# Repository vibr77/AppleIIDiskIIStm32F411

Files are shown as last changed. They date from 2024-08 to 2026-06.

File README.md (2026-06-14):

# SmartDisk II — Apple II Floppy Emulator

**The Apple II floppy emulator that even copy protection can't tell apart.**

Swap a shelf of aging 5.25″ disks for a single SD card — without giving up an ounce of authenticity. SmartDisk II reproduces the exact timing and behaviour of a real DISK II and UNIDISK 3.5 drive, so your games load and run exactly as they did back in the day — protection schemes and all.

<p align="center">
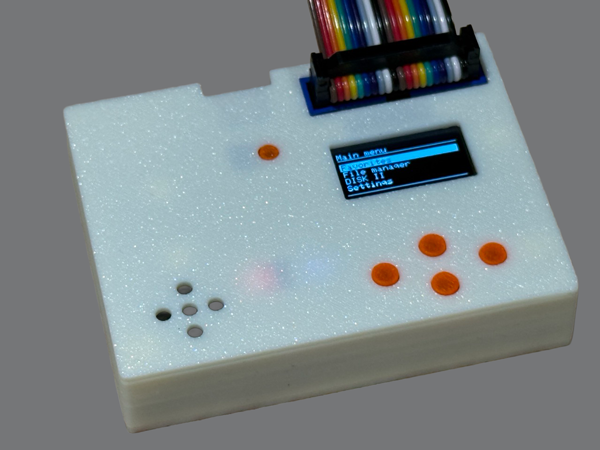
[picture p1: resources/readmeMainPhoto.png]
  
</p>

<p align="center">
  <a href="https://www.ebay.fr/itm/306883712221"><b>🛒 Buy a prebuilt board</b></a> ·
  <a href="https://github.com/vibr77/AppleIIDiskIIStm32F411"><b>🔧 Build it yourself</b></a> ·
  <a href="https://discord.gg/ZnzDqC2k"><b>💬 Join the Discord</b></a> ·
  <a href="https://www.r3tr0.net/index.php/smartdisk-ii-documentation/"><b>📖 Documentation</b></a>
</p>

---

## What is it

SmartDisk II is an **open-source hardware floppy-disk emulator for the Apple II**. It plugs into your machine like a real drive, reads disk images straight from an SD card, and lets you browse and mount them from a built-in OLED menu — no PC, no cables, no fuss.

Under the hood it's built on the **STM32F411 ("BlackPill")** and emulates the disk hardware *at the bit level*. That's the difference between *reading a disk image* and *being a disk drive* — and it's why SmartDisk II runs the titles other emulators choke on.

## Why SmartDisk II

- **Bit-perfect accuracy.** Timing is reproduced down to the microsecond, so the Apple II can't tell it apart from a mechanical drive.
- **It beats copy protection.** Fake bits, weak bits, half-tracks, SpiraDisc and more — it passes every scheme tested so far.
- **Your whole collection on one card.** Thousands of disks on a single SD card, browsable on the on-board OLED.
- **Works across the Apple II line.** From the II+ to the IIGS, Disk II and SmartPort — one device covers your fleet.
- **Read *and* write.** Save your progress and modify disks, not just load them.
- **Open source, or ready to run.** Build it from the published files, or order a prebuilt, flashed board and plug in today.

## Browse and boot — right from the Apple II

With **SmartLoader**, you don't even need the SmartDisk II's own buttons for everyday loading. It puts a fast green-screen browser on the Apple II itself: SmartLoader reads the disk images on your SD card and lists them right on screen, so you can scroll through your whole collection and boot any title straight from the Apple II — highlight a disk, press **[B]** to boot, **[R]** to refresh the listing, or **[S]** for settings.

## Copy protection that actually works

Most emulators fall over the moment a disk uses copy protection. SmartDisk II doesn't. By reproducing the original drive's bit-level timing, it satisfies the protection checks that real software relied on — so your original protected images run untouched.

| Copy protection | Status |
|:---|:---|
| Fat Track | ✅ Passed |
| Weak Bit | ✅ Passed |
| Cross-track synchronisation | ✅ Passed |
| Half Track | ✅ Passed |
| Data Latch | ✅ Passed |
| Timing Bits | ✅ Passed |
| E7 | ✅ Passed |
| Optimal Bit Timing (<4µs) | ✅ Passed |
| Various Bit Counter | ✅ Passed |
| SpiraDisc | ✅ Passed |

## Compatibility

| Apple II model | Emulation |
|:---|:---|
| II+ | Disk II |
| II Europlus | Disk II |
| IIe | Disk II |
| IIc (ROM 4) | Disk II + SmartPort |
| IIGS | Disk II + SmartPort |

SmartPort emulation is also available on the IIc (ROM 4.x), IIGS, and on the II+/IIe with a Liron or SoftSP6 card.

## Supported disk formats

| Format  | Read | Write |
|:---|:-----|:---|
| WOZ 2.0 | ✅ | ✅ |
| DSK | ✅ | ✅ |
| PO | ✅ | ✅ |
| 2MG | ✅ | ✅ |
| WOZ 1.0 | ✅ | — |
| NIC | ✅ | — |

## Features at a glance

- **Three drives in one** — DISK II 5.25″, SmartPort HD, and UNIDISK 3.5 emulation
- **On-board navigation** — browse, mount and unmount images from the 0.96″ OLED with four buttons
- **Big images, no sweat** — 32 MB images and full Total Replay collections run smoothly
- **Modern software too** — loads GS/OS on the IIGS; runs titles like Arkanoid from 2MG
- **SmartLoader** built in — browse and boot from the Apple II screen itself
- **Actively developed** — frequent firmware releases with the latest improvements

## See it in action

- ▶ [Total Replay & 32 MB images, running smoothly](https://www.youtube.com/watch?v=Sws6IjnWDGQ)
- ▶ [Arkanoid, loaded from a 2MG image](https://www.youtube.com/watch?v=U3N-gej0NLk)
- ▶ [Loading GS/OS on the IIGS](https://www.youtube.com/watch?v=gZH2njO4CEQ)

## Get your SmartDisk II

**Buy a prebuilt board.** Don't want to solder? Order a ready-to-use, fully flashed and tested SmartDisk II and plug in today → [Order on eBay](https://www.ebay.fr/itm/306883712221)

**Build it yourself.** Everything you need is open source — KiCad PCB, Gerber files, bill of materials, 3D-printable case, firmware releases and full source code. **Current production board: Revision 8**, recommended for self-builds.

**Get help & follow along.** Join the community on [Discord](https://discord.gg/6y2Zdazy), or read the full development story on [AppleFritter](https://www.applefritter.com/content/apple-ii-disk-emulator-using-stm32).

## Tech specs

- **MCU:** STM32F411 ("BlackPill") — chosen for CPU speed, >60 kB SRAM and 4-bit SDIO
- **Storage:** SD card, FAT32 (4-bit SDIO for speed) — a quality, known-brand card is recommended
- **Display:** 0.96″ OLED (SSD1306) with four-button navigation
- **Board:** Production Revision 8, fully tested
- **Licence:** open source for non-commercial use with attribution

<p align="center">
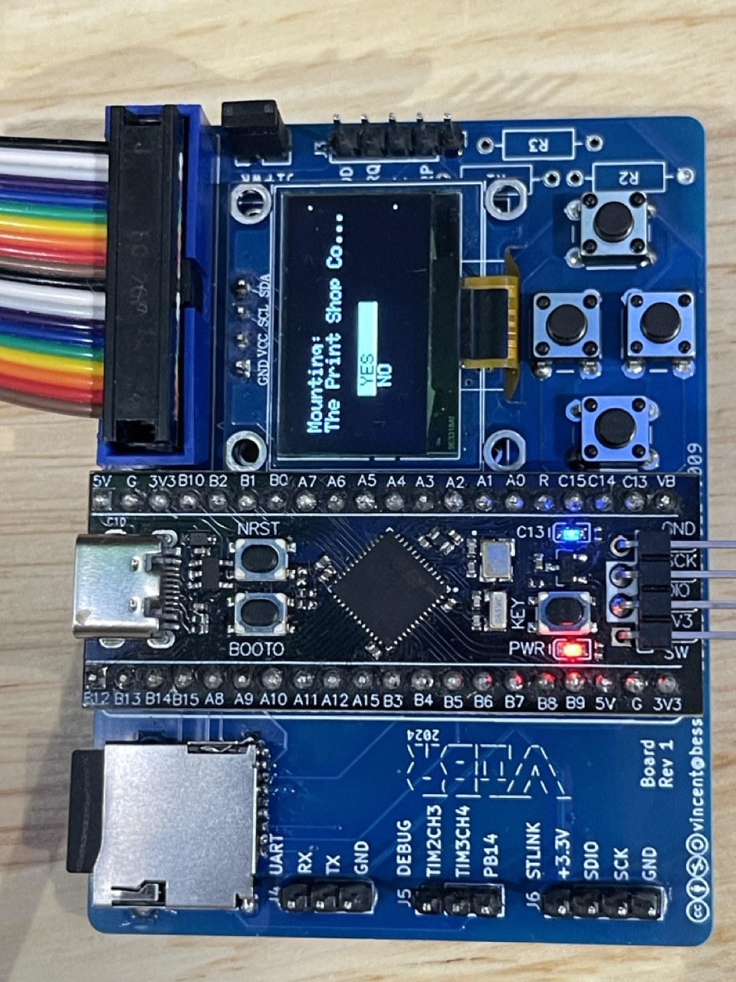
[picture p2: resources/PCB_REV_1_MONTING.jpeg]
  
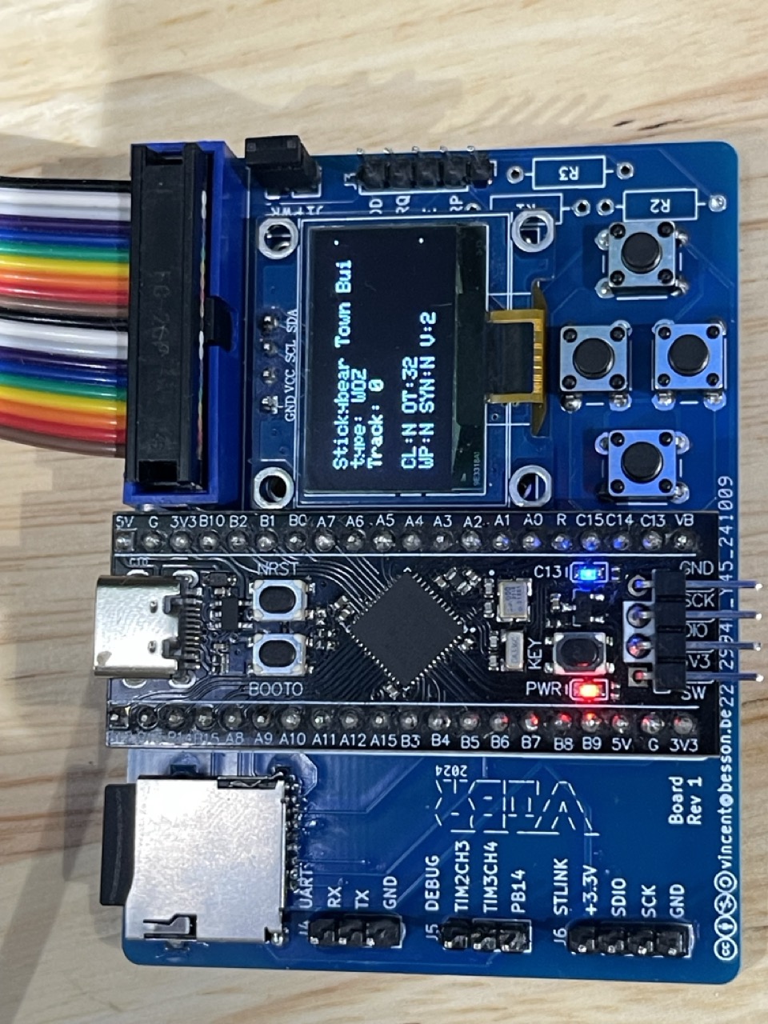
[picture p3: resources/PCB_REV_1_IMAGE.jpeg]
  
</p>

---

# Build & developer guide

Everything below is for people building, flashing, or hacking on the SmartDisk II. The full end-user manual (wiring, SD-card prep, menu walkthrough) lives in the [online documentation](https://www.r3tr0.net/index.php/smartdisk-ii-documentation/).

## Firmware

The latest firmware (see the releases on the right-hand side of the GitHub page) requires **bootloader v0.14 or v0.16**. Version 0.15 is **not** compatible and causes issues with the IIGS SmartPort. It is recommended to update the bootloader to the latest version.

There are two release types:

- **BIN** — classic binary, uploaded via ST-Link, starting at `0x08000000`.
- **UF2** — first upload the custom bootloader via ST-Link, then connect USB and double-click the NRST button to drag-and-drop the UF2 release onto the STM32. **Warning:** with the bootloader, flash from `0x08000000` to `0x08100000` becomes read-only (use ST-Link tooling to change the STM32 register to reverse this).

## Project structure

| Directory | Description |
|:---|:---|
| `./hardware` | KiCad project |
| `./hardware/gerber`  | Gerber release to produce the PCB |
| `./hardware/bom` | Bill of materials |
| `./core` | Firmware source code |
| `./bootloader` | Bootloader |
| `./Middleware` | Libraries used |
| `./FATFS` | FATFS wrapper |
| `./doc` | Documentation used as reference |
| `./3DPrintCase` | 3D-print files & Fusion 360 source for the case |

## SD card

The SD card must use a **FAT32 file system with 64 sectors of 512 bytes each per cluster (32 KB clusters)**.

To format the card under Linux:

```bash
mkfs.fat -F 32 -s 64 /dev/sdX
```

Windows 10/11 does **not** format the card the right way. A config-menu option is provided directly on the SmartDisk II to format the SD card correctly. Note that some SD cards have very poor read/write rates — use a known brand to avoid wasting your time.

## Important notes

- The ST-Link programmer should **never** be connected at the same time as either USB or the Apple II — its voltage regulator is fragile.
- The **J1 PWR** jumper (top-right of the PCB) enables +5 V from the Apple II to the STM32.
- OLED screen: be careful of the power-pin order; some versions have the pins inverted.
- R1, R2, R3 are not needed.
- Before hardware Rev 3, the board is not compatible with the IIGS & IIc — the trace between IDC pins 5 & 7 needs to be cut.
- Hardware design may evolve; new software releases might not work with older hardware revisions.

## Hardware design principles

The STM32F4x is preferred over the STM32F1 for CPU frequency, available SRAM (>60 kB), and (on the F411) SDIO. Timing is critical on this project, especially to pass copy protection.

A DISK II floppy track is about 50,000 bits, and shifting from one track to another must respect specific timing rules. After many design iterations, the chosen approach loads a **single track in memory** and uses the **4-bit SDIO port** for SD card read/write speed — avoiding adjacent-track management and complex buffer copies.

The Apple II expects data at a precise pace of **1 bit every 4 µs (32 × 125 ns)**. Three options were considered:

1. SDIO with DMA — frees the CPU, but SPI sends 8 bits at a time; WOZ tracks aren't 8-bit aligned, which introduces bit misalignment and corrupted data on protected images.
2. Assembly with CPU-cycle counting & GPIO bit-banging — poor reliability, discarded.
3. **Timer-interrupt-triggered GPIO bit-banging (chosen)** — frees CPU time for OLED updates and button handling, makes fake-bit/protection mechanisms easy to address, and allows fine timing control (e.g. 3.8 µs vs 4 µs that some games use).

The write process mirrors the read process with a dedicated timer overflowing every 4 µs; polarity inversion is handled in software with an XOR rather than external circuitry.

### STM32 pin mapping

**Head-positioning stepper (external interrupts):**
`PA0` STEP0 / ExtI0 · `PA1` STEP1 / ExtI1 · `PA2` STEP2 / ExtI2 · `PA3` STEP3 / ExtI3

**Other GPIO:**
`PB8` SELECT (ExtI8, HIGH on Disk II controller — A2 powered on) · `PB9` WR Request (ExtI9, active LOW when writing) · `PA4` Device Enable (ExtI4, active LOW) · `PB2` WR Protect · `PA7` WR Data · `PB0` RD Data · `PA11` _DISK3.5

**Buttons (ExtI 9-15, TIM4 debounce):**
`PC13` BTN_DOWN · `PC14` BTN_UP · `PC15` BTN_ENTR · `PB12` BTN_RET

**SD card (SDIO, clock ÷2):**
`PB4` D0 · `PA8` D1 · `PA9` D2 · `PB5` D3 · `PA6` CMD · `PB15` CK

**OLED SSD1306 (I²C):** `PB6` SCL · `PB7` SDA

**UART:** `PA15` TX · `PB3` RX

**Timers:**
- **TIM2** — manages WR_DATA; ETR1 slave-reset mode resyncs with the Apple II write pulse (3.958 µs instead of 4 µs) on every rising edge.
- **TIM3** — manages RD_DATA.
- **TIM4** — internal (no PWM), debouncer for the control buttons.

## Software design principles

Built on:

- STM32 HAL drivers from STMicro
- FATFS 0.15 (note: STM32CubeMX overrides to 0.11)
- cJSON for the configuration file (tweaked to work with FATFS)
- SSD1306 library with DMA

Maximum track size is `13 × 512 × 8 = 53,248` bits (6,656 bytes), held in `DMA_BIT_TX_BUFFER[6656]`. `weakBitTank` (uint8 array) and `fakeBitTank` (char array) manage copy-protection mechanisms.

**Key functions:**

- `TIM3_IRQHandler` — bit-bangs the GPIO to send track data every 4 µs (or less, per WOZ config) to the Apple II.
- `TIM2_IRQHandler` — handles data sent from the Apple II for writing; uses a software XOR to detect polarity inversion and writes 1/0 to `DMA_BIT_RX_BUFFER`.
- `irqReadTrack` / `irqWriteTrack` — configure read/write interrupts.
- `getDataBlocksBareMetal(...)` / `setDataBlocksBareMetal(...)` — direct SDIO access to the SD card, faster than FATFS `f_open`. (FATFS is still required to build the file allocation table with correct block addresses.)
- `processDeviceEnableInterrupt` — activates/deactivates the Disk II drive on the DEVICE_ENABLE pin (active LOW).
- `processBtnInterrupt` — handles the four buttons.
- `processDiskHeadMoveInterrupt(...)` — handles the four stepper-motor GPIOs.
- `main()` — orchestrates program execution.

A **ST-Link** programmer is required to upload firmware to the STM32F411.

## Bill of materials

Interactive BOM: [SmartDisk II Bill of Material](https://vibr77.github.io/AppleIIDiskIIStm32F411/hardware/bom/ibom.html)

## Recommended reading

WOZ 2.1 & 1.0 image file references · Tome of Copy Protection · Beneath Apple DOS · Assembly Lines · Understanding the Apple II · PoC‖GTFO issues 10 & 11 · IIGS Firmware Reference · IIc Programmer's Guide to the 3.5 ROM (part 2)

## Licence

This project may be distributed, remixed, adapted and built upon, in any medium or format, **for non-commercial purposes only**, and only with attribution to the creator. Commercial rights are reserved to the author.

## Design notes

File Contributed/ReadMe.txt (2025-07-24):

### VIBR SmartDisk II - Apple II forever modification ###

https://youtube.com/shorts/TgZ5UqMbQsM

https://github.com/joergschne/AppleIIDiskIIStm32F411

https://developer.arm.com/downloads/-/arm-gnu-toolchain-downloads

export PATH="/Applications/ArmGNUToolchain/13.3.rel1/arm-none-eabi/bin:$PATH"

Download mandatory STM32F4xx driver at: https://www.st.com/en/development-tools/stm32cubemx.html

# Driver/BSP
# Driver/CMSIS
# Driver/STM32F4xx_HAL_Driver

Build with Apple II forever mode: make -f Makefile USE_BOOTLOADER=1 A2F_MODE=1 

# python uf2conv/uf2conv.py -b 0x08010000 -f STM32F4 -o build/AppleIISDiskII_stm32f411_sdio.uf2 build/AppleIISDiskII_stm32f411_sdio.bin

BOM:
https://shop.lcd-module.de/128x64-OLED-YELLOW/OLEDM128-6LGA
or
https://shop.lcd-module.de/OLED128x64green-COG/W128064-XALE

1	311-1344-1-ND			CC0603KRX7R9BB104	CAP CER 0.1UF 50V X7R 0603		1
2	478-1655-1-ND			TAJA106K016RNJ		CAP TANT 10UF 10% 16V 1206		3
3	732-2096-ND			61202021621		CONN HEADER VERT 20POS 2.54MM		2
4	296-SN74LS257BDRCT-ND		SN74LS257BDR		IC MULTIPLEXER 4 X 2:1 16SOIC		1
5	4809-RKJXT1F42001-ND		RKJXT1F42001		SWITCH JOYSTICK ANALOG 10MA 5V		1
6	664-GMC020080HRCT-ND		GMC020080HR		CONN SD/MMC/MS CARD R/A SMD		1
7	102-1266-1-ND	CT-1205H-SMT-TR	BUZZER MAGNETIC 5V 12.8X12.8 SMD				1
8	311-10KLGCT-ND	AC0805FR-0710KL	RES SMD 10K OHM 1% 1/8W 0805					12
9	13-AC0805FR-07910KLCT-ND	AC0805FR-07910KL	RES SMD 910K OHM 1% 1/8W 0805		1
10	P12937SCT-ND			EVQ-Q2F03W		SWITCH TACTILE SPST-NO 0.02A 15V	4
11	MICRO SD-CARD SMD		GCT-MEM2055-00-190-01-A_VIB					1
12	LED 5 mm
13	Buchsenleisten 2,54 mm
14	Flachbandkabel und 20P Pfosten-Steckverbinder
15	STM32F411 (Black Pill) Board

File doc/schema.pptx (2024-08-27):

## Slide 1

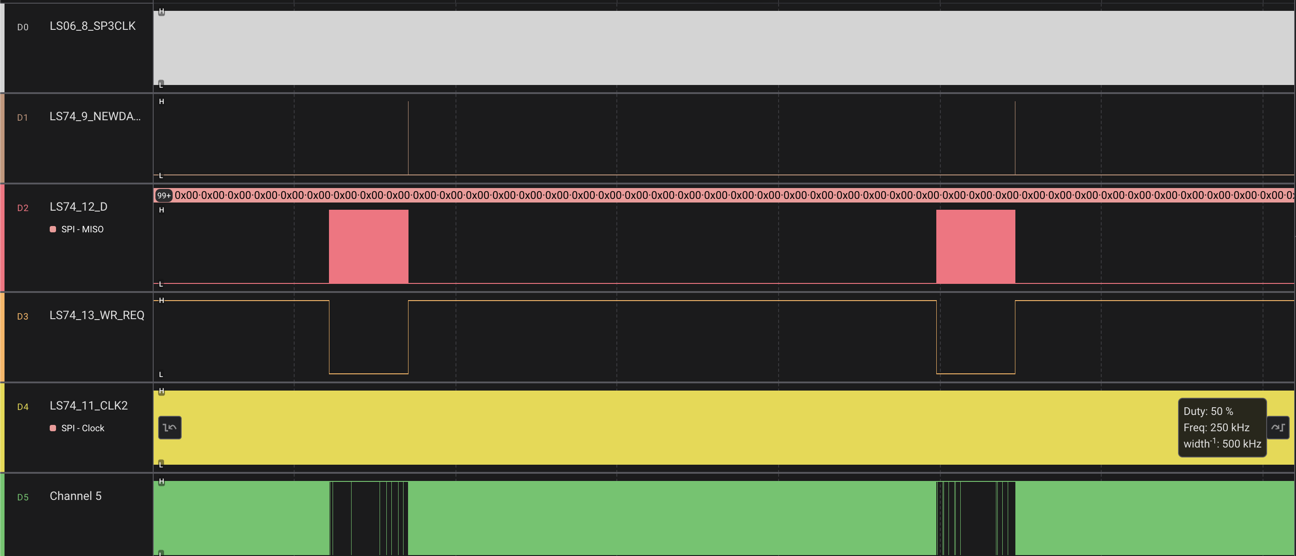
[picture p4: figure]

WRITE ZONE

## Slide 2

DMA CIRCULAR RDDATA BUFFER

DMA CIRCULAR WRDATA BUFFER

DESTINATION
Of WRDATA

B

A

WRDATA

C

D

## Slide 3

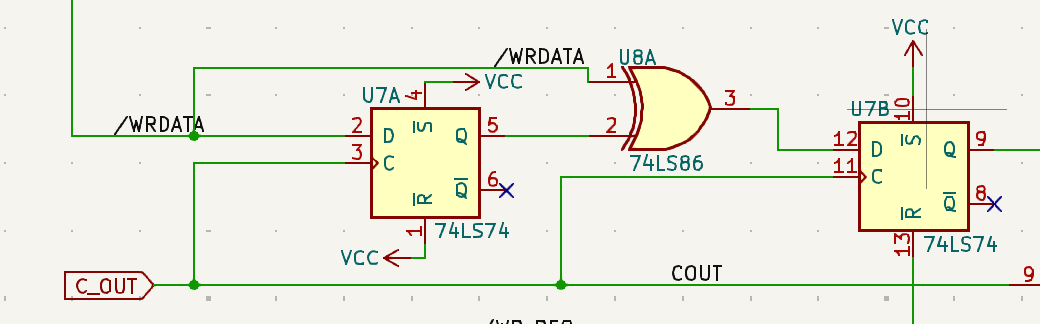
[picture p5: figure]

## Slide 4

Case A1: RX_E > RX_S && TX_E > TX_S

DMA_RX

0

RX_S

P1

RX_E

DMABSIZE

P1=memcpy(DMA_TX+TX_S,DMA_RX+RS_S,RX_LEN)

Case B2_1: RX_E < RX_S && TX_E < TX_S

RX

0

TX

0

RX_E

P3

RX_S

P1

A

P2

end_tx_len

DMABSIZE

end_tx_len=DMABSIZE-TX_E
P1=memcpy(DMA_TX+TX_S,DMA_RX+RX_S, end_tx_len)
Rx_offset=RX_S+ , end_tx_len
P2=memcpy(DMA_TX,DMA_RX+RX_offset,DMABSIZE-rx_offset)
Tx_offset=DMABSIZE-rx_offset
P3=memcpy(DMA_TX+tx_ofset,DMA_RX,RX_E)

DMA_TX

0

TX_S

P1

TX_E

DMABSIZE

P2

A

TX_E

P3

TX_S

P1

Case A2: RX_E>RX_S && TX_E < TX_S

RX

0

TX

0

RX_S

end_tx_len

P1

A

RX_E

end_tx_len=DMABSIZE-TX_S
P1=memcpy(DMA_TX+TX_S,DMA_RX+RX_S, end_tx_len)
P2=memcpy(DMA_TX,DMA_RX+end_tx_len, TX_S)

DMABSIZE

TX_E

P2

TX_S

P2

end_tx_len

P1

DMABSIZE

Case B2_2: RX_E < RX_S && TX_E < TX_S

RX

A

RX_E

RX_S

end_rx_len

P1

DMABSIZE

TX

0

P2

TX_E

P3

P3

TX_S

A

DMABSIZE

Case B1: RX_E < RX_S && TX_E < TX_S

RX

0

TX

0

RX_E

RX_S

end_rx_len

0

P1

P2

DMABSIZE

P2

P1

DMABSIZE

end_rx_len=DMABSIZE-RX_S
P1=memcpy(DMA_TX+TX_S,DMA_RX+RX_E, end_rx_len)
P2=memcpy(DMA_TX+TX_S+end_rx_len,DMA_RX, RX_E)

end_rx_len=DMABSIZE-RX_S
P1=memcpy(DMA_TX+TX_S,DMA_RX+RX_S, end_rx_len)
Tx_offset=DMA_TX+TX_S+end_rx_len
P2=memcpy(DMA_TX+tx_offset,DMA_RX,DMABSIZE-tx_offset)
Rx_offset=DMABSIZE-tx_offset
P3=memcpy(DMA_TX,DMA_RX+Rx_offset,RX_E)

TX_S

end_rx_len

P1

A

TX_E

P2

DMABSIZE

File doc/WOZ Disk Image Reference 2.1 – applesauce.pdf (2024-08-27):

ABOUT (https://applesaucefdc.com/what-is-applesauce/) | HARDWARE (https://applesaucefdc.com/hardware/) | SOFTWARE (https://applesaucefdc.com/software/) | DOCUMENTATION (https://wiki.applesaucefdc.com/) | A2R (https://applesaucefdc.com/a2r/) | WOZ (https://applesaucefdc.com/woz/) | MOOF (https://applesaucefdc.com/moof-reference/) | ORDER (https://applesaucefdc.com/order/) | CONTACT (https://applesaucefdc.com/contact/)

# WOZ Disk Image Reference 2.1

Created by John K. Morris
jmorris@evolutioninteractive.com

Version 2.1 – June 16, 2021

Version 1.0 of the WOZ Disk Image Reference can be found here. (https://applesaucefdc.com/woz/reference1/)

Many thanks to the people who helped me prepare this document for release:
John Brooks, David Brown, Bill Martens, Sean McNamara, Antoine Vignau, Olivier Galibert and 4am

## Why yet another Apple II disk image format?

This is probably the question many of you reading this document are asking. It basically comes down to the simple fact that none of the currently existing formats accurately represent the way data is encoded on an Apple II floppy disk. There is a place for a format that is an accurate representation of a bitstream that is also the exact length of a track so that it can be looped correctly. And since we are creating a format, it is also a great time to ensure that we organize the data in the image file in a way that allows for easy unpacking with as little memory and processing overhead as possible – this provides more performant usage in hardware and software emulators.

## What benefits come with using the WOZ format?

We seem to be doing just fine with the current file formats, why would we want to support the WOZ format? The big benefit is being able to successfully run copy protected software if you follow the emulation guidelines presented in this document. The second benefit is that the WOZ format is actually much simpler to implement than many of the other disk image formats. WOZ files also contain metadata about the disk image – such as disk name, product name, publisher, system requirements and language – that you can use to display additional information in your emulator.

## What has changed in the WOZ specification for the 2.1 release?

The 2.1 update has been created in order to support tracks that are captured at a level even lower than bits. It is now able to support flux transition timings with an accuracy of 125 nanoseconds. I refer to this as a flux stream. In order to support this additional type of data, a new FLUX chunk has been added along with a bump to the INFO chunk version (from 2 to 3) and 2 new fields (FLUX Block and Largest Flux Track). I expect that there will be very few disks that need to utilize this level of accuracy, but we have already discovered at least a dozen disks that need this for their copy protection to succeed. A description of how the flux data is encoded and stored in the TRKS chunk can be found in the TRKS section of this spec. There is also a new FLUX Chunk section that describes the new chunk type that was created in order to map flux-based track data to physical tracks (practically identical to the TMAP Chunk).

## What has changed in the WOZ specification for the 2.0 release?

After releasing Applesauce, the flood of software began that has enabled a lot of validation of the WOZ format. Unfortunately, a few short comings were uncovered with the initial format. There were also some requests made to improve the format. This document details the 2.x specification. The 2.0 format is intended to be a replacement of the 1.0 format.

File Header Changes

The file identifier (bytes 0-3 of the file) was changed from WOZ1 to WOZ2. This was done since there are a couple of fundamental changes made to the format and we need to make sure that new WOZ 2.0 files are only consumed by hardware and software that is explicitly compatible with these changes.

INFO Chunk Changes

New INFO fields are indicated by the “2” in the Vers field in the INFO Chunk section of this document.

There are now flags for indicating whether track 0 contains boot sectors for 16 and/or 13 sector hardware. The Apple disk controller card contains a ROM (P5) that performs the task of bootstrap loading track $00 sector $0 from the disk and running it. This is what happens when you reboot your machine or use PR#6. The code contained within that boot sector is then responsible for loading up the rest of the disk. When Apple originally came out with the Disk II, it only dealt with 13-sector disks and 5&3 nibble encoding. When you booted the computer, the P5 ROM would look for the boot sector by identifying an address prolog with the nibble values D5 AA B5. Later on, with DOS 3.3, Apple introduced the 16-sector format along with 6&2 nibble encoding. This new format also needed a revised P5 ROM, known as the P5A. Since the two formats aren’t compatible with each other, they chose to change the default address prolog nibbles to D5 AA 96. The problem with this is that disks in one format are basically invisible to disks and hardware using the other format since they aren’t looking for the correct address prolog. The WOZ format now contains a Boot Sector Format indicating whether a boot sector exists for 13 and/or 16 sector ROMs. This can help emulators detect which ROM is needed when booting a disk.

The Optimal Bit Timing is now provided. This value dictates the rate at which bits should be provided to the disk controller card. There are a several disks that use slightly non-standard bit timings. Most of these work just fine under emulation, but many of these disks load faster if the bits are provided at the correct speed. This value is in 125 nanosecond increments, so 8 is equal to 1 microsecond. And a standard bit rate for a 5.25 disk would be 32 (4µs), and a 3.5 would be 16 (2µs).

Another feature requested by emulator developers was to hoist some of the compatible hardware values from the META chunk and place it into the INFO chunk in an easier to parse format. So, there is now a Compatible Hardware bit field as well as a Required RAM one.

A Largest Track field was added in order to help emulators allocate a properly sized buffer for storing track data.

TMAP Chunk Changes

The order of the TMAP data for 3.5 disks has changed to make it more efficient to find the proper offset ((track << 1) + side). The TMAP chunk is unchanged for 5.25 disks.

TRKS Chunk Changes

It turns out that there was a trick that was more effective than I thought possible. Most 5.25 disks end up using about 6300-6500 bytes of data per track, but this all depends on the speed of the drive when writing the disk. I allocated 6646 bytes to each track to make sure there was a good pad in there for disks that were purposely written at a slower speed to pack more data on a track. It seems like some disks (I’m looking at you Datasoft) had things turned down even more and were able to fit an amazing 6680 bytes of data on a track. This broke the WOZ track size limit by 34 bytes.

The TRKS chunk was modified in order to allow a variable number of 512-byte blocks to be allocated for each track. This will allow the WOZ format to remain as small as possible for “normal” 5.25 disks, but also be able to accommodate ones with larger track data requirements. This also allows for more optimal storage for 3.5 disks as each speed zone can have the track size tuned for it.

The write hints have also been removed from the TRKS chunk and moved to their own WRIT chunk.

WRIT Chunk Addition

A new WRIT chunk has been added to the WOZ specification in order to provide detailed instructions for programs wanting to write WOZ files back to a real floppy disk. Inclusion of this chunk in a WOZ file is optional.

Freaking Out Like a MC3470 Changes

Due to some new findings in the analysis of MC3470, there is a new recommended implementation that should more accurately model the proper behavior.

## Implementation Details

Integrating WOZ support with your product is more than just loading data from a new type of container. It is also about how that data is used. Yes, it is possible to just shovel bits from the WOZ right into your bitstream, and many disk images will work just fine like that. But, by taking the following guidelines into account, your implementation will enable disk functionality that is also compatible with all copy protection schemes. Yes, this means you can run copy protected software in system and disk drive emulators without the need to crack it first!

Cross-Track Synchronization

When Steve Wozniak was hacking up Shugart drives to make the Disk II, one of the parts that he threw away was the sync sensor. The sync sensor involved a light source on one side of the disk with a sensor on the other. This sensor would allow the drive to know when it made a full revolution, as the disk media itself had a hole that would let the light pass though as it passed the sensor. It really wasn’t a necessary part for Wozniak’s soft-sectored design that was going to be used for storing data on the disk.

A NORMAL UNSYNCHRONIZED DISK VS A SYNCHRONIZED ONE.

When it came to businesses designing copy protection schemes, this was something that they could use to their advantage. The professional disk copiers could easily write out all tracks synchronized with each other, something that your average Apple II floppy drive couldn’t do. Then, the software would read a known sector on a specific track and, when it jumped to a neighboring track, it could make sure that the first sector it encountered there was the one it expected. Later protection schemes even made track widths which were almost 2 standard tracks wide and were accurate to within 1 bit. As much as the disk copy programs tried, they could only sync up tracks by sheer luck.

To circumvent these kind of copy protection checks, the WOZ format uses a Track Map (see the “TMAP Chunk” section below). This allows us to assign a track image to any number of quarter tracks on a disk. An entire disk could even be a single track if we wanted.

There are a couple of rules to follow with regards to changing tracks within the emulator:

Firstly, if the tracks you are changing between have matching values in the TMAP, then don’t change the track data. This will prevent any hiccups in the bitstream and can be a good performance gain to boot.

The second rule is that you need to maintain a bit pointer into your bitstream. You always need to know which bit you are on. When you do change tracks, you need to start the new bitstream at the same relative bitstream position – you cannot simply start the pointer at the beginning of the stream. You need to maintain the illusion of the head being over the same area of the disk, just shifted to a new track.

Also be sure to account for the fact that track lengths are inconsistent on a disk due to fluctuations in drive speed. Something like this works well to maintain the relative position if your environment can work with 32-bit or greater values:

new_position = current_position * new_track_length / current_track_length

Remember to maintain the bit position even when on an empty track (TMAP value of 0xFF). Since the empty track has no data, and therefore no length, using a fake length of 51,200 bits (6400 bytes) works very well.

Freaking Out Like a MC3470

On the Apple II, floppy disk data is written to the disk based on a 4µs clock. Whenever there is a 1 bit to write, the polarity of the magnetic flux under the drive head is transitioned from its current state to the opposite. If a zero needs to be written out, the 4µs clock is skipped (no transition occurs).

The MC3470 chip is the heart of the Apple II floppy drive. It reads the magnetic flux pattern off the disk and sends out a pulse for every flux transition it sees. This gives us back our 1 bits and our 0 bits come from the 4µs clock going by with no pulse.

One of the nice features of the MC3470 is that it has an internal amplification system to adapt to the varying magnetic strengths of each disk. If it has a hard time reading the disk, it can turn up its amp until it finds the signal. It allows the drive to read a wide assortment of disks. The Apple II uses GCR encoding to store bits on the disk. It is a very efficient system that was used widely on many platforms, because it doesn’t use clock bits to frame up your data bits, giving you more room to write data. This technique also has a drawback though, which is never being able to record more than two 0 bits in a row. It is why data on an Apple II is stored as nibbles instead of plain binary bytes.

One very popular copy protection is referred to as “fake bits” or “weak bits” – this technique is actually an exploit against the MC3470. It comes from the idea of what happens when we make it read more than two 0 bits in a row. What happens is that our poor MC3470 thinks that it is doing a bad job reading the disk and keeps trying to turn up its amp to find the flux signal. It does this until it gets to the point that it amplifies background electrical noise so much that it thinks that it sees a transition and sends out a false pulse, which the computer happily records as a 1 bit.

So, how can this failure be used as copy protection? The software developers simply put these blank fake bit areas on the disk where the software knows where to find them. It then reads some good nibbles followed by the fake bits area. This gives us some good nibbles followed by some random valued nibble. This in itself is not particularly useful until you do it multiple times and see that the random nibble changes every time you read it! If the value keeps changing, then you know that it isn’t a copy of the disk. How does it know that? Because programs like Copy II+ and Locksmith will read those same good nibbles followed by the random nibble, and then they will promptly write out all of the nibble values that they captured, thinking that they are all good. The random nibble is no longer random, it will never change from the value that has been captured, and now the copy protected software will know that it is actually a copy.

So how does the WOZ format deal with this? Well, the first part of the problem isn’t taken care of within the WOZ format itself. The WOZ format is an offshoot of the Applesauce Floppy Drive Controller project. The Applesauce has a way to determine when it is seeing these fake bits and changes the fake bits back to the 0 bits that existed on the original disk.

Now that we are back to having long runs of 0s in the bitstream, we now need to emulate the MC3470 freaking out about them. There are a couple factors that come into play with making an accurate representation of this behavior. For those of you familiar with the WOZ 1.0 specification, this recommended implementation behavior has changed.

The first factor is that there is a latency of up to 5µs from when the head sees a real transition to when it passes through the MC3470 filter, differentiator, pulse generator and finally sent out as a pulse. But it appears that fake transitions have a much shorter latency. Due to this, fake bits are introduced earlier into the pulse stream than you would expect. The second factor is to remember that the read head is an analog device and isn’t reading a single point on the disk surface, but actually one that has a radius of about 7.5µs. As long as it has a flux within its window, either coming or going, it remains happy. It is when there is nothing in this windows that it starts freaking out. This means that we are definitely in our happy place with two 0 bits as the interval between them is 12µs (vs the window diameter of 15µs). Even three 0 bits is fairly safe with an interval of 16µs (only needs to deal with 1µs of starting to freak out), but this will sometimes throw a fake bit.

So, knowing these things, the recommended way to implement this behavior is to maintain an 4-bit wide buffer for the bits coming out of the WOZ file. Every time a new bit needs to be outputted, shift the buffer left 1 bit and put the next bit from the WOZ into bit 0 of the buffer. Then send the value in bit 1 of the buffer. This will give us our desired latency. So, how do we know when to send in the random fake bits? If the value of our buffer is 0, then we randomly output a bit instead of sending bit 1.

uint8_t head_window = 0;

uint8_t nextDiskBit() {
head_window <<= 1;
head_window |= getNextWozBit();
if ((head_window & 0x0f) != 0x00) { return (head_window & 0x02) >> 1; } else {
return fakeBit();
}
}

Of course, coming up with random values like this can be a bit processor intensive, so it is adequate to create a randomly-filled circular buffer of 32 bytes. We then just pull bits from this whenever we are in “fake bit mode”. This buffer should also be used for empty tracks as designated with an 0xFF value in the TMAP Chunk (see below). You will want to have roughly 30% of the buffer be 1 bits.

When Off Isn’t Really Off

Turning on the floppy drive motor and getting the disk up to its 300 RPM speed isn’t a particularly fast operation. When it came to DOS, it used a simple mechanism to read a file: turn disk on, read data, turn disk off. This turned out to be a fairly slow process as it kept needing to spin up the disk when you were accessing multiple files. So, a simple hardware optimization was created that would use a timing circuit to delay the turning off of the motor for a period of 1 second. This way if you were reading a bunch of files in a row, the motor wouldn’t actually turn off between them and you could access the files much quicker. Pretty clever!

When it came to the copy protection arms race, a mechanism as clever as this would of course end up being weaponized. In order to discourage people from boot tracing their software, several protections took to the idea of turning off the floppy drive motor before trying to read some sectors. The developers knew that the disk would still have almost 5 full revolutions before actually turning off, so it wasn’t a problem. But, if the crackers stopped program execution in this area, then they would lose access to the next sectors being read since the drive would turn off automatically after 1 second.

Therefore, a 1 second delay after accessing the “drive motor off” soft-switch at $C088,X needs to be implemented to allow software to continue reading sectors.

Abusing Disk Controller Soft Switches for Fun and Profit

The floppy drive is accessed by using the soft switches associated with the floppy disk controller card. These are in the range $C0x0-C0xF, with the value of x being $8 + the slot number. All of these switches have a specific function like turning the motor on/off, reading/writing data, or controlling the head stepper motor phases. But due to the way the circuit was laid out on the disk controller card, they also have some unexpected behaviors. Many copy protection schemes relied on these undocumented side effects.

As referenced in the previous section, when you access $C088,X it begins the timer to turn off the drive motor. But, it also returns the value of the data latch! Why would it do that?!? It does this for one simple reason, the low bit of the address line (A0) is connected through a NOT gate to the Output Enable line of the data latch. Therefore every soft switch on an even address should actually return the value of the data latch.

Another nuance that needs to be implemented is that reading $C08D,X will reset the sequencer and clear the contents of the data latch. This is used to great effect in the E7 protection scheme to resynchronize the nibble stream to make timing bits become valid data bits.

## WOZ File Format Specification

A WOZ file uses a chunk-based file binary format that provides future-proof expandability in a way that is safe for older software which may not recognize newer data chunks.

All data is stored little-endian.

WOZ files begin with the following 12-byte header in order to identify the file type as well as detect any corruption that may have occurred. The easiest way to detect that a file is indeed a WOZ file is to check the first 8 bytes of the file for the signature. The remaining 4 bytes are a CRC of all remaining data in the file. This is only provided to allow you to ensure file integrity and is not necessary to process the file. If the CRC is 0x00000000, then no CRC has been calculated for the file and should be ignored. The exact CRC routine used is shown in Appendix A, and you should be passing in 0x00000000 as the initial crc value.

Byte | Value | Purpose
0 | 57 4F 5A 32 | The ASCII string ‘WOZ2’. 0x325A4F57
4 | FF | Make sure that high bits are valid (no 7-bit data transmission)
5 | 0A 0D 0A | LF CR LF – File translators will often try to convert these.
8 | xx xx xx xx | CRC32 of all remaining data in the file. The method used to generate the CRC is described in Appendix A.

After the header comes a sequence of chunks which each contain information about the disk image. Using chunks allows for the WOZ disk format to provide forward compatibility as chunks can be added to the specification and will just be safely ignored by applications that do not care (or know) about the information. For lower-performance emulation platforms, the primary data chunks are all located in fixed positions so that direct access to data is possible using just offsets from the start of the file.

All chunks have the following structure:

Offset | Size | Name | Usage
+0 | 4 bytes | Chunk ID | 4 ASCII characters that make up the ID of the chunk
+4 | uint32 | Chunk Size | The size of the chunk data in bytes.
+8 | … | Chunk Data | The chunk data.

To process the file, you start at the first Chunk ID which will be located at byte 12 of the file, immediately following the header. You read the Chunk ID and the Chunk Size following it. If you want to process this chunk, then your file pointer will be at the start of the data. If you don’t care about this chunk, then skip the number of bytes as Chunk Size indicates and you will now be at the next Chunk ID.

while(data_stream.availableToRead() > 8) { uint32_t chunk_id = data_stream.readU32(); uint32_t chunk_size = data_stream.readU32(); switch(chunk_id) {
case INFO_CHUNK_ID:
// read the INFO chunk
break;
case TMAP_CHUNK_ID:
// read the TMAP chunk
break;
case TRKS_CHUNK_ID:
// read the TRKS chunk
break;
case META_CHUNK_ID:
// read the META chunk
break;
default:
// no idea what this chunk is, so skip it data_stream.skip(chunk_size);
}
}

INFO Chunk

The first chunk in an Applesauce file is always an ‘INFO’ chunk. This contains some fundamental information about the contained image. The data of the ‘INFO’ chunk begins at byte 20 of the file and is 60 bytes long (pad chunk with zeros to full length).

Byte | Offset | Type | Vers | Name | Usage
12 | | uint32 | | ‘INFO’ Chunk ID | 0x4F464E49
16 | | uint32 | | Chunk Size | Size is always 60.
20 | +0 | uint8 | 1 | INFO Version | Version number of the INFO chunk. Current version is 3.
21 | +1 | uint8 | 1 | Disk Type | 1 = 5.25, 2 = 3.5
22 | +2 | uint8 | 1 | Write Protected | 1 = Floppy is write protected
23 | +3 | uint8 | 1 | Synchronized | 1 = Cross track sync was used during imaging
24 | +4 | uint8 | 1 | Cleaned | 1 = MC3470 fake bits have been removed
25 | +5 | UTF-8 32 bytes | 1 | Creator | Name of software that created the WOZ file. String in UTF-8. No BOM. Padded to 32 bytes using space character (0x20). ex: “Applesauce v1.0 ”
57 | +37 | uint8 | 2 | Disk Sides | The number of disk sides contained within this image. A 5.25 disk will always be 1. A 3.5 disk can be 1 or 2.
58 | +38 | uint8 | 2 | Boot Sector Format | The type of boot sector found on this disk. This is only for 5.25 disks. 3.5 disks should just set this to 0. 0 = Unknown 1 = Contains boot sector for 16-sector 2 = Contains boot sector for 13-sector 3 = Contains boot sectors for both
59 | +39 | uint8 | 2 | Optimal Bit Timing | The ideal rate that bits should be delivered to the disk controller card. This value is in 125 nanosecond increments, so 8 is equal to 1 microsecond. And a standard bit rate for a 5.25 disk would be 32 (4µs).
60 | +40 | uint16 | 2 | Compatible Hardware | Bit field with a 1 indicating known compatibility. Multiple compatibility flags are possible. A 0 value represents that the compatible hardware list is unknown. 0x0001 = Apple ][ 0x0002 = Apple ][ Plus 0x0004 = Apple //e (unenhanced) 0x0008 = Apple //c 0x0010 = Apple //e Enhanced 0x0020 = Apple IIgs 0x0040 = Apple //c Plus 0x0080 = Apple /// 0x0100 = Apple /// Plus
62 | +42 | uint16 | 2 | Required RAM | Minimum RAM size needed for this software. This value is in K (1024 bytes). If the minimum size is unknown, this value should be set to 0. So, a requirement of 64K would be indicated by the value 64 here.
64 | +44 | uint16 | 2 | Largest Track | The number of blocks (512 bytes) used by the largest track. Can be used to allocate a buffer with a size safe for all tracks.
66 | +46 | uint16 | 3 | FLUX Block | Block number where the FLUX chuck resides relative to the start of the file. A FLUX chunk always occupies its own block. If this WOZ does not utilize a FLUX chunk, then this value will be 0. When checking for the existence of a FLUX chunk, make sure that BOTH this value and the next one (Largest Flux Track) are non-zero.
68 | +48 | uint16 | 3 | Largest Flux Track | The number of blocks (512 bytes) used by the largest flux track. Can be used to allocate a buffer with a size safe for all tracks.

The chunk is versioned to allow for adding additional info in the future. The “Vers” column in the table above indicates at which version the data field became available. When reading data from the chunk, make sure that value you are looking for actually exists within the version of the chunk you are reading. To be sure that your woz loading is future proof, use >= when checking the INFO Version field. The INFO chunk will always be upgraded in a safe way for older consumers.

TMAP Chunk

The ‘TMAP’ chunk contains a track map. This allows you to map physical drive tracks with the track data contained within the image file ‘TRKS’ chunk. This system is used because, on a 5.25 drive, the physical drive head is larger than the width of the written track and so the track is also visible from neighboring quarter tracks. For example, the data of track 1.00 is actually visible while reading from track 0.75 or 1.25. Instead of storing copies of track data for every possible quarter track, we use the map to point multiple quarter tracks to a single track image.

Track | 0.00 | 0.25 | 0.50 | 0.75 | 1.00 | 1.25 | 1.50 | 1.75 | 2.00 | 2.25 | 2.50 | 2.75 | 3.00
Maps | 00 | 00 | FF | 01 | 01 | 01 | FF | 02 | 02 | 02 | FF | 03 | 03

The data of the ‘TMAP’ chunk begins at byte 88 of the file and is 160 bytes long.

Each map entry contains an index number for the track data contained within the ‘TRKS’ chunk. If the map entry is 0, then the correct track data to be using is the first entry in the ‘TRKS’ chunk. Any blank tracks are given a value of 255 (0xFF) in the map and the emulator should be outputting random bits in this case.

The mapping changes slightly between 5.25 and 3.5 disks. This is the format for the table for the layout of a 5.25 disk. The table only shows to track 35, but can also accommodate 40 track disks. All unused map entries should have a 255 (0xFF) value.

Byte | Offset | Type | Name | Usage
80 | | uint32 | ‘TMAP’ Chunk ID | 0x50414D54
84 | | uint32 | Chunk Size | Size is always 160.
88 | +0 | uint8 | Track 0.00 | Index of TRKS entry to use for Track 0.00.
89 | +1 | uint8 | Track 0.25
90 | +2 | uint8 | Track 0.50
91 | +3 | uint8 | Track 0.75
92 | +4 | uint8 | Track 1.00
… | … | | …
228 | +140 | uint8 | Track 35.00

This is the mapping for 3.5 disks:

Byte | Offset | Type | Name | Usage
80 | | uint32 | ‘TMAP’ Chunk ID | 0x50414D54
84 | | uint32 | Chunk Size | Size is always 160.
88 | +0 | uint8 | Track 0, Side 0 | Index of TRKS entry to use for Track 0, Side 0.
89 | +1 | uint8 | Track 0, Side 1
90 | +2 | uint8 | Track 1, Side 0
… | … | | …
246 | +158 | uint8 | Track 79, Side 0
247 | +159 | uint8 | Track 79, Side 1

TRKS Chunk

The ‘TRKS’ chunk contains the data for all of the unique tracks. The data of the ‘TRKS’ chunk begins at byte 256. For more efficient track data copying from SD cards and other block devices, all track data is stored in 512-byte blocks and the blocks are 512 byte aligned relative to the start of the WOZ file. The start of the TRKS chunk has an array of TRK structures to locate all of the actual bit data within the file. The actual bit data begins at byte 1536 (block 3) of the WOZ file. While every track can be a different size, this is rarely the case. Just about all 5.25 floppy disk tracks will tend to each be 13 blocks long. The track sizes for a 3.5 floppy disk will be different for each speed zone. If needed, the ‘INFO’ chunk contains a Largest Track value that you can use to safely allocate a storage buffer for any track in this WOZ file.

Byte | Offset | Type | Name | Usage
248 | | uint32 | ‘TRKS’ Chunk ID | 0x534B5254
252 | | uint32 | Chunk Size
256 | +0 | TRK | Track 00 | First track in track array. TMAP value of 0.
264 | +8 | TRK | Track 01 | Second track in track array. TMAP value of 1.
272 | +16 | TRK | Track 02 | Third track in track array. TMAP value of 2.
… | … | | …

Powered by Miniva WordPress Theme (https://tajam.id/miniva/)

1528 | +1272 | TRK | Track 159 | Last track in track array. TMAP value of 159.
1536 | +1280 | BITS | Beginning of Track Data Blocks | Start of the actual track bits.

The structure of the TRK type in the previous table is as follows:

Byte | Offset | Type | Name | Usage
– | +0 | uint16 | Starting Block | First block of BITS data. This value is relative to the start of the file, so the first possible starting block is 3. Multiply this value by 512 (x << 9) to get the starting byte of the BITS data.
– | +2 | uint16 | Block Count | Number of blocks for this BITS data.
– | +4 | uint32 | Bit Count | The number of bits in the bitstream.

The TRKS chunk always contains 160 TRK entires, but most disks will not use them all. All unused TRK structures should be filled out with zeros for all values.

The bitstream data is the series of bits recorded from the floppy drive and normalized to 4µs intervals for 5.25 disks and 2µs for 3.5 disks. The bits are packed into bytes, but the bytes will not necessarily be representative of nibble values as timing bits are also represented within the bitstream. When processing the bitstream, the order of bits within each byte is high to low, meaning the high bit goes first and the low bit is last. Since this bitstream is the flow of data directly from the floppy drive, it will need to pass through a Logic State Sequencer as found on the Disk II Interface Card, Apple 5.25 Drive Controller Card or IWM chip to create nibbles. But, due to the fact that the bitstream timing has already been normalized, you can use a very lightweight implementation of one. The Logic State Sequencer performs the function of converting the bitstream to a nibble stream as well as enforcing the proper nibble timing that many copy protection schemes will check.

If you are creating a floppy drive emulator for use with a real Apple II, then you will simply be stepping to the next bit in the bitstream at the rate specified by the Optimal Bit Timing in the INFO chunk. If the bit has a 1 value, then you send a 1µs pulse on the RDDATA line. For a 3.5 drive, the pulse width would be 0.5µs.

If the Cleaned value of the ‘INFO’ chunk is 1, then any fake bits generated by the MC3470 during the imaging process will have been removed and replaced with 0 bit values (see the Implementation Details section for proper handling of these).

As of version 2.1 of this specification, track data may also be represented as flux timings instead of bits (see FLUX Chunk section for more info). This does not change the structure of the TRKS chunk at all, but for flux data the Bit Count is actually a byte count. The contained flux data is encoded the same way as A2R files. These flux streams are properly looped so there is no time warp when wrapping from the end of the buffer back to the beginning.

A quick explanation of the flux encoding: Each byte represents a single flux transition and its value is the number of ticks since the previous flux transition. A single tick is 125 nanoseconds. Therefore the normal 4 microsecond spacing between sequential 1 bits is represented by approximately 32 ticks. This also puts 101 and 1001 bit sequences at approximately 64 and 96 ticks. You are probably thinking to yourself that when it comes to longer runs of no transitions, how is this unsigned byte going to handle representing the time? That is taken care of via the special value of 255. When you encounter a 255, you need to keep adding the values up until you reach a byte that has a non-255 value. You then add this value to all of your accumulated 255s to give you the tick count. For example 255, 255, 10 should be treated as 255 + 255 + 10 = 520 ticks.

FLUX Chunk (optional)

The ‘FLUX’ chunk contains a track map that is structured and functions identically to the ‘TMAP’ chunk. It allows you to map physical drive tracks with the track data contained within the ‘TRKS’ chunk. This ’FLUX’ map will only contain valid (non-0xFF) entries for tracks that use flux data. Additionally, any tracks that use flux data should be empty (0xFF) in the ‘TMAP’. If a WOZ file hasn’t been created properly and a single track has valid entries in both the ‘TMAP’ and ’FLUX’ maps, the ’FLUX’ one should be used.

Each map entry contains an index number for the track data contained within the ‘TRKS’ chunk. If the map entry is 0, then the correct track data to be using is the first entry in the ‘TRKS’ chunk.

To determine if a WOZ file is using flux data, the ’INFO’ chunk field INFO Version needs to be greater than or equal to 3. You should then check that the FLUX Block and Largest Flux Track values are BOTH non-zero. The FLUX Block value can be used as a shortcut to locate the ‘FLUX’ chunk if you are not walking through all of the blocks at load time (byte offset from start of file to ‘FLUX’ chunk is FLUX Block * 512).

WRIT Chunk (optional)

The ‘WRIT’ chunk contains the information necessary to be able to write the WOZ file to a physical floppy.

Byte | Offset | Type | Name | Usage
– | | uint32 | ‘WRIT’ Chunk ID | 0x54495257
– | | uint32 | Chunk Size
– | +0 | WTRK | Array of Track Writes

The WTRK structure provides all of the information for writing a single track to disk. Within each write there is the ability to insert multiple write commands. Each write command specifies which bits should be written to which area of the disk. For many simple disk layouts, there will just be a single write command for the entire track. But more complex writes, like if you needed to have data interleaved on neighboring half or even quarter tracks, can be done using multiple write command. The primary difference between using a single write command vs multiple is that the drive head is in write mode for the entire duration of a write command. Between write commands, the drive head is in read mode. This allows you to ensure that data on neighboring tracks is not overwritten.

Offset | Size | Name | Usage
+0 | uint8 | Track Number | The track number at which to write this data. For 5.25 disks, this value is in half-phases or quarter tracks (0 = 0.00, 4 = 1.00, 5 = 1.25). For 3.5 disks, this value indicates track number as well as side. The formula ((track << 1) + side) can be used (0 = Track 0, Side 0, 1 = Track 0, Side 1, 2 = Track 1, Side 0).
+1 | uint8 | Command Count | The number of commands in the write array.
+2 | uint8 | Additional Write Functions Bit Field | Bit field with a 1 indicating to perform the action: 0x01 = Wipe the track before writing.
+3 | uint8 | – | Reserved and must be zero.
+4 | uint32 | BITS checksum | Checksum of the entire used BITS data of this TRK. The proper data length can be calculated by (TRK.bitCount + 7) / 8. Used to determine if the BITS has changed since the WRIT chunk was written.
+8 | WCMD | Array of Write Commands

The structure of the WCMD type is as follows:

Offset | Size | Name | Usage
+0 | uint32 | Index of starting bit | The index of the first bit of this write.
+4 | uint32 | Bit Count | The number of bits to write.
+8 | uint8 | Leader Nibble | If this write requires leader nibbles, then this is the value for it. Typical value for this is 0xFF. If no leader is needed, then set value to 0x00.
+9 | uint8 | Leader Nibble Bit Count | The number of bits that leader nibbles have. Typical value for DOS 3.3 and ProDOS would be 10.
+10 | uint8 | Leader Count | The number of Leader Nibbles that should be written before the bit data.
+11 | uint8 | – | Reserved and currently used to pad each WCMD to 4 byte boundaries. Must be zero.

The Leader Nibble information in the WCMD structure is used to ensure a clean gap 1, it contains a nibble value and bit count for the nibbles that should be written before the data bits. For a normal DOS 3.3 or ProDOS disk, the leader would be 128 FF/10 nibbles.

META Chunk (optional)

The ‘META’ chunk contains metadata for the disk image and its existence is optional in the WOZ file. The metadata is stored as a tab-delimited UTF-8 list of keys and values. Columns are by separated by a tab character (‘\t’ 0x09). All rows end with a linefeed character (‘\n’ 0x0A)

Byte | Offset | Type | Name | Usage
– | | uint32 | ‘META’ Chunk ID | 0x4154454D
– | | uint32 | Chunk Size | Length of the metadata string in bytes.
– | +0 | String | Metadata | Metadata string in UTF-8. No BOM.

This is the list of standard metadata keys. Multiple values are pipe-separated.

Key | Purpose | Example Value
title | Name/Title of the product. | Prince of Persia
subtitle | Subtitle of the product.
publisher | Publisher of the software. | Brøderbund Software, Inc.
developer | Developer of the software. Pipe-delimited list if needed. | Jordan Mechner
copyright | Copyright date. Free form text allowed. | 1989 1987 Muse Software
version | Version number of the software. Free form text allowed. | 1.0 19870115P
language | Language (see table A) | English
requires_ram | RAM requirements (see table B) | 64K
requires_machine | Which computers does this run on? Pipe-delimited list. (see table C) | 2+|2e|2c|2gs
notes | Additional notes.
side | Physical disk side formatted as: “Disk #, Side [A|B]” | Disk 1, Side A
side_name | Name of the disk side. If the disk side is named on the label like Player, Town, Dungeon, etc then it goes here. | Front
contributor | Name of the person who imaged the disk. | Mr. Pirate
image_date | RFC3339 date of the imaging. | 2018-01-07T05:00:02.511Z

If a standard key has no value, then the value will be an empty string. Key names are case-sensitive. Values cannot contain pipe, linefeed or tab characters. It would also be a good idea to keep all values as ASCII-friendly as possible to ensure compatibility with the widest range of devices that will consume these files. No duplicate keys are allowed and key order does not matter. Standard keys that have values laid out in the tables below cannot have values other that those shown below. Implementors are free to add additional keys to the metadata as long as they follow the same rules laid out here.

TABLE A- LANGUAGES

English | Spanish | French | German
Chinese | Japanese | Italian | Dutch
Portuguese | Danish | Finnish | Norwegian
Swedish | Russian | Polish | Turkish
Arabic | Thai | Czech | Hungarian
Catalan | Croatian | Greek | Hebrew
Romanian | Slovak | Ukrainian | Indonesian
Malay | Vietnamese | Other

TABLE B – REQUIRES_RAM

16K | 24K | 32K | 48K
64K | 128K | 256K | 512K
768K | 1M | 1.25M | 1.5M+

Unknown

TABLE C – REQUIRES_MACHINE

2 | 2+ | 2e | 2c
2e+ | 2gs | 2c+ | 3

3+

## Appendix A: CRC Routine

The integrity of the WOZ files are protected by a standard 32-bit CRC. The routine that has been chosen for use originated with Gary S. Brown in 1986 and is implemented as follows:

static uint32_t crc32_tab[] = { 0x00000000, 0x77073096, 0xee0e612c, 0x990951ba, 0x076dc419, 0x706af48f, 0xe963a535, 0x9e6495a3, 0x0edb8832, 0x79dcb8a4, 0xe0d5e91e, 0x97d2d988, 0x09b64c2b, 0x7eb17cbd, 0xe7b82d07, 0x90bf1d91, 0x1db71064, 0x6ab020f2, 0xf3b97148, 0x84be41de, 0x1adad47d, 0x6ddde4eb, 0xf4d4b551, 0x83d385c7, 0x136c9856, 0x646ba8c0, 0xfd62f97a, 0x8a65c9ec, 0x14015c4f, 0x63066cd9, 0xfa0f3d63, 0x8d080df5, 0x3b6e20c8, 0x4c69105e, 0xd56041e4, 0xa2677172, 0x3c03e4d1, 0x4b04d447, 0xd20d85fd, 0xa50ab56b, 0x35b5a8fa, 0x42b2986c, 0xdbbbc9d6, 0xacbcf940, 0x32d86ce3, 0x45df5c75, 0xdcd60dcf, 0xabd13d59, 0x26d930ac, 0x51de003a, 0xc8d75180, 0xbfd06116, 0x21b4f4b5, 0x56b3c423, 0xcfba9599, 0xb8bda50f, 0x2802b89e, 0x5f058808, 0xc60cd9b2, 0xb10be924, 0x2f6f7c87, 0x58684c11, 0xc1611dab, 0xb6662d3d, 0x76dc4190, 0x01db7106, 0x98d220bc, 0xefd5102a, 0x71b18589, 0x06b6b51f, 0x9fbfe4a5, 0xe8b8d433, 0x7807c9a2, 0x0f00f934, 0x9609a88e, 0xe10e9818, 0x7f6a0dbb, 0x086d3d2d, 0x91646c97, 0xe6635c01, 0x6b6b51f4, 0x1c6c6162, 0x856530d8, 0xf262004e, 0x6c0695ed, 0x1b01a57b, 0x8208f4c1, 0xf50fc457, 0x65b0d9c6, 0x12b7e950, 0x8bbeb8ea, 0xfcb9887c, 0x62dd1ddf, 0x15da2d49, 0x8cd37cf3, 0xfbd44c65, 0x4db26158, 0x3ab551ce, 0xa3bc0074, 0xd4bb30e2, 0x4adfa541, 0x3dd895d7, 0xa4d1c46d, 0xd3d6f4fb, 0x4369e96a, 0x346ed9fc, 0xad678846, 0xda60b8d0, 0x44042d73, 0x33031de5, 0xaa0a4c5f, 0xdd0d7cc9, 0x5005713c, 0x270241aa, 0xbe0b1010, 0xc90c2086, 0x5768b525, 0x206f85b3, 0xb966d409, 0xce61e49f, 0x5edef90e, 0x29d9c998, 0xb0d09822, 0xc7d7a8b4, 0x59b33d17, 0x2eb40d81, 0xb7bd5c3b, 0xc0ba6cad, 0xedb88320, 0x9abfb3b6, 0x03b6e20c, 0x74b1d29a, 0xead54739, 0x9dd277af, 0x04db2615, 0x73dc1683, 0xe3630b12, 0x94643b84, 0x0d6d6a3e, 0x7a6a5aa8, 0xe40ecf0b, 0x9309ff9d, 0x0a00ae27, 0x7d079eb1, 0xf00f9344, 0x8708a3d2, 0x1e01f268, 0x6906c2fe, 0xf762575d, 0x806567cb, 0x196c3671, 0x6e6b06e7, 0xfed41b76, 0x89d32be0, 0x10da7a5a, 0x67dd4acc, 0xf9b9df6f, 0x8ebeeff9, 0x17b7be43, 0x60b08ed5, 0xd6d6a3e8, 0xa1d1937e, 0x38d8c2c4, 0x4fdff252, 0xd1bb67f1, 0xa6bc5767, 0x3fb506dd, 0x48b2364b, 0xd80d2bda, 0xaf0a1b4c, 0x36034af6, 0x41047a60, 0xdf60efc3, 0xa867df55, 0x316e8eef, 0x4669be79, 0xcb61b38c, 0xbc66831a, 0x256fd2a0, 0x5268e236, 0xcc0c7795, 0xbb0b4703, 0x220216b9, 0x5505262f, 0xc5ba3bbe, 0xb2bd0b28, 0x2bb45a92, 0x5cb36a04, 0xc2d7ffa7, 0xb5d0cf31, 0x2cd99e8b, 0x5bdeae1d, 0x9b64c2b0, 0xec63f226, 0x756aa39c, 0x026d930a, 0x9c0906a9, 0xeb0e363f, 0x72076785, 0x05005713, 0x95bf4a82, 0xe2b87a14, 0x7bb12bae, 0x0cb61b38, 0x92d28e9b, 0xe5d5be0d, 0x7cdcefb7, 0x0bdbdf21, 0x86d3d2d4, 0xf1d4e242, 0x68ddb3f8, 0x1fda836e, 0x81be16cd, 0xf6b9265b, 0x6fb077e1, 0x18b74777, 0x88085ae6, 0xff0f6a70, 0x66063bca, 0x11010b5c, 0x8f659eff, 0xf862ae69, 0x616bffd3, 0x166ccf45, 0xa00ae278, 0xd70dd2ee, 0x4e048354, 0x3903b3c2, 0xa7672661, 0xd06016f7, 0x4969474d, 0x3e6e77db, 0xaed16a4a, 0xd9d65adc, 0x40df0b66, 0x37d83bf0, 0xa9bcae53, 0xdebb9ec5, 0x47b2cf7f, 0x30b5ffe9, 0xbdbdf21c, 0xcabac28a, 0x53b39330, 0x24b4a3a6, 0xbad03605, 0xcdd70693, 0x54de5729, 0x23d967bf, 0xb3667a2e, 0xc4614ab8, 0x5d681b02, 0x2a6f2b94, 0xb40bbe37, 0xc30c8ea1, 0x5a05df1b, 0x2d02ef8d
};

uint32_t crc32(uint32_t crc, const void *buf, size_t size) {
const uint8_t *p;
p = buf;
crc = crc ^ ~0U;
while (size--)
crc = crc32_tab[(crc ^ *p++) & 0xFF] ^ (crc >> 8); return crc ^ ~0U;
}

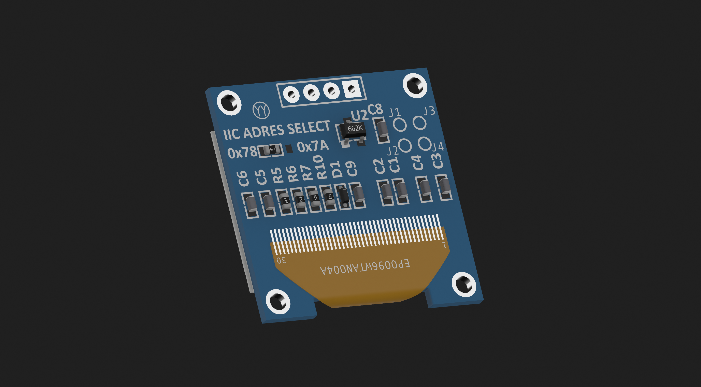
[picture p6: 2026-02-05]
hardware/weewooday-0-96-inch-oled-module-12864-128x64-driver-iic-i2c-serial-self-luminous-display-board-1.snapshot.1/pic1.png

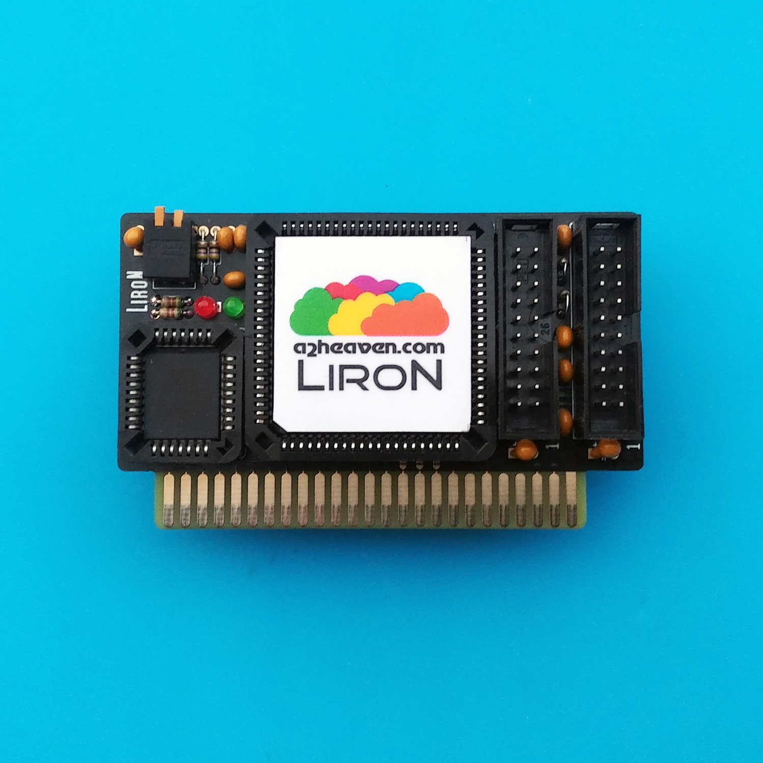
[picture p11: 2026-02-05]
doc/controllercard/LironTop_jpg-100590-1500x1500.jpg

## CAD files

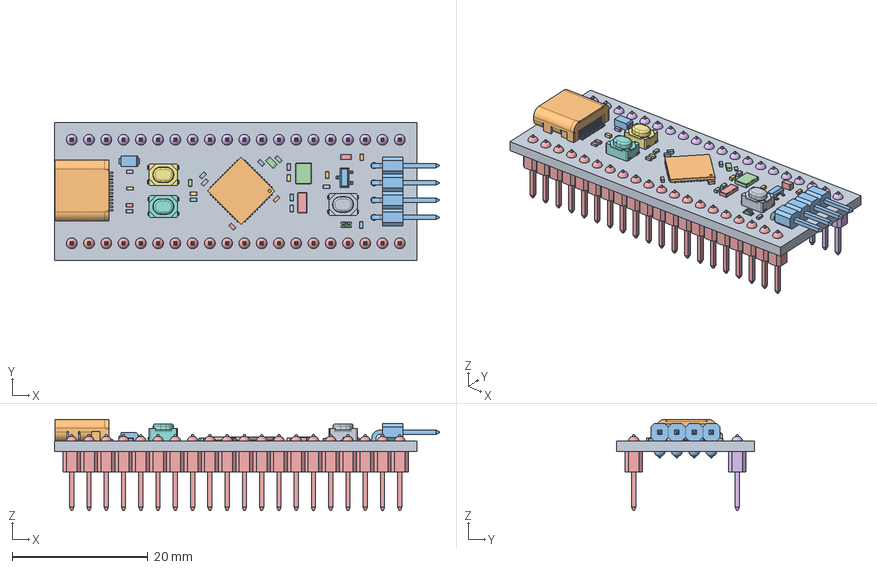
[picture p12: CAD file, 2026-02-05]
hardware/stm32f411-stm32f401-black-pill-1.snapshot.5/Black Pill/Black Pill Assembly.FCStd
56.6 x 20.3 x 13.4 mm
Board_001
STM32F4 Chip_001
Surface Mount Transistor_001
0603 Resistor_001
0603 Capacitor_001
0402 Capacitor_001
0402 Resistor_001
0402 Resistor_002
0402 Resistor_003
0402 Resistor_004
0402 Resistor_005
0402 Resistor_006
0402 Resistor_007
0402 Resistor_008
0402 Capacitor_002
0402 Capacitor_003
0402 Capacitor_004
0402 Capacitor_005
0402 Capacitor_006
0402 Capacitor_007
0402 Capacitor_008
0402 Capacitor_009
0402 Capacitor_010
0402 Capacitor_011
0402 Capacitor_012
0402 Capacitor_013
Diode 2_001
SM LED_001
1x20 Male Header_001
1x20 Male Header_002
Tac Switch_001
Tac Switch_002
Tac Switch_003
USB-C Connector_001
1x4 Right Angle Male Header_001
Crystal 1_001
Crystal 2_001

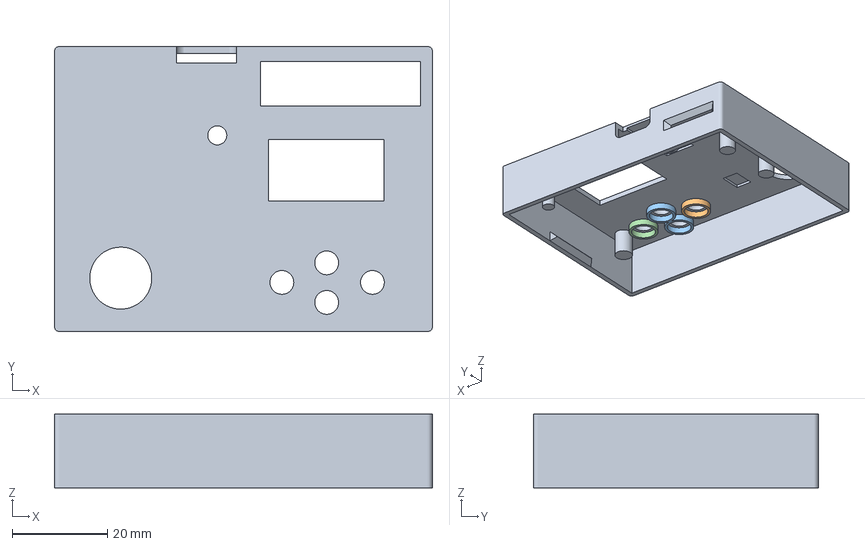
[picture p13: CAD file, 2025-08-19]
3DPrintCase/v4/SmartDiskII body highBuzr v4.3mf
79.3 x 59.8 x 15.5 mm

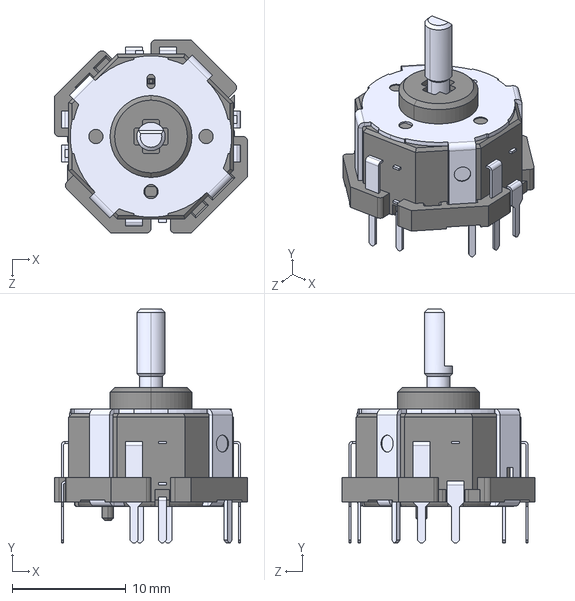
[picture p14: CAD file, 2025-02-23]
Contributed/A2F-Hardware/cad/RKJXT1F42001.step
17.0 x 20.6 x 17.0 mm

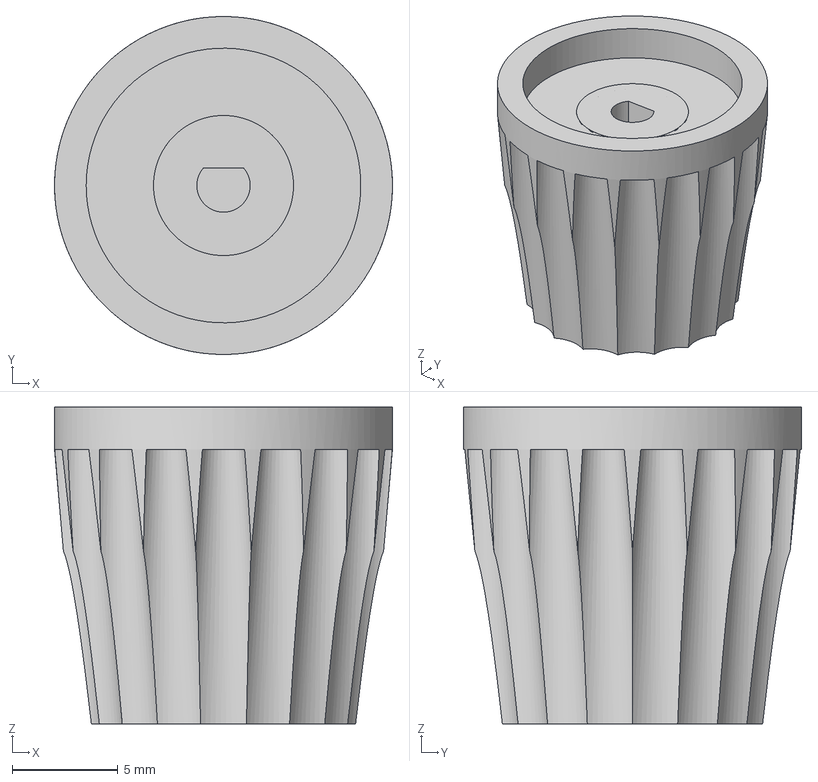
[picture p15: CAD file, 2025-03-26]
Contributed/A2F-STL/EncoderKnob.3mf
16.0 x 16.0 x 15.0 mm

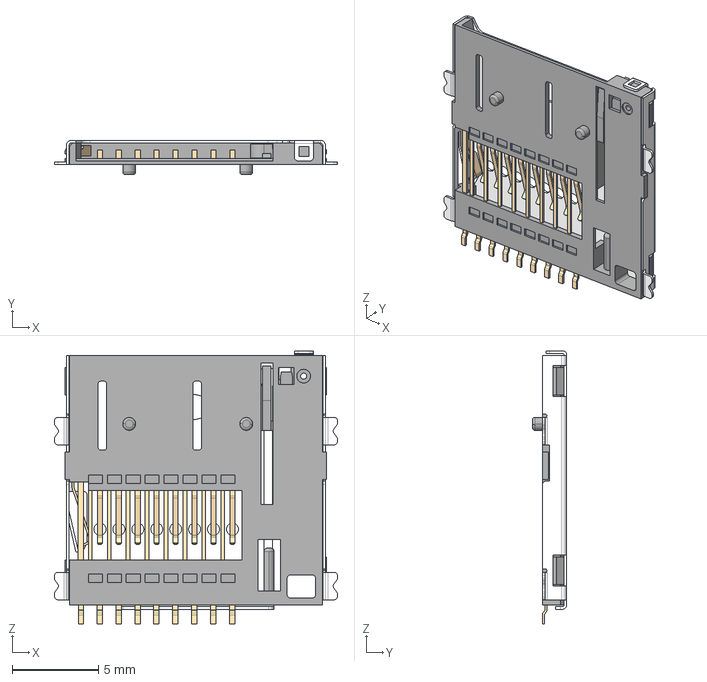
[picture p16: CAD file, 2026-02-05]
hardware/3dstep/mem2075.stp
16.4 x 2.00 x 15.8 mm

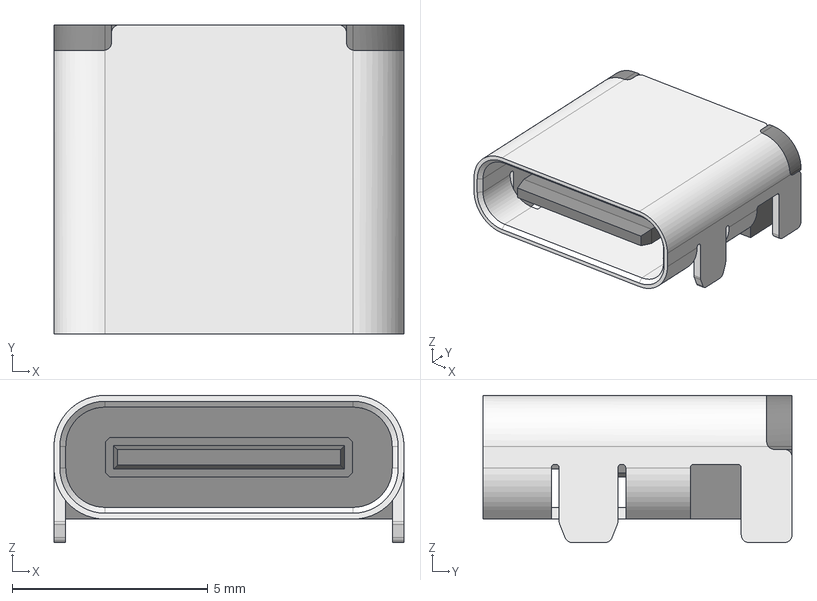
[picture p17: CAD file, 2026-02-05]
hardware/stm32f411-stm32f401-black-pill-1.snapshot.5/Black Pill/USB-C Connector.FCStd
8.94 x 7.90 x 3.76 mm

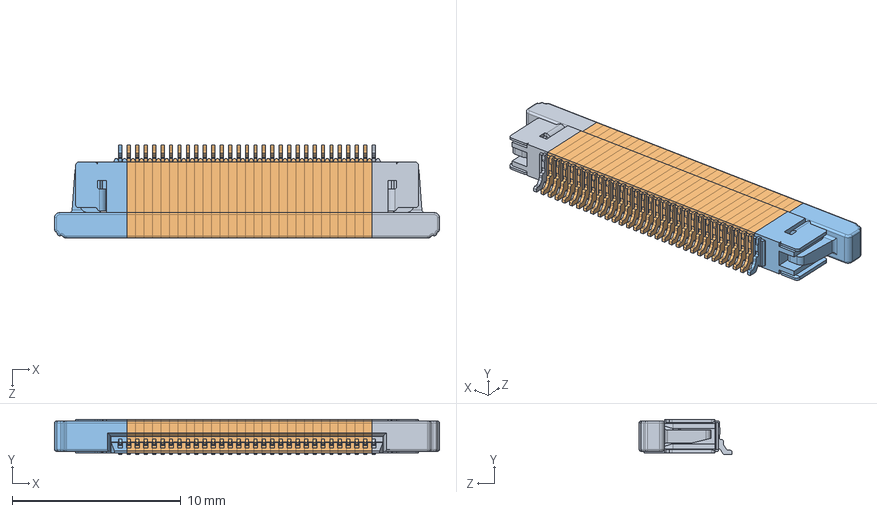
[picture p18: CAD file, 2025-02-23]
Contributed/A2F-Hardware/cad/F32R-1A7H1-11031.step
22.8 x 2.10 x 5.50 mm
F32R_R.STEP
F32R_M.STEP x 29
F32R_L.STEP

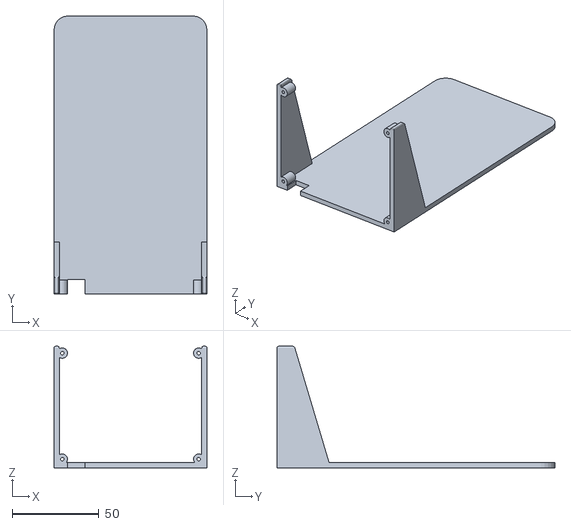
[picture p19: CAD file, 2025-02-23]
Contributed/A2F-STL/SDISK-STM.stl
88.0 x 160.0 x 70.0

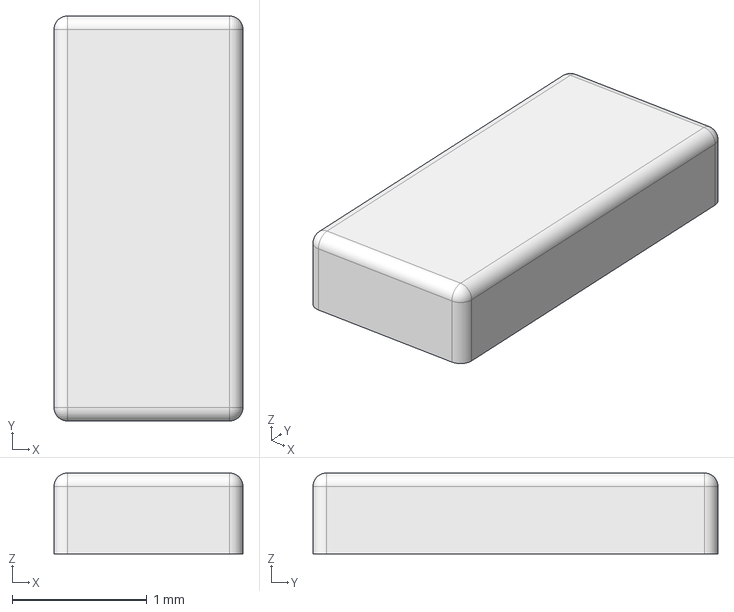
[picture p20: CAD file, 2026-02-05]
hardware/stm32f411-stm32f401-black-pill-1.snapshot.5/Black Pill/Crystal 2.FCStd
1.40 x 3.00 x 0.6 mm

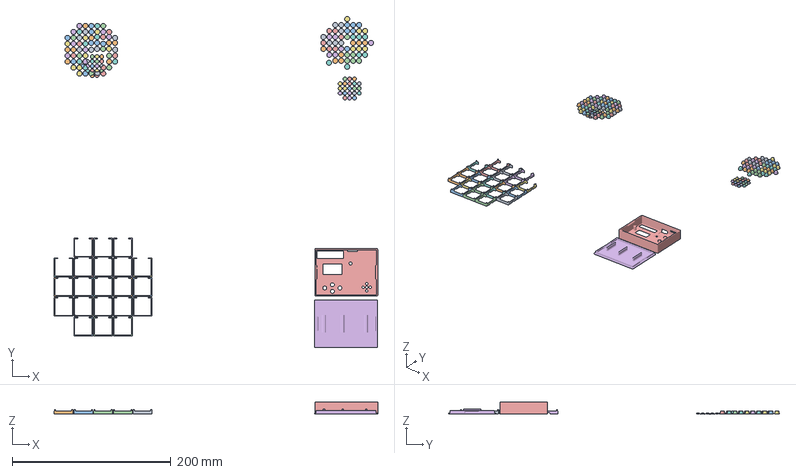
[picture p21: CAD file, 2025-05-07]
3DPrintCase/v4/SmartDiskII button nav.3mf
407.2 x 416.6 x 15.5 mm
bouton x 112
bouton RESET x 39
SmartDiskII body lowBuzr

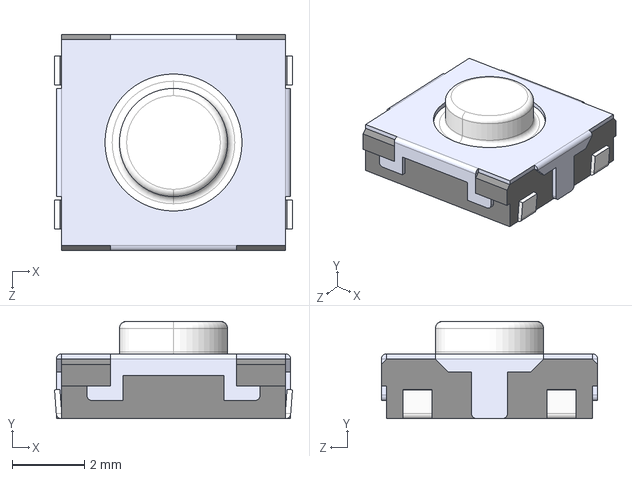
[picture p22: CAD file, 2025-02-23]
Contributed/A2F-Hardware/cad/EVQ-Q2B02W.step
6.60 x 2.70 x 6.00 mm

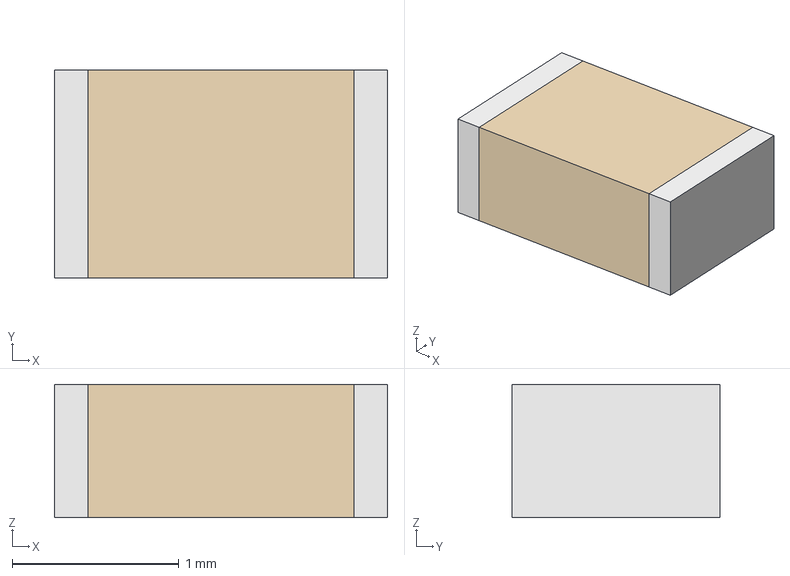
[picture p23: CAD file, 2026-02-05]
hardware/stm32f411-stm32f401-black-pill-1.snapshot.5/Black Pill/0805 Capacitor.FCStd
2.00 x 1.25 x 0.8 mm
Body001 (Mirror #1)

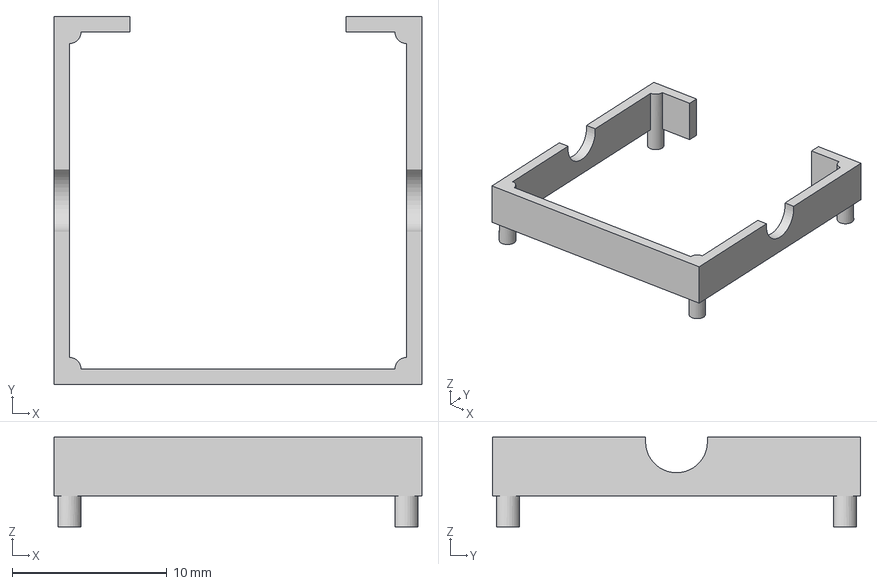
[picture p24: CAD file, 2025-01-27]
3DPrintCase/v4/SmartDiskII screenGabarit v4.3mf
23.8 x 23.8 x 5.80 mm

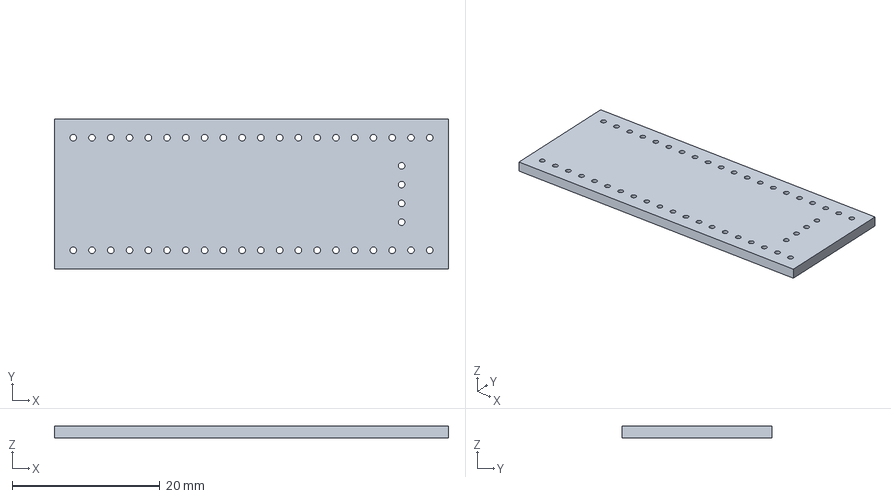
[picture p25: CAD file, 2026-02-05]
hardware/stm32f411-stm32f401-black-pill-1.snapshot.5/Black Pill/Board.FCStd
53.3 x 20.3 x 1.60 mm

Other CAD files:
3DPrintCase/v4/SmartDiskII body lowBuzr v4.3mf
3DPrintCase/v4/SmartDiskII top v4.3mf
hardware/stm32f411-stm32f401-black-pill-1.snapshot.5/Black Pill/STM32F4 Chip.FCStd
3DPrintCase/v4/SmartDiskII button reset v4.3mf
3DPrintCase/v1/SmartDiskII Bambulab prj.3mf
3DPrintCase/v1/SmartDiskII Case v18.f3d
3DPrintCase/v1/SmartDiskII bottom v18.3mf
3DPrintCase/v1/SmartDiskII top v18.3mf
3DPrintCase/v2/SmartDiskII box v8.3mf
3DPrintCase/v3/SmartDiskII body highBuzr v3.3mf
3DPrintCase/v3/SmartDiskII body lowBuzr.3mf
3DPrintCase/v3/batch.3mf
3DPrintCase/v4/SmartDiskII 3D Case board v7.f3d
3DPrintCase/v4/SmartDiskII button .3mf
hardware/12085_buzzer/12085_buzzer.step
hardware/3dstep/12085_buzzer.step
hardware/stm32f411-stm32f401-black-pill-1.snapshot.5/Black Pill/0402 Capacitor.FCStd
hardware/stm32f411-stm32f401-black-pill-1.snapshot.5/Black Pill/0402 Resistor.FCStd
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

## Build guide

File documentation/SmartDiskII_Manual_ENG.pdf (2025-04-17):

# SMARTDISK ][

I Introduction

Thanks for using the SmartDisk II drive to replace your existing DISKII and SmartPort drive for Apple II+ // IIe // IIc & IIGS. This drive is the result of the opensource efforts to bring the best retro-device experience. This drive will continue to evolve as new firmware will be release with new features, capabilities and issues fixing.

Progresses are available at: https://github.com/vibr77/AppleIIDiskIIStm32F411

This drive supports image files from various formatssuch as: DSK, WOZ 1.0, WOZ 2.0, NIB, PO.

II Usage precautions

For best usage experience and to keep your SmartDisk II functioning, some precautions need to be followed:

- Never plug in/out your SmartDisk II while your Apple II is powered on, it may damage the SmartDisk II circuit,
- Never insert or eject the SDCard while the SmartDisk II is powered,
- Do not plug in USB with your SmartDisk II connected to the Apple II,
- Always check the IDC connection on the Apple Disk controller before turning the Apple II power on,
- SmartDisk II before rev 3 is not compatible with IIc & IIGS, a modification is needed on the PCB.

III SmartDisk Hardware description

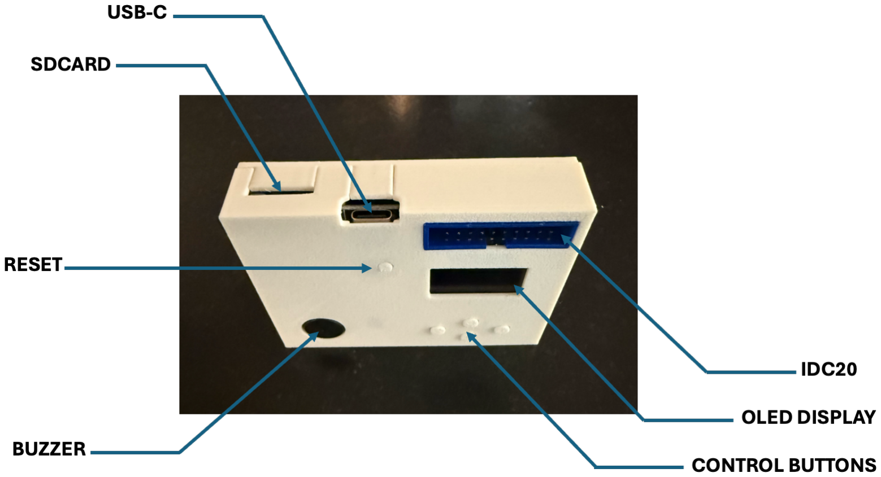
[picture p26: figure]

IV Connecting your SmartDisk II to your Apple

A/ Apple II + / Apple IIe

You will need a Disk II controller that should be connected to your DISK II drive. It is very important to check the side of the 20 pins ribbon before connecting the SmartDisk II.

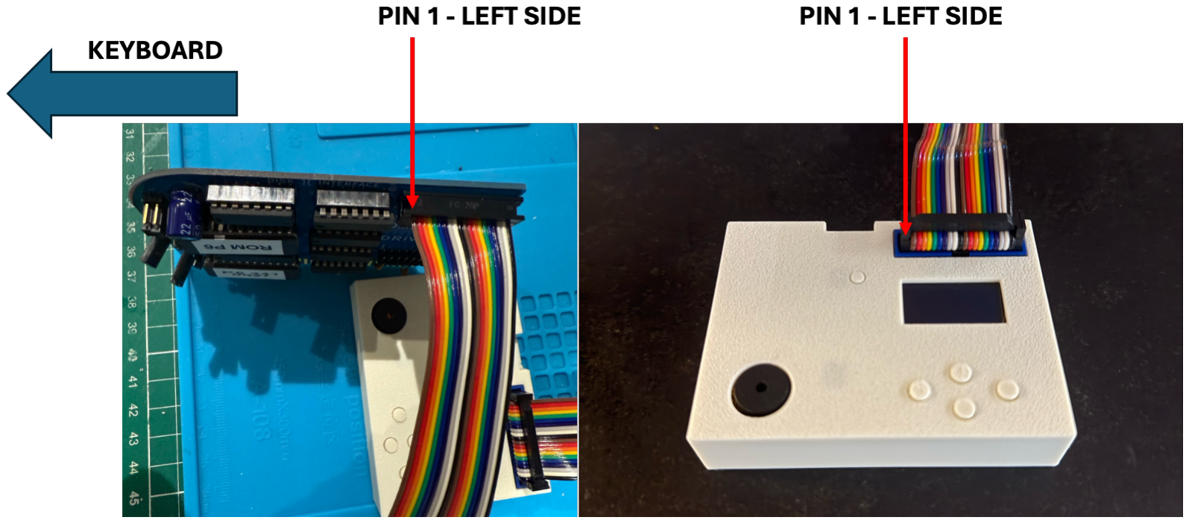
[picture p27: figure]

Check the color of the ribbon cable to make sure the left side of the DISKII Controller is connected to the left side of the SmartDisk II.

B/ IIc & IIGS

To connect the SmartDisk II to your IIc and IIGS, and adapter will be needed to convert SmartPort (SUB-D19) to IDC20. It is very hard to find a SUB-D19 as no-one is now using it.

This online shop have SUB-D19: http://iec.net/product/d-style-male-solder-type-connector/

An adapter to convert SUB-D19 and IDC20 is available on github: https://github.com/vibr77/SmartPortAdapter

V Preparing the SDCard

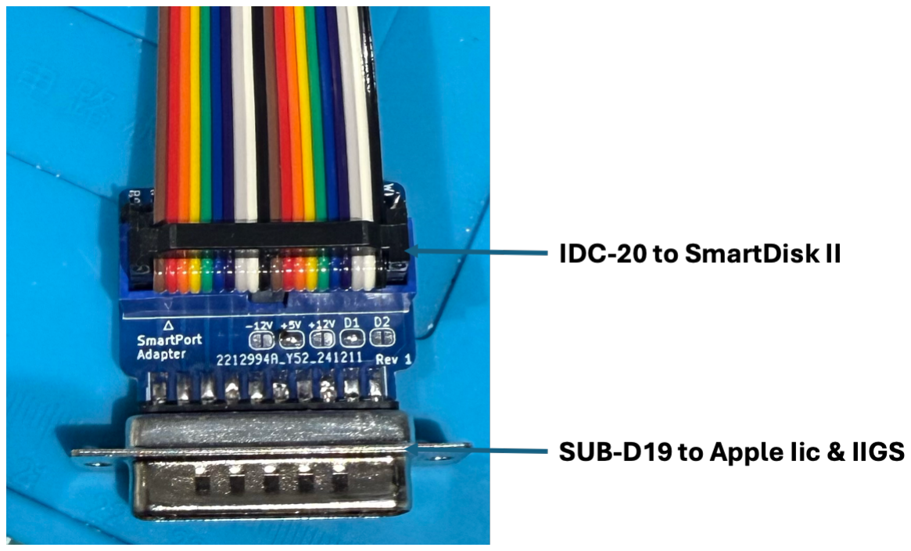
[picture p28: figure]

The SDCardneeds to be formatted using FAT32 with a specific sector size: 64 sectors of 512 Bytes per cluster. This is needed to ensure an optimal access to comply with Apple II timing requirement.

If SDCard formatting is not done with the right sector size (512 Bytes) then, reading image file on Apple II will give unpredictable behaviours.

On Linux: formatting can be done on a terminal: mkfs.fat -F 32 -s64 [SDCARD /dev/sde as exemple]

On Windows:Tools like DiskGenius can perform the required formatting with cluster size 32Kb and 512 sectors

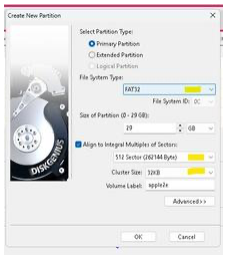
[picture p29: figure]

On Mac using a terminal: sudo newfs_msdos -F 32 -c 64 [diskXsY]

There is also an option in the configuration menu on the SmartDisk II to rightfullyformat the SDCard

VI Update

Each SmartDisk II has a bootloader that enable easy firmware update. To enter theBootloader mode, double click on the RESET button.

Process:

1. Disconnect the SmartDisk from the Apple II
2. Remove the SDCard
3. Connect the SmartDisk on your PC using a USB Cable (be carefulsome cable are only Powercable and do not enable data transfer)
4. DoubleClickon the Reset button on the SmartDisk II
5. On the computer a new drive should have appeared
6. Copy & Paste UF2 firmware update file available on github release

Warning:before updating to USB, unplug the SmartDisk II from the Apple II otherwise it may be damaged.

VI Using the SmartDisk II

A/ User Interface

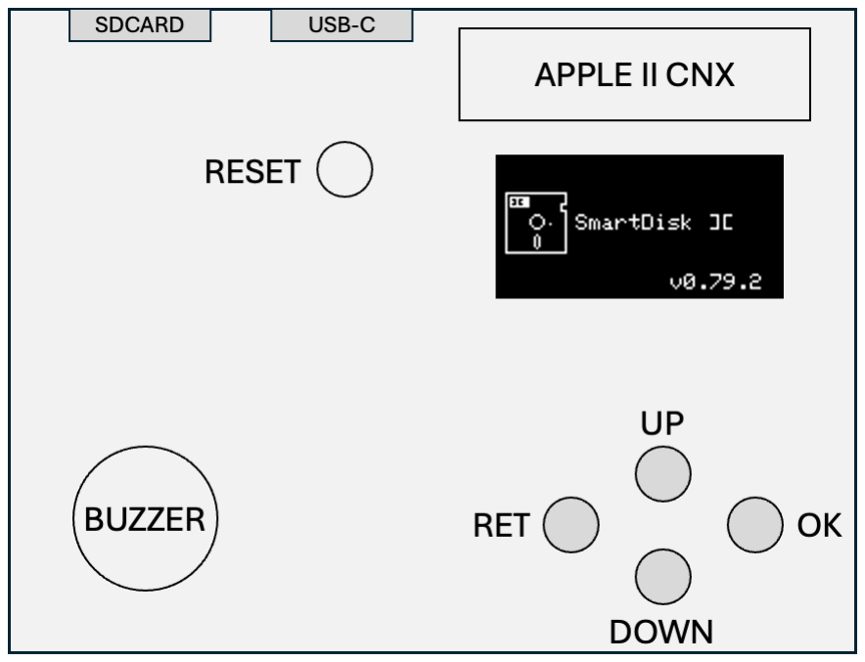
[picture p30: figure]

The User interface is composed of:

- 4 Navigation buttons
- RET: Return
- OK: execute selection
- UP: move selection up
- DOWN: move selection down
- 1 System reset button: perform a system reboot when a single click is done oractivate DFU mode for firmware update when a double click is done.
- 1 OLED Screen
- 1 Buzzer
B/ SCREEN NAVIGATION

The overall screen navigation path from the splash Screen to mounted image is:

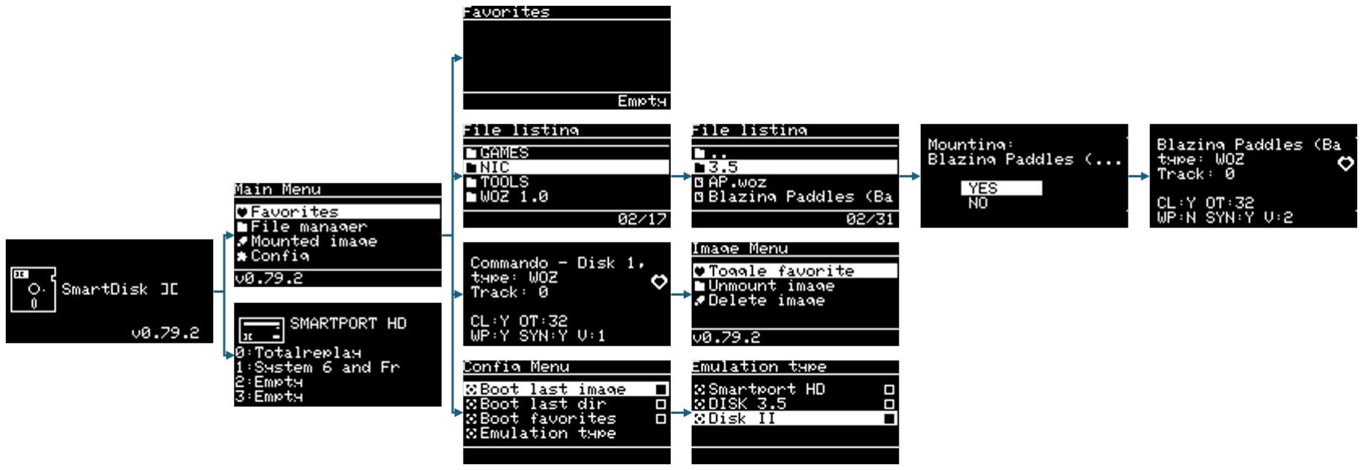
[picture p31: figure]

B.1 SplashScreen:

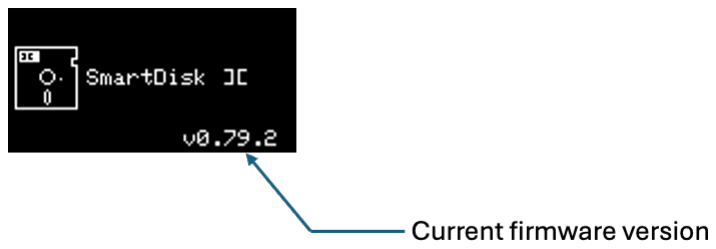
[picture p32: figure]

When the system bootup, the first screen to be displayed is the splash Screen, it provides at the bottom right the current firmware version. The current firmware version changes according to the firmware update (see upgrade).

After 2 seconds the Splash screen is replaced by either:

- The SMARTPORTHD screen if the emulation type in the config is Smartport HD,
- The last mounted image if boot last image option is selected from the config
- The File manager screen if boot last folderoption is selected
- The Main Menu at the first boot or if no image has been previously mounted B.2 Main Menu
| The Main Menu is the root screen of the SmartDisk II. It can be reached by pressing the [RET] button from any other screen. The current firmware version is displayed at the bottom left.
Navigation | [UP] & [DOWN]Buttons are used to change the current selection highlighted on the screen [OK]Button is used to move to the selected option on the screen
Options | Favorites: list the image file added to favorites (only in DISK II emulation) File Manager: navigate within the directory tree of the SDCard Mounted Image: display the current Mounted image if any Config: navigate to the configuration screen

B.3 SmartPort HD

If the emulation type selected in the config is Smartport HD then the SmartDisk II can load up to 4 PO disk image.
The mountedimage isdisplayed on the screen.The first image to boot is marked with a star instead of the left number.

To change the boot order, change the boot image index in the configuration.
Each PO files needs to be stored at the root of the SDCard with a specific naming:
- Image 1: vol01_[xxx].PO
- Image 2: vol02_[xxx].PO
- …
- Image 4:vol04_[xxx].PO

[xxx] being the title to be displayed on the screen.

Each read request a Harvey Ball is changing on the screen.

Note:to use the Smartport HD emulation, the following is needed:

| - Apple II+ / IIe: a softSp card like the grappler minus, - Apple IIc: a DB19 to IDC20 interface and a ROM 4.X - Apple IIGS: a DB19 to IDC20
Navigation | [RET] to return to the main menu
B.4 File manager:
| The file manager accesses the SD Card and list all the folder and image files available and with the right extension (DSK, NIC, WOZ, PO). Folders available appears at the beginning of the listing and then image files. At the bottom right, number of itemsin the current directory is displayed.
Navigation | [RET] to return to the main menu or up in the directory tree [UP]move up the selection highlighted [DOWN]move down the selection highlighted [OK]enter the directory or mount the image file.

B.5 Mounted image

| After mounting an image file from the file manager, the image screen is displayed with the following information: - Title of the image - Image file type (WOZ,DSK,PO,NIC) - Current Track 0/35 - Heart Full means image is added to favorite - CL Weak bit cleared, Y/N - OT Optimal timing 32 x 0.125 ns - WP Write protected - SYN Synchronized track - V Version 1 / 2
Navigation | [RET] to return to the main menu [OK]enter the image option screen

B.6 Image option

| The image option lets the user to execute simple action as: - Add / Remove the image from/to favorite - Unmount the image - Permanently delete the image from the SD Card
Navigation | [RET] to return to the mounted image screen [UP]move highlighted option UP [DOWN]move highlighted option DOWN [OK]execute selected option

B.7 Config

The config screen lets the user change the configuration of the SmartDisk II with the following entries:
- Boot last image: after Boot up process, the SmartDisk will auto mount the last mounted image (if any)
- Boot last dir: after bootingprocess, the SmartDisk will display the file manager with the last browsed directory (if exists)
- Boot favorites: after booting up process, the SmartDisk will display the list of favorites image
- Emulation type: let the user chose the SmartDisk emulation between:
- DISK II : regular Apple II+ / IIe drive
- DISK 3.5: not release yet
- SmartportHD: to read 32 MB files like Total replay or IIGS GS OS
- Boot Img Index: defines for the emulation SmartportHD the image to be the first to boot
- Sound Effect: activate the Buzzer
- Clear prefs: clear the configuration
- Clear favorites: clear the list of favorites
- Make filesystem: wipe out the SDCard with a new FAT32 partition
Navigation | [RET] to return to the main menu screen [UP]move highlighted option UP [DOWN]move highlighted option DOWN [OK]execute selected option

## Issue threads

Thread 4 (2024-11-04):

Directories

intellisystems, 2024-11-04:
The interface seems to ignore directories that are a single character in length.

I discovered this by dumping a large amount of WOZ files onto the card. At first they were all in one folder, and you couldn't mount any of them. So I divided them up into folders a,b,c,d, etc.  However, the interface won't see these folders unless I lengthen the names.

vibr77, 2024-11-05:
fixed in 0.72

Closed 2024-11-24.

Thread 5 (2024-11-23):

UF2 code does not seem to work with tinyUF2 bootloader

joergschne, 2024-11-23:
Hi Vincent,

Very good work! Thanks for publishing. The github UF2 code does not seem to work yet, at least with a tinyUF2 bootloader. The program does not start (no display, no LED). Also lso the recommended change of the VECT_TAB_OFFSET to 0x00010000U in the file system_stm32f4xx.c did not help. The bootloader used is attached.

ld used: STM32F411CEUx_FLASH_BOOT.ld
https://github.com/charkster/blink_stm32f411_uf2
uf2conv.py -b 0x08010000 -f STM32F4 -o sdisk-II-078.uf2 AppleIISDiskII_stm32f411.bin

[tinyuf2-stm32f411ce_blackpill.bin.zip](https://github.com/user-attachments/files/17880062/tinyuf2-stm32f411ce_blackpill.bin.zip)

KR
Joerg

vibr77, 2024-11-23:
Hello, the tinyUF2 bootlooder is not using the same CPU Freq and clock setting, if you look at the release in GitHub I have written a dedicated bootloader that should be working.
Let me know if It is working
Vincent

joergschne, 2024-11-23:
Hi Vincent,

The bootloader:
https://github.com/vibr77/AppleIIDiskIIStm32F411/releases/download/bootloader_v0.12/Bootloader_STM32F411_DISKII.v0.12.bin
on page two works as expected, sorry I missed that.

KR
Joerg

rittwage, 2025-02-02:
Can someone describe how to use the bootloader and UF2 files? I see that the newest release is only UF2.

vibr77, 2025-02-02:
You upload the bootloader 0.13
And then double click on the desert button trigger the dfu mode, plug the usb c on you computer and you can drag and drop the uf2 ( don't forget to unplug the apple 2)

rittwage, 2025-02-02:
I uploaded the 0.12 bootloader, but double clicking NRST doesn't do anything (nothing shows up on USB).

Red light is on, blue light flickers every second or so is all it does.

vibr77, 2025-02-02:
What does it shows on screen ?

rittwage, 2025-02-02:
I found the issue. My USB-C cable was not a data cable, just charging. When I used the correct cable I was able to upload UF2 with no problem.

Do I need to worry anything about the write protection?

vibr77, 2025-02-02:
You can remove the copy protection with Stm32cubeProg. I put a copy protection on the bootloader memory location to avoid people wiping by error the bootloader and thus bricking the device

rittwage, 2025-02-03:
I only saw Bootloader 0.12 from this thread. Is there a newer 0.13 as you
mentioned, and is there any reason to upgrade that?

On Sun, Feb 2, 2025 at 12:27 PM Vincent BESSON ***@***.***>
wrote:

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

--
-
Peter Rittwage

Closed 2024-11-23.

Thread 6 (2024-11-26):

Does not work on DB19 "Smart Port" on IIgs

rittwage, 2024-11-26:
If you plug the board into a IIgs with a SmartPort (DB19) to IDC20 adapter, you get no power to the device and no activity. The adapter was tested with a Disk ][ drive first and boots disks fine.

Also, I powered the emulator with USB power (removing the jumper) but the IIgs will still not boot from it.

vibr77, 2024-11-27:
Hello rittwage,
Do you have the schematic of the DB19 to IDC20 adapter ? I need to check the pin to pin connection.
If not photo would be helpful
Thanks
Vincent

rittwage, 2024-11-27:
I think it's pretty much 1:1 but some pins may not be 100% the same use.

https://www.bigmessowires.com/2015/03/17/apple-smartport-pin-directions/

On Wed, Nov 27, 2024 at 8:49 AM Vincent BESSON ***@***.***>
wrote:

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

--
-
Peter Rittwage

rittwage, 2024-11-27:
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

tophe38, 2024-12-02:
Hello,

The same issue with an Apple IIc, and a external drive switcher.
The solution is to add a link between pin 12 (+5V) to pin 11 on Disk2STM32 apple port.
I check this from my SDisk2 base on ATMEGA328P.
Even schema from this legacy SDisk2 don't make it, but at least, it"s there, and working (well, I have some minor issue with Apple IIc I will report).

rittwage, 2024-12-02:
The STM is getting power from the SEL line instead of 5V?

tophe38, 2024-12-02:
Converting DB19 to IDC20 for Apple II floppy is not simple.
I read some places where people says is not pin to pin conversion.
I just notice it with my Apple IIc, and Floppy switcher from BOW, that there is no power on pin 12 of IDC20 interface, but at pin 11.

rittwage, 2024-12-02:
Disk II Header Pin | D-19 Pin | D-19 Color | Signal Name | Description
-- | -- | -- | -- | --
1 | 1 | Brown | GND | Ground
2 | 11 | Red | SEEKPH0 | Phase 0 stepper
3 | 2 | Orange | GND | Ground
4 | 12 | Yellow | SEEKPH1 | Phase 1 stepper
5 | 3 | Green | GND | Ground
6 | 13 | Blue | SEEKPH2 | Phase 2 stepper
7 | 4 | Violet | GND | Ground
8 | 14 | Grey | SEEKPH3 | Phase 3 stepper
9 | 5 | White | -12V | -12 volt supply
10 | 15 | Black | WRREQ | Write request
11 | 6 | Brown | +5V | +5 volt supply
12 | 16 | Red | +5V | +5 volt supply
13 | 7 | Orange | +12V | +12 volt supply
14 | 17 | Yellow | DR2 (ENABLE) | Drive 2 select /Drive enable
15 | 8 | Green | +12V | +12 volt supply
16 | 18 | Blue | RDDATA | Read data signal
17 (Violet?) | ? | ? | +12V | +12 volt supply
18 | 19 | Grey | WRDATA | Write data signal
19 (White?) | ? | ? | +12V | +12 volt supply
20 (Black?) | 10 | White | WRPROT | Write protect
x | 9 | Violet | EXINT | External interrupt

Pin 16 (which is pin 12 on the IDC) is "SELECT" on the IIgs. It's NC on the IIc.

tophe38, 2024-12-02:
If I'm correct, Disk2STM32  is using IDC20 pin 12 as +5V power supply.
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

rittwage, 2024-12-02:
Bridging pins 11 and 12 does make it work again on my IIgs through the SmartPort DB19.  Thanks!

rittwage, 2024-12-03:
> Does it work on your IIGS with Pin 11 & 12 bridged ? Vincent

Yes. Probably the power should be moved to the other pin and not bridged, but it does work. Presumably you might want the SELECT line connected to the STM32 for use.

tophe38, 2024-12-03:
Hi,
FYI, here the pinout of Disk II Interface card for Apple IIe. Pin 11 & 12 are +5V (IDC20 male connector)
(From schematic)
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

vibr77, 2024-12-03:
I need to read the Apple documentation to understand the use of select pin

vibr77, 2024-12-09:
I will update the SmartDisk II schema to use the following signal

DB19 PIN4 /3.5 DISK
DB19 PIN16 SELECT
DB19 PIN17 /ENABLE2

vibr77, 2024-12-09:
Can someone has a clear explanation of what the SELECT line is doing ?
Thanks
Vincent

vibr77, 2024-12-15:
Well, working on the Smartport protocol, be careful on the IIGS Pin 4 is not grounded but -5V and the SmartDisk is following the DISK II interface so YOU NEED TO CUT THE GRND TRACE BETWEEN IDC PIN 5 AND PIN 7. This will fixed in REV 3

vibr77, 2024-12-26:
From Rev 3 board, it is compatible with IIGS & Iic pinout

rittwage, 2024-12-26:
> I will update the SmartDisk II schema to use the following signal
>
> DB19 PIN4 /3.5 DISK DB19 PIN16 SELECT DB19 PIN17 /ENABLE2

Do we need to connect additional lines on rev1 board?

rittwage, 2024-12-26:
> Well, working on the Smartport protocol, be careful on the IIGS Pin 4 is not grounded but -5V and the SmartDisk is following the DISK II interface so YOU NEED TO CUT THE GRND TRACE BETWEEN IDC PIN 5 AND PIN 7. This will fixed in REV 3

This doesn't make sense, and if I cut pin5/7 connection I get no ground to the LCD, so it is blank.

Closed 2024-12-26.

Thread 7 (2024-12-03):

Using DiskIISTM32 on Apple IIc with floppy switcher

githubuser-user-ai, 2024-12-03:
Hi,

Following previous issue on Apple IIgs SmartPort, I'm testing it on Apple IIc smartport, with a Floppy switcher.
The floppy switcher allows to swap internal 5.25 floppy and external floppy drive on smartport (DB19).
This solution is working fine with a SDiskEmul base on ATMEGA328P

First, I link IDC 20 pin 12 and pin 11 to power DiskIISTM32.

Even if DISKIISTM32 is working, after some mount/unmount, it stops working, like freezing. I reset blackpill, and it refuse to mount a .woz file.
If I switch internal 5.25 as first drive, Apple IIc don't even boot. I have to unplug DISKIISTM32 to make Apple IIc works again.

On DiskIISTM32, I did not populate R1,R2 and R3. Maybe these pullup are important. I'm adding them.

vibr77, 2024-12-03:
Thanks, I will work on it, this is not related to the PUP resistor,
Do you have the pinout of the floppy switcher plz ?
Vincent

githubuser-user-ai, 2024-12-09:
One question about "mount" from the device
From time to time, I can't validate the "yes" when mounting a woz file ?
Is there any reason ?
Again, when I power it only (ie, not connected to Apply IIc), no issue. The same action when connected to Apple IIc Switcher, this kind of issue appears.

vibr77, 2024-12-09:
Thanks Yes I know there is a deadlock on fatfs I need to find it
Vincent

vibr77, 2025-02-23:
issue has been fixed

Closed 2025-02-23.

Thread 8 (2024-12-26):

ARM Toolchain > 13.3 compatibility

joergschne, 2024-12-26:
Hi Vincent,
Since version 0.79 and Toolchain 13.3 the DISK-II emulation and the mounting of DSK images does not work anymore. See UF2.file in the attachment. The compiler issues a lot of pointer warnings. Toolchain 14.2 cancels the build process. Which toolchain is the right one?

KR
Joerg

...
Core/Src/main.c:970:21: warning: assignment to 'int (*)(uint16_t)' {aka 'int (*)(short unsigned int)'} from incompatible pointer type 'void (*)(void *)' [-Wincompatible-pointer-types]
  970 |   ptrDeviceEnableIRQ=nothingHook;
      |                     ^
Core/Src/main.c:1122:24: warning: assignment to 'enum STATUS (*)(char *)' from incompatible pointer type 'enum STATUS (*)(prodosPartition_t *, char *)' {aka 'enum STATUS (*)(struct prodosPartition_s *, char *)'} [-Wincompatible-pointer-types]
 1122 |       ptrMountImagefile=SmartPortMountImage;
...

[AppleIISDiskII_stm32f411-0.79.1-arm-13.3.uf2.zip](https://github.com/user-attachments/files/18252552/AppleIISDiskII_stm32f411-0.79.1-arm-13.3.uf2.zip)

vibr77, 2024-12-26:
Hello Joerg,
I am working with 13.3.1 I have not try out 14.2, I will try it straight,
I do not have the issue with the DSK, but I still have dead lock with fatfs and the DMA intrerrrupt
I am working on it
Vincent

vibr77, 2024-12-26:
Ok I will submit a fix for the compilation with the toolchain 14.2 that is really more restrictive
for the DSK no issue on my side
Vincent

vibr77, 2024-12-26:
I have changed the makefile with GCC_PATH hardcoded please change it to your path

joergschne, 2024-12-26:
Hi Vincent,

The 14.2 toolchain is now working...almost. The FAT middleware also seems to have a problem with it.

Many Thanks
Joerg

josch@MacBook-JoSch Desktop % cd AppleIIDiskIIStm32F411-main     
josch@MacBook-JoSch AppleIIDiskIIStm32F411-main % make
/Applications/ArmGNUToolchain/14.2.rel1/arm-none-eabi/bin/arm-none-eabi-gcc -c -mcpu=cortex-m4 -mthumb -mfpu=fpv4-sp-d16 -mfloat-abi=hard -DUSE_HAL_DRIVER -DSTM32F411xE -DSTM32F411xE -ICore/Inc -IDrivers/STM32F4xx_HAL_Driver/Inc -IDrivers/STM32F4xx_HAL_Driver/Inc/Legacy -IDrivers/CMSIS/Device/ST/STM32F4xx/Include -IDrivers/CMSIS/Include -IMiddlewares/Third_Party/ssd1306 -IFATFS/Target -IFATFS/App -IMiddlewares/Third_Party/FatFs/src -IMiddlewares/Third_Party/cJSON/ -Og -Wall -fdata-sections -ffunction-sections -g -gdwarf-2 -MMD -MP -MF"build/main.d" -Wa,-a,-ad,-alms=build/main.lst Core/Src/main.c -o build/main.o

...

Middlewares/Third_Party/FatFs/src/ff_gen_drv.c: In function 'FATFS_reInitDisk':
Middlewares/Third_Party/FatFs/src/ff_gen_drv.c:123:28: error: passing argument 1 of 'disk_reinitialize' makes integer from pointer without a cast [-Wint-conversion]
  123 |   return disk_reinitialize(drv);
      |                            ^~~
      |                            |
      |                            const Diskio_drvTypeDef *
In file included from Middlewares/Third_Party/FatFs/src/ff_gen_drv.h:28,
                 from Middlewares/Third_Party/FatFs/src/ff_gen_drv.c:20:
Middlewares/Third_Party/FatFs/src/diskio.h:31:33: note: expected 'BYTE' {aka 'unsigned char'} but argument is of type 'const Diskio_drvTypeDef *'
   31 | DSTATUS disk_reinitialize (BYTE pdrv);
      |                            ~~~~~^~~~
make: *** [build/ff_gen_drv.o] Error 1
josch@MacBook-JoSch AppleIIDiskIIStm32F411-main %

vibr77, 2024-12-26:
should be ok now

joergschne, 2024-12-26:
Hi Vincent,

That was quick... Mounting a DSK now also works - as if by magic. Many thanks for that!
Will you be at the 38C3 tomorrow?

KR
Joerg

vibr77, 2024-12-26:
Unfortunately I can not !

Sent from Outlook for iOS<https://aka.ms/o0ukef>
________________________________
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

Closed 2024-12-26.

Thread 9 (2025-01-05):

Drivers/ directory missing (?)

cannon-zz, 2025-01-05:
Hi,

Trying to put one of these together, and the firmware build fails for me with
```
kipp% make
arm-none-eabi-gcc -c -mcpu=cortex-m4 -mthumb -mfpu=fpv4-sp-d16 -mfloat-abi=hard -DUSE_HAL_DRIVER -DSTM32F411xE -DSTM32F411xE -ICore/Inc -IDrivers/STM32F4xx_HAL_Driver/Inc -IDrivers/STM32F4xx_HAL_Driver/Inc/Legacy -IDrivers/CMSIS/Device/ST/STM32F4xx/Include -IDrivers/CMSIS/Include -IMiddlewares/Third_Party/ssd1306 -IFATFS/Target -IFATFS/App -IMiddlewares/Third_Party/FatFs/src -IMiddlewares/Third_Party/cJSON/ -Og -Wall -fdata-sections -ffunction-sections -g -gdwarf-2 -MMD -MP -MF"build/main.d" -Wa,-a,-ad,-alms=build/main.lst Core/Src/main.c -o build/main.o
In file included from Core/Src/main.c:197:
Core/Inc/main.h:30:10: fatal error: stm32f4xx_hal.h: No such file or directory
   30 | #include "stm32f4xx_hal.h"
      |          ^~~~~~~~~~~~~~~~~
compilation terminated.
make: *** [Makefile:216: build/main.o] Error 1
```
this is the first time I've worked with STM32 devices, so this is all new to me, and I don't know where this missing header file should be found.  I see the Makefile adds four Drivers/ directories to the search paths, but these aren't in the git repo.  Is it possible this was left out by accident?

vibr77, 2025-01-05:
Hello cannon-zz;
I do not include the full hal_driver (HAL = High Architecture Level driver)
Have you downloaded stcubemx from ST where it brings the HAL_driver to build the firmware, without this you can not build the firmware.

Becareful, if you generate the source code from the ioc file it will overwrite fates middleware from version 0.15 to version 0.11, you will have to manually put it back (as well as the makefile I guess)

Let me know if it works for you

Vincent

cannon-zz, 2025-01-05:
Thanks for the quick response.  I have installed STM32CubeIDE, and I used it to make a blink demo for an STM32F302 Nucleo-64 board, all of which worked, so I believe I'm set up.  Looking at a blank project in the IDE, on the left is a panel with options that include "Create a New STM32 Project from an Existing STM32CubeMX Configuration File (.ioc)".  That's the only mention I can find of "CubeMX", and it doesn't sound like what I want to do.  I guess I don't understand the relationship between what's in the git repo, and the world of the ST IDE:  am I supposed to use the IDE to populate the missing pieces of the git repo, or import the contents of the git repo into a project that lives inside the IDE world?  Sorry to bother you with this, this feels like an ST tech support problem as much as a question about building this git repo's contents.

vibr77, 2025-01-06:
Hello Cannon-zz, I do not use STM32CubeIDE but STM32CubeMx that can generate source code to be compiled by gcc,
I suggest you download STCubeMx, you load the IOC file you, you build the project on stm32cubemx, It will generate the HAL_driver file, you put back the GitHub files and you run the make command
Becareful in the makefile there is a path to the ARM SDK to be changed
Vincent

cannon-zz, 2025-01-08:
OK, progress.  A hint for other people getting into this project:  if the directory in which the project lives contains a "[" somewhere in its name --- like, oh, maybe you've put the project in a directory containing "`.../Apple ][/...`" --- it will lobotomize ST's java code.

If the code generator just hangs part way through and never becomes responsive again, then while running STM32CubeMX from a command prompt, look for a message like
```
2025-01-08 23:19:26,615 [ERROR] GenerateProjectThread:83 - java.util.regex.PatternSyntaxException: Unclosed character class near index 97
```
If you see something like that, suspect the project's path name might need to be tamed.  Had a bit of [Bobby Drop Tables](https://xkcd.com/327/) situation going on here.

vibr77, 2025-01-10:
Cannon-zz did you manage to compile ? can we close this issue plz ?

cannon-zz, 2025-01-10:
@vibr77 if you wish to close it, that's fine.  Certainly the mystery of the missing Drivers/ directory is solved.

I haven't yet solved the problem of reconstructing it locally, though.  I have a Dirvers/ directory filled with stuff, but CubeMX is now at version 6.13.0 and generates code that's different from what your Makefile was written to expect.  You explained that the Middlewares/Third_Party/FatFs/ needs to be kept at the version in your tree, not what comes out of CubeMX, that's clear, I've got that sorted out, but there are a variety of other changes that I don't understand:

- Core/Inc/main.h has 4 new #define's added:
```
#define _3_5DSK_Pin GPIO_PIN_11
#define _3_5DSK_GPIO_Port GPIOA
#define SELECT_Pin GPIO_PIN_8
#define SELECT_GPIO_Port GPIOB
```
- Core/Src/main.c has removed the initialization of TIM4 altogether, and deferred the initialization of TIM2 until after all other initializations.
- htim2.Init.Period is increased by 10.  it looks like you had a comment in there about an offset of 5 that was a puzzle, which makes me believe this was your own customization that has been reverted by CubeMX.  that's why I'm worried about all the other changes:  are these just misc improvements from ST upstream or has CubeMX reverted your hard work?
- on line ~1523, sConfigOC.Pulse is set to 132 instead of 140 as in your version
- then a few lines later on line ~1532, sConfigOC.Pulse is set to 120 instead of 140 as in your version.
- huart1.Init.BaudRate is set to 115.2k instead of 230.4k
- then a bunch of GPIO pin configuration stuff is changed.  most of it seems to be just reordering of the initializations, but GPIO_InitStruct.Pin = WR_DATA_Pin is now GPIO_InitStruct.Pin = WR_DATA_Pin|_3_5DSK_Pin and its config has been changed to GPIO_NOPULL instead of GPIO_PULLDOWN which seems significant.
- there's a new source file Drivers/STM32F4xx_HAL_Driver/Src/stm32f4xx_hal_mmc.c that wasn't mentioned in your Makefile.

I think that's everything.  I'm just going through these changes to understand what should be kept from your version and what could be kept from what CubeMX wrote.  That's where I'm at, but this issue doesn't need to remain open.

cannon-zz, 2025-01-15:
I stopped screwing around and just flashed what I had, and it worked!  First Try!  :-).  Played Lode Runner for the first time since probably the early '90s.  You've made me very happy.  Thank you thank you thank you.

If you're curious about the differences, I've posted what I ended up with at my end here https://github.com/cannon-zz/AppleIIDiskIIStm32F411 the first patch in the cubemx_overlay branch is the delta from your git repo to what cubemx put into mine.  I'm going to keep playing games, and unless I encounter a broken one I'll probably leave it the way it is.

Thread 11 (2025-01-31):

smartport menu display RD icon on wrong image fw 79.4

AP2K94, 2025-01-31:
Hi, testing the latest fw 79.4, noticed when emulation is changed to Smartport and the Smartport file list is displayed, it starts with 0 index to 3 (should be 1-4) and the RD icon shows the wrong image being loaded? It still loads the correct image as per index selection in the config menu just displays the wrong file being loaded in the list ;-)

Also just thinking (possible future enhancement) if it would be possible to simply mount one of the four hdd images to boot just like a disk image. I guess once Smartport mode is selected it only allows 4 files with vol0.. to be mounted? This will remove the need to select index number making it much easier to know what file is selected.

Finally, noticed there is a config menu option " Boot folder" not sure what this does as it cant be selected?

Thanks again, awesome device!

vibr77, 2025-02-02:
Hello, thanks for your input,
I have changed the way Smartport image are working and also fixing a lot of stuff.
Now the first device to boot is marked with a *
Starting to number image from 1
BootIndex determines the first device to boot,
Also managing unmounted image to avoid crash
Also fixing IIGS timing issue when booting
Fixing the TIMER2 Period
I hope it will work a bit better.

I need to continue to work on the write part of Smartport
Thanks for your feedback on release 0.79.6

AP2K94, 2025-02-02:
Hi, I tested 79.6 , smartport file list working nice , tested on iie and iic both look good and map 4 drives.

Quick question, I have been reading that Prodos8 2.5 can map 8 virtual drives, I have seen other devices map 8 drives (block device mode) do you think this is possible in future firmware as this would cover most of the software library on apple II lol :-)

vibr77, 2025-02-03:
Well I have checked, and it might be possible only if you write to Apple II mem (0 page) which is not possible from an external device (Prodos 8 tech note 20). I guess Booti is doing that.

Closed 2025-02-03.

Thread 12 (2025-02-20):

Make Filesystem can no longer be confirmed in the menu since v0.79

joergschne, 2025-02-20:
Hi Vincent,

It is difficult to create the right file system for the SD card under Mac OSX, so the integrated formatting function is very helpful.

PS: The firmware adjustments for the A2F hardware are almost complete and I would make a pull request at the weekend. See if you like it :)

KR
Joerg

joergschne, 2025-02-21:
Hi Vincent,

This can be fixed in display.c

@@ -754,7 +754,7 @@ void processClearFavorites(){

void processMakeFs(){
  displayStringAtPosition(1,6*SCREEN_LINE_HEIGHT+1,"CONFIRM ?");
-  mnuItem[6].triggerfunction=processMakeFsConfirmed;
+  mnuItem[9].triggerfunction=processMakeFsConfirmed;
  ptrbtnRet=processMakeFsBtnRet;
  ssd1306_UpdateScreen();

@@ -781,7 +781,7 @@ void processMakeFsConfirmed(){
}

void processMakeFsBtnRet(){
-  mnuItem[6].triggerfunction=processMakeFs;
+  mnuItem[9].triggerfunction=processMakeFs;
  ptrbtnRet=processBtnRet;
  displayStringAtPosition(1,6*SCREEN_LINE_HEIGHT+1,"         ");
  ssd1306_UpdateScreen();

KR
Joerg

vibr77, 2025-02-23:
Hello Joerg,
I have done some test, mkfs should be done on the main thread and not triggered from one interrupt (button),
I will refactor some code in v0.84 to managed outside emul_* some basic actions such as reset or mkfs.

I have added some screen for mkfs in 0.83

vibr77, 2025-02-24:
Let me know if we can close this issue

joergschne, 2025-02-24:
Many thanks

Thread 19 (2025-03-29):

Removing the need to reset Stm32 after SP file boot change and adding scrolling text to show long file names?

AP2K94, 2025-03-29:
Hi again been using fw 80.8 on both 2e/2c and has been rock solid very nice work, especially the Smartport boot option saves so much time!
Hopefully the need to press reset (after every boot file selection change) can be removed in future firmware so that it works like Disk II mode (ie make change/mount and then simply cold reset/boot the apple and it loads the new file, no Stm32 device reset required).

Also noticed in File manager the screen is cramped now with the added folder, any chance of removing the **File Listing** header on top of the screen as this should allow a couple more file lists to show, currently only 2 lines for files when in a directory.
BTW under **Directory Options** there is a **Info** item, selecting this doesn't do anything?

[Enhancement] Have you thought about having scrolling text (right to left) when the highlight bar is over a file name? This would be a great feature especially when using multi span disk images, allows easy identification of the next file to mount, and also ability to see the file type is very handy.

Thanks again!

AP2K94, 2025-06-10:
looks like most of the main items discussed are working in 10.13 thanks for your great work and enjoying the smartport functionality on the IIc!

Closed 2025-06-10.

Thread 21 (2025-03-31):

DSK Writing (I/o Error)

DanielTelles91, 2025-03-31:
Hello Vincent.

After a few days of testing with the latest firmware, I noticed a random error.

**Steps to reproduce the error:**

1) Run DSK DOS 3.3
2) Create some programs in BASIC (5-10 minutes typing the program).
3) After executing the Save xxx command, sometimes it randomly saves successfully. **Other times the following error appears: I/O Error**

The stm32 freezes and it is necessary to reset the stm32 to get it working again.

I noticed that in the WOZ 2.0 image the same random problem occurs.

Other tests that were successfully performed **without errors**:

> With the DSK image, it is possible to **format** and **copy** **disks** using the COPYA utility from DOS 3.3.

> With the blank DSK image, it is possible to format and burn disks from the asciiexpress.net website.

vibr77, 2025-04-03:
Hello,
I am able to reproduce the error and I know where it sits. It is related to SDCard access with DMA.
It seems that after a while I am loosing the SDCard communication... I need to understand in which case, I believe it has something to be with writing... I continue my investigations, keep you posted Vincent

vibr77, 2025-04-04:
Hello Daniel,
I have a new release ready to be tested, and it should solve the read/write stability. I have done some testing and I did not find any crash or segfault. It would be great if you can do some testing as well. Thanks Vincent

DanielTelles91, 2025-04-04:
Hello Vincent,
I'm going to test right now.
After the tests I will post the final result.

Thank you.

DanielTelles91, 2025-04-04:
A quick update. I've been recording and reading dsk's for over 3 hours straight.
So far no crashes.
I'll continue with other tests to make sure everything is ok.
Two days from now is enough time to have the final verdict.
I will post the final result here.
Thank you very much for making the fix available.

Thank you.

DanielTelles91, 2025-04-05:
Hello Vincent.
Firmware Test: Firmware_SmartDiskII.v0.80.9.UF2

Today the I/O error problem appeared again. But the problem is appearing less frequently.
It is very difficult because sometimes it goes for hours without presenting a problem, but other times it presents this problem constantly.
I tried using other SDCards, but without success.

Daniel.

vibr77, 2025-04-07:
Well not an easy one, I need to investigate the reason, every time it happens it is the SDCard not responding even with direct SDIO Bitbanging... very strange

vibr77, 2025-04-07:
Hello Daniel,
I have added a check on the SD to get the state every 10 sec to keep the SD up. Could you please check if it is solving the issue please ?
thanks
V

DanielTelles91, 2025-04-07:
Hello Vincent,
 **The crash issue has been resolved**. :)

But, I have just noticed a problem that has been around since previous versions of the firmware.
How to reproduce the problem:

1) Create the following program in basic:

10 PRINT "TESTE"
20 GOTO 10

SAVE TESTE

2) Create a second program in basic:

10 PRINT "TESTE2"
20 GOTO 10

SAVE TESTE 2

3) After saving TESTE 2, it overwrites the TESTE program.

The dsk with the overwritten program is attached:
[Apple DOS 3.3.zip](https://github.com/user-attachments/files/19638357/Apple.DOS.3.3.zip)

Thank you,
Daniel.

vibr77, 2025-04-08:
ok let me investigate, really strange
Vincent

vibr77, 2025-04-10:
It seems that during the write process the current track bitstream gets corrupted after the processing of the nibble. David could you please confirm that if you do "CATALOG" between to write it does work ? thanks Vincent

DanielTelles91, 2025-04-10:
Hello Vincent.
I can confirm that if I type "CATALOG"  between to write, the problem persists.
It seems that the Test 2 program is overwriting Test 1, could it be a problem in VTOC (Volume Table of Contents) Sector 17, track 11?
The strangest thing is that out of nowhere the overwriting did not occur, it seems to be a random problem.
So far I have not been able to notice a pattern.

DanielTelles91, 2025-04-11:
Hi Vincent.
Good news.
I think, I found the problem.
The **updateDiskIIImageScr()** function is being called during critical write operations, causing timing delays.

After I disabled this function, the overwriting problem stopped.
I tried to create a function to update the display when there was no critical recording process, but without success.
It seems that the time is very critical.

Thank u,
Daniel.

vibr77, 2025-04-11:
Well done, I faced this problem in the past... There might be a solution to be tested : changed the DMA interrupt priority (SDA). but indeed it is really time critical.
I will use the logic analyzer to check what kind of timing we have.

vibr77, 2025-04-11:
I have created a discord to be able to chat, the link is on the main page of project

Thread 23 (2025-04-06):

Crash on reset if no image is automatically mounted

joergschne, 2025-04-06:
Hi Vincent,

If the Reset button is pressed after powering up the Apple II, the firmware crashes with a permanent buzzing sound. This only happens on the favorite screen when no image is automatically mounted and Disk_II emulation is selected.

KR
Joerg

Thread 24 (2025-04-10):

boot last directory showing empty list

AP2K94, 2025-04-10:
Hi just testing fw 80.10 noticed minor issue with my file list being empty when I have the **Boot last directory option enabled**?

Also, while hdv is not technically supported in smartport mode, is it possible to add option to show files with hdv extension and ability to mount/load? Perhaps (future fw revision) an option to auto rename hdv files to .po?

In most scenarios we just manually rename the files extension to .po and it functions normally, never had an issue with any file.  This would be a great unique feature and extremely helpful for smartport users like me :) Thanks again for your support.

vibr77, 2025-04-11:
Th new version is coming with those fix/new feature

AP2K94, 2025-06-10:
thanks for the updates in 10.13 enjoying this great device brought back my iie and iic back to life! thank you again works perfect!

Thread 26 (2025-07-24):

FW 80.15 testing beta smartloader.po v0.33

AP2K94, 2025-07-24:
hi, just tested 80.15 with the smartloader it displays error : ERR 10 UNABLE TO GET DATA when I try to load it? pressing enter just drops into monitor

Nothing is displayed on the IIe, I tried different sdcards with minimal images, smartloader is on the root directory.
Any tips for testing further to try get it to work as this looks great 👍 hopefully it could be integrated as an optional setting in the menu for future.

vibr77, 2025-07-24:
Hi,
thanks for the feedback, few questions:
- ERR10 comes when you are trying to display the content of the SDCard or when you try to launch an image ?
- Can you do a 2800L on monitor to give me the content of the memory ?

How many images do you have on the SDCArd ? do you have folder ?
Thanks
Vincent

AP2K94, 2025-07-24:
no key pressed, i have tried with 1 game and 1 folder , still same error ?
forgot to mention there is a E00 on far left just before the ERR10

AP2K94, 2025-07-24:
I tried both disk II and smartport, I am using the db19 card with idc20 to db19 I can test on the older idc20 floppy card if you think it could be an issue just need to find it

vibr77, 2025-07-24:
It is working on my IIGS with the IDC20 to DB19 adapter,
You need to use the Disk II emulation in any case,
very strange as I do not have the same issue
What you should have in Memory Region Address: 0x2800

Byte 0 Result: 0x20 => OK
Byte 2 Number of Items to be displayed
Byte 3 to 0x17 Current folder in the SD
Byte 0x18 Item 1 for 24 Bytes (each item first Byte is a 0 for file and a 1 for directory)

Vincent

AP2K94, 2025-07-27:
yes, on 80.16,
fyi im using bootloader ver 12, pcb ver4,
i have couple games and a directory with 1 game

vibr77, 2025-07-27:
And the emulation is diskii and not smart port ?

AP2K94, 2025-07-27:
yes, diskII, and i mount the smartloader.po boot but only default list is shown, function keys [R] [B} work but [S} settings doesn't do anything.
Do you have IIe to test? or only IIgs

vibr77, 2025-07-27:
I tested it with IIGS IIe and II+

AP2K94, 2025-07-27:
yes, always been in slot 6, I have no other cards installed just the 64k/80col in aux slot, I tried 2 different cards in slot 6 db19 with adaptor and early disk II with 2 x idc20 headers

vibr77, 2025-07-27:
That is crazy, will ask other to test also

AP2K94, 2025-07-27:
Hi Vincent, I did more testing I deleted my sdiskconfig file so it regenerates with new fw and it started to work!
So happy this is amazing been using it for past few hours works so nice having the file on the apple screen is beautiful enjoying the smartdisk makes using it so easy now.
Looks like it was local issue and looking forward to your future work!
Thanks again

Closed 2025-07-27.

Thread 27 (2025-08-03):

80 col display for smartloader and add option to always load smartloader?

AP2K94, 2025-08-03:
hi vincent been enjoying the smartloader, been very stable, a great tool using it always now hence was wondering if there is potential to add option to have it always load rather than the last selected file? In its current use have to always select to re mount smartloader after every use.

Also is it possible to have 80 col option added which should increase the file list.

Great work thanks again!

AP2K94, 2025-08-03:
Forgot to mention, tried having smartloader in the favourites (and selecting boot favourites) but it wont load file list?

vibr77, 2025-08-03:
Well,
The trick is that I do not know how to detect that the Apple II has been soft reset…
The only way would be to count the step phase init sequence, and determine that it is a soft reset ?
Do you have a better approach ?
Vincent

From: Stan vuew ***@***.***>
Reply-To: vibr77/AppleIIDiskIIStm32F411 ***@***.***>
Date: Sunday 3 August 2025 at 10:24
To: vibr77/AppleIIDiskIIStm32F411 ***@***.***>
Cc: Vincent BESSON ***@***.***>, Comment ***@***.***>
Subject: Re: [vibr77/AppleIIDiskIIStm32F411] 80 col display for smartloader and add option to always load smartloader? (Issue #27)

[Image removed by sender.]AP2K94 left a comment (vibr77/AppleIIDiskIIStm32F411#27)<https://github.com/vibr77/AppleIIDiskIIStm32F411/issues/27#issuecomment-3148224094>

hi yes i have boot last image set, what i mean is when i select game via smartloader and then soft reset the apple it will load the game rather than the smartloader menu, if possible to set to always load the smartloader please as then i dont need to reset the smartdisk all the time :-)

—
Reply to this email directly, view it on GitHub<https://github.com/vibr77/AppleIIDiskIIStm32F411/issues/27#issuecomment-3148224094>, or unsubscribe<https://github.com/notifications/unsubscribe-auth/A4ZT7FJYWZ5BZ6LXGRO53633LXBM7AVCNFSM6AAAAACC7O2TIKVHI2DSMVQWIX3LMV43OSLTON2WKQ3PNVWWK3TUHMZTCNBYGIZDIMBZGQ>.
You are receiving this because you commented.Message ID: ***@***.***>

AP2K94, 2025-08-03:
I think the Apple II uses a reset vector at address $FFFC to determine the starting address of the program after a reset so after a soft reset, the program counter is set to the address specified by the reset vector.
After a hard reset, the system goes through the full boot process. Maybe we modify the reset vector to point to a custom routine that checks the state of the system by checking memory or I/O states?
Will try think it through and test some options in asm will get in touch  ;-)

Closed 2025-08-04.

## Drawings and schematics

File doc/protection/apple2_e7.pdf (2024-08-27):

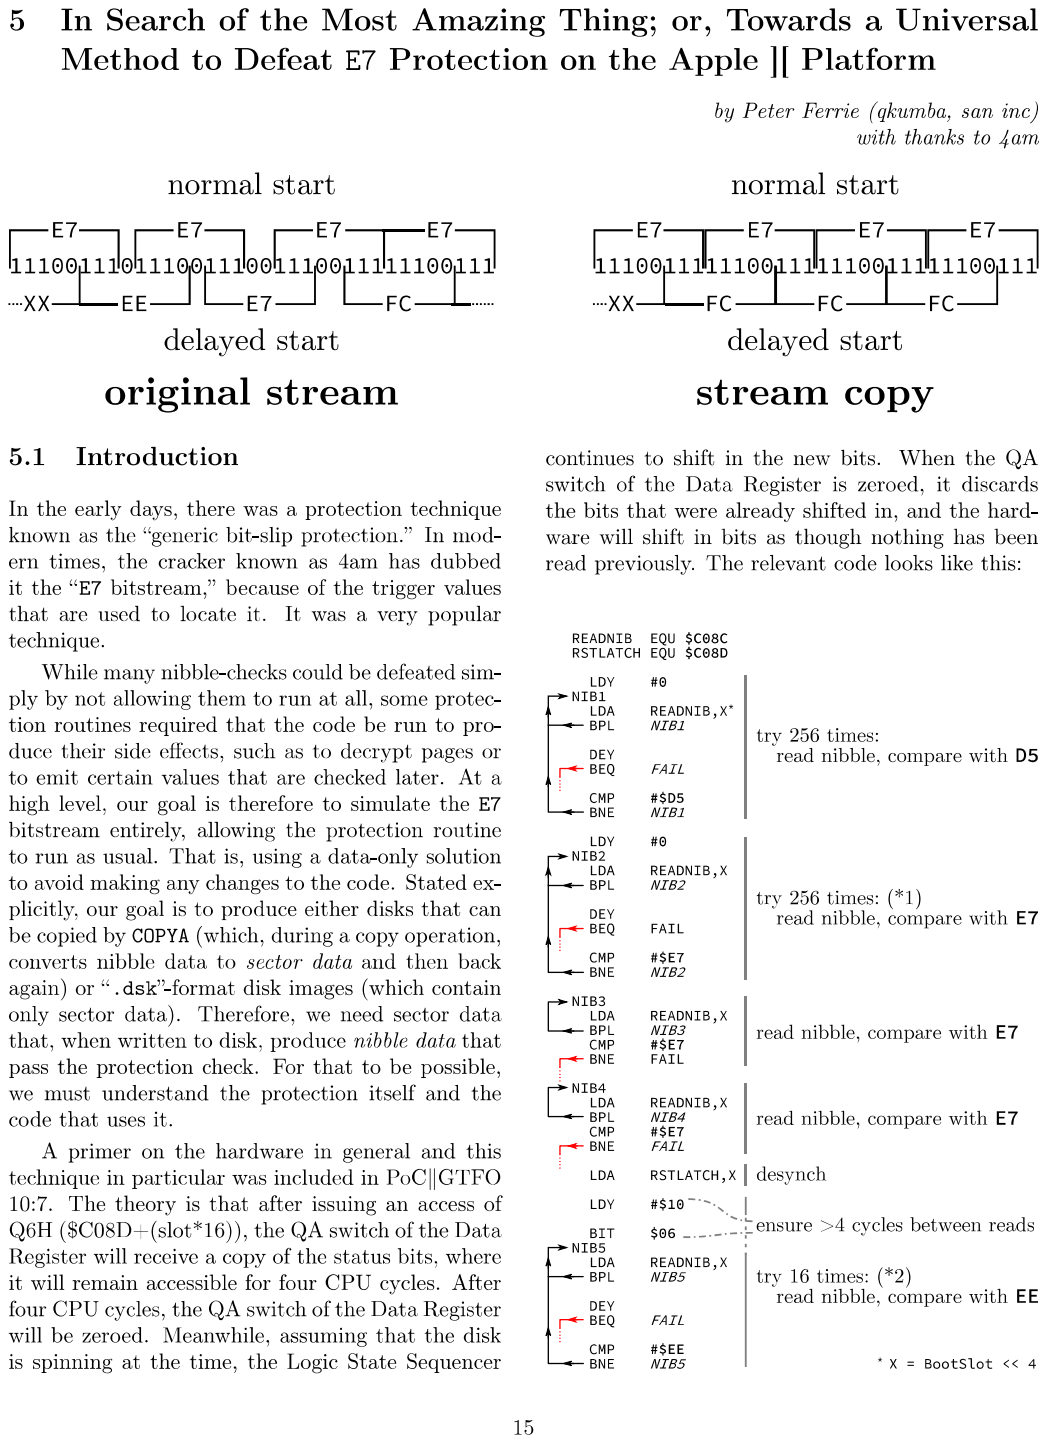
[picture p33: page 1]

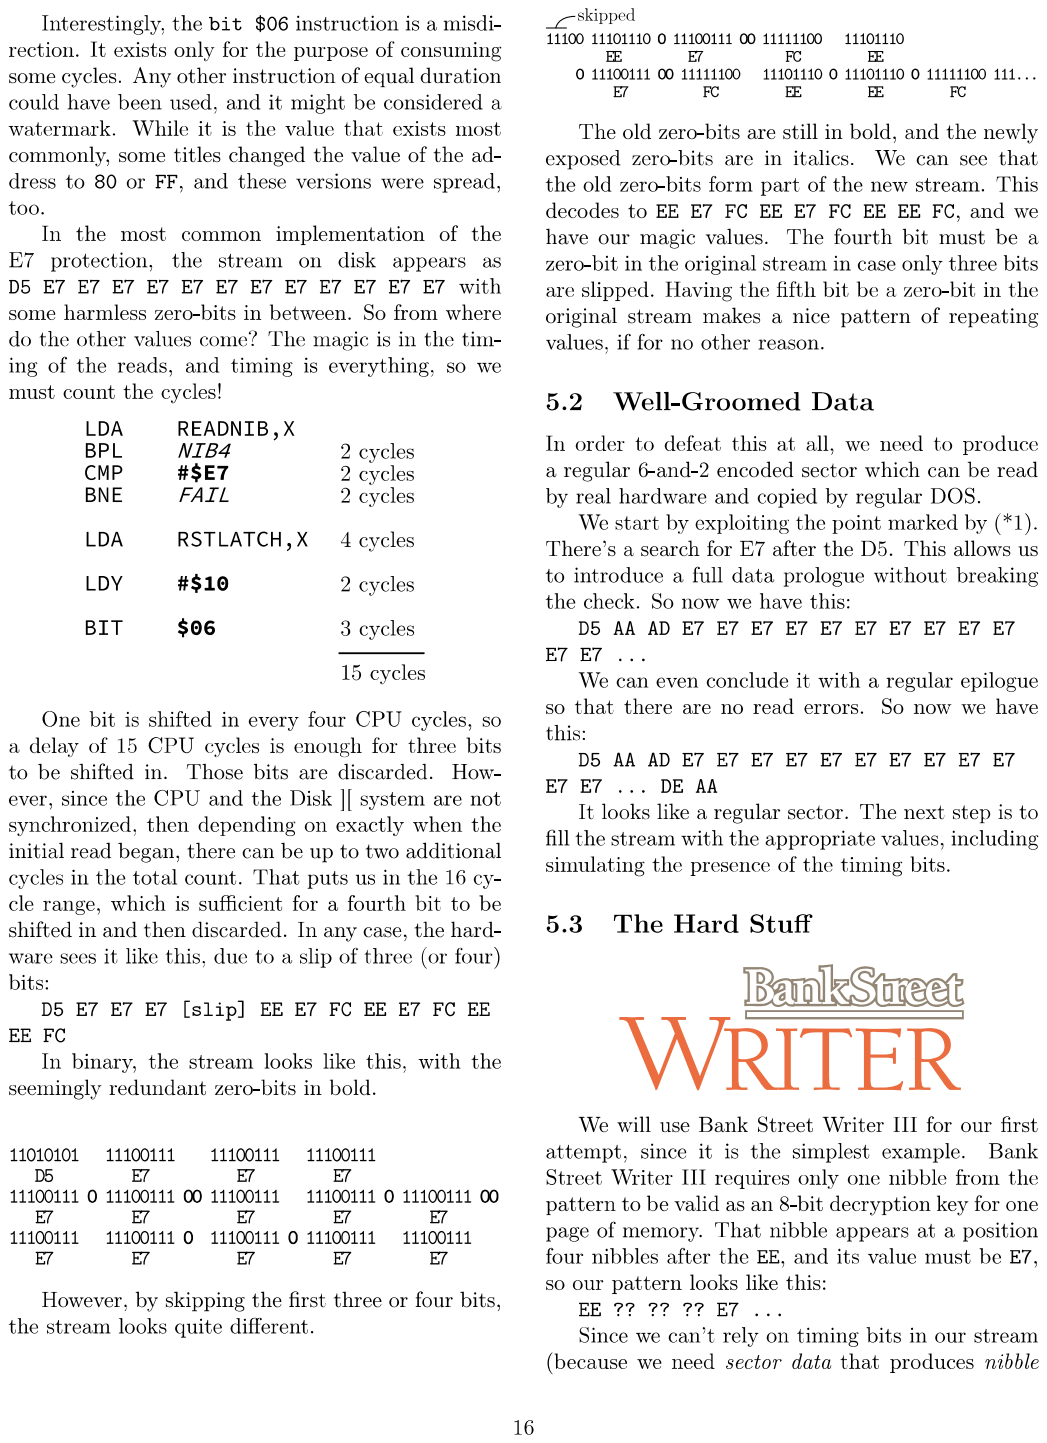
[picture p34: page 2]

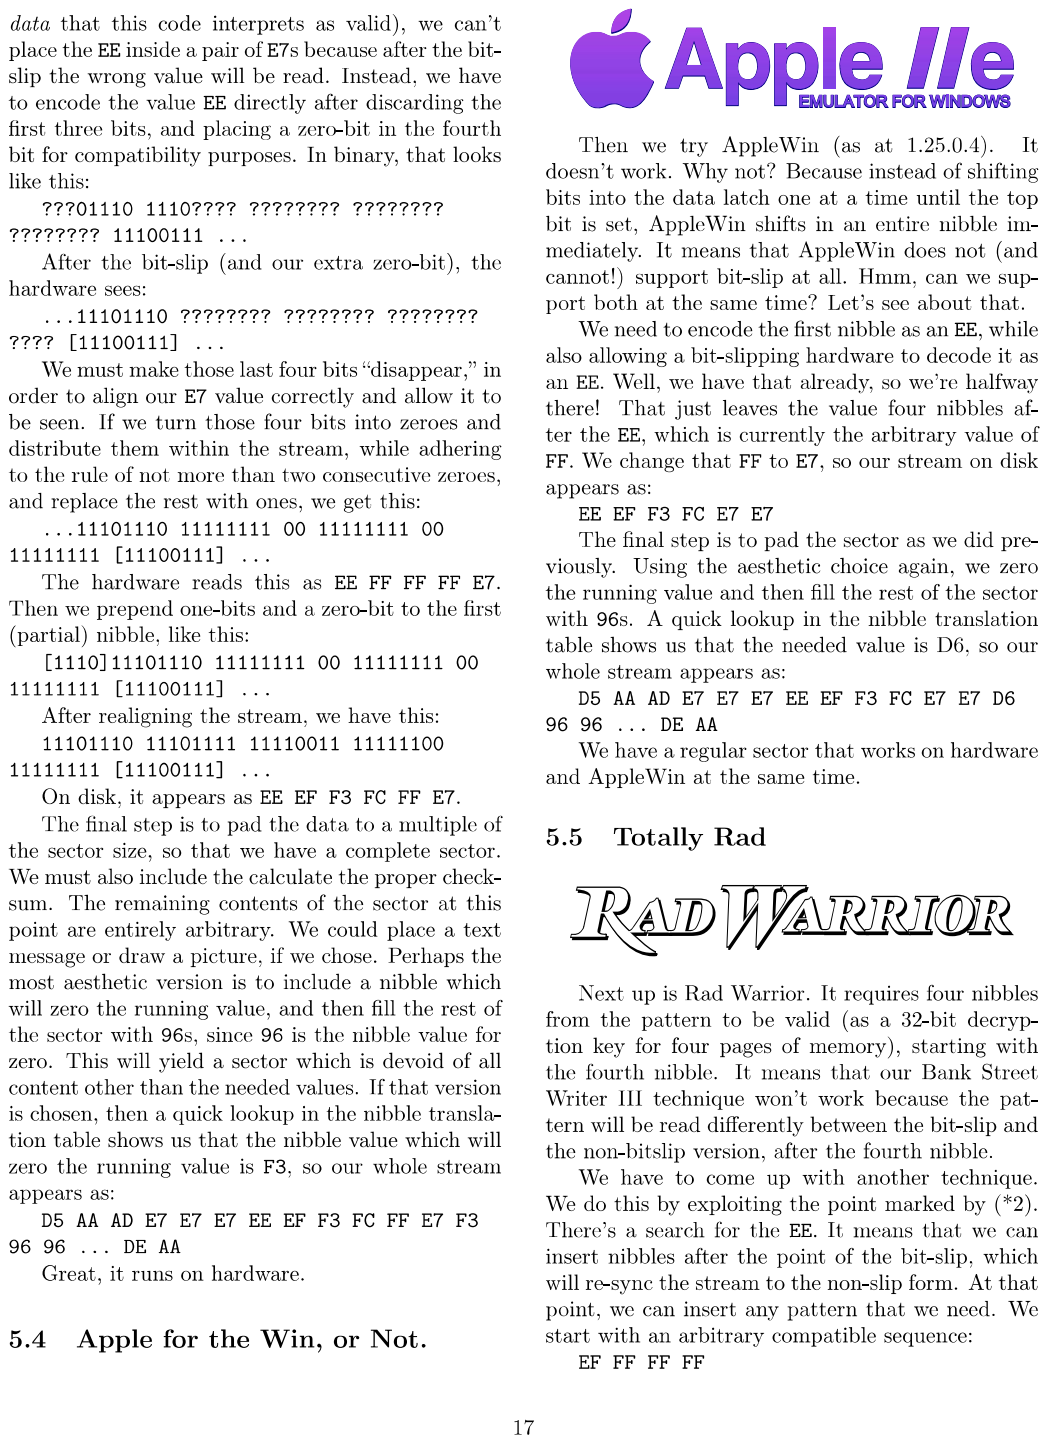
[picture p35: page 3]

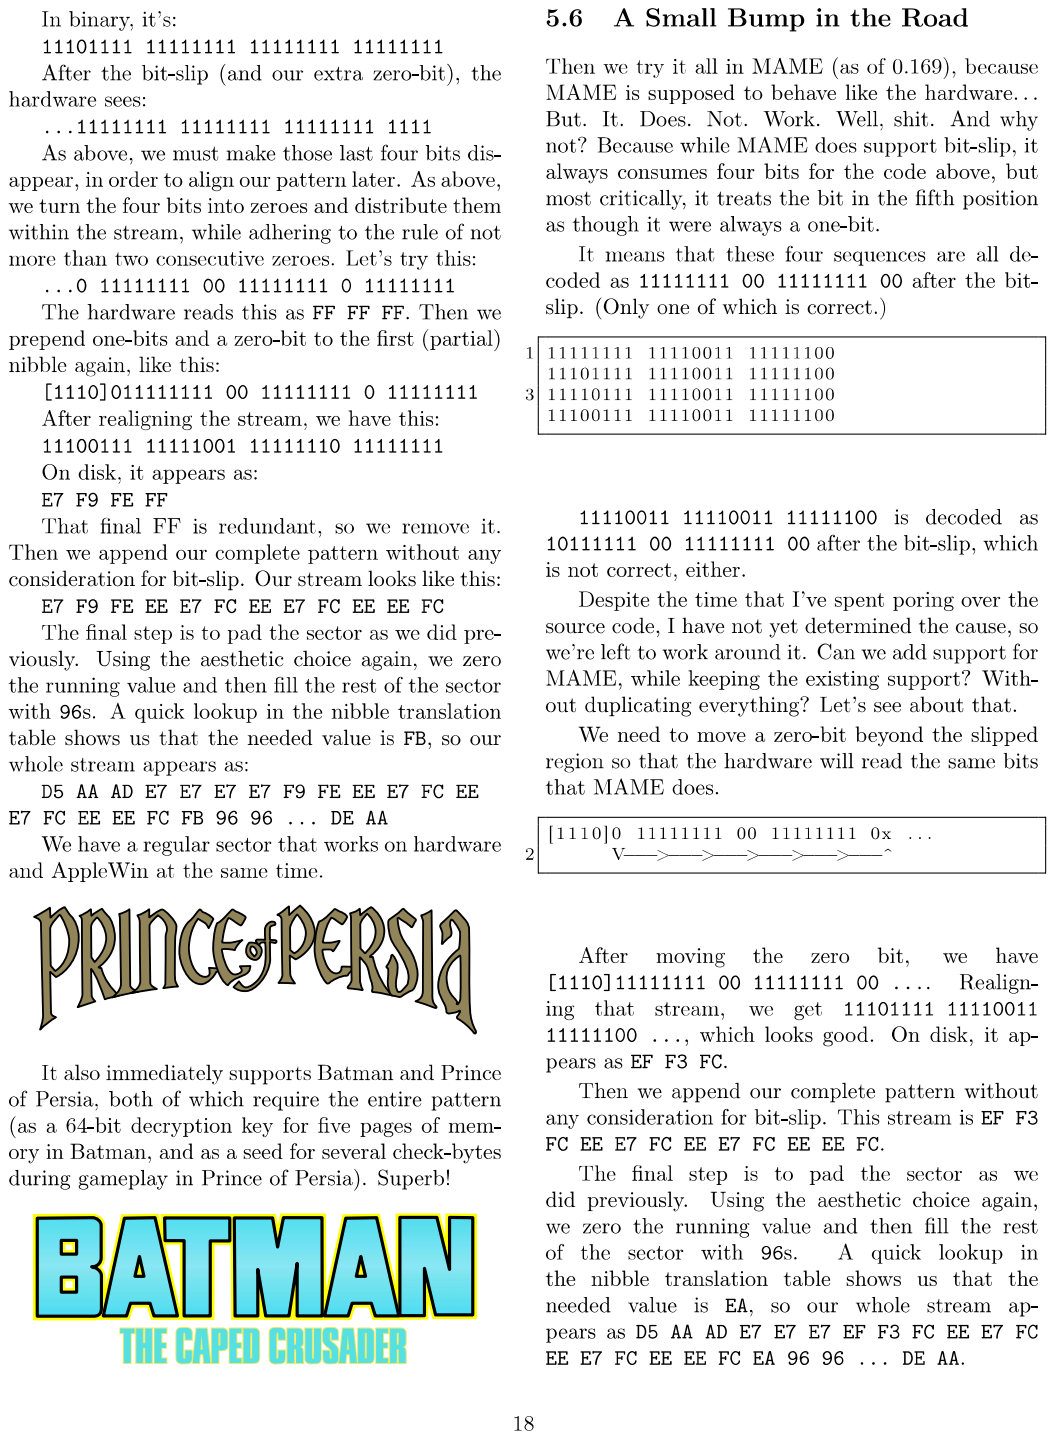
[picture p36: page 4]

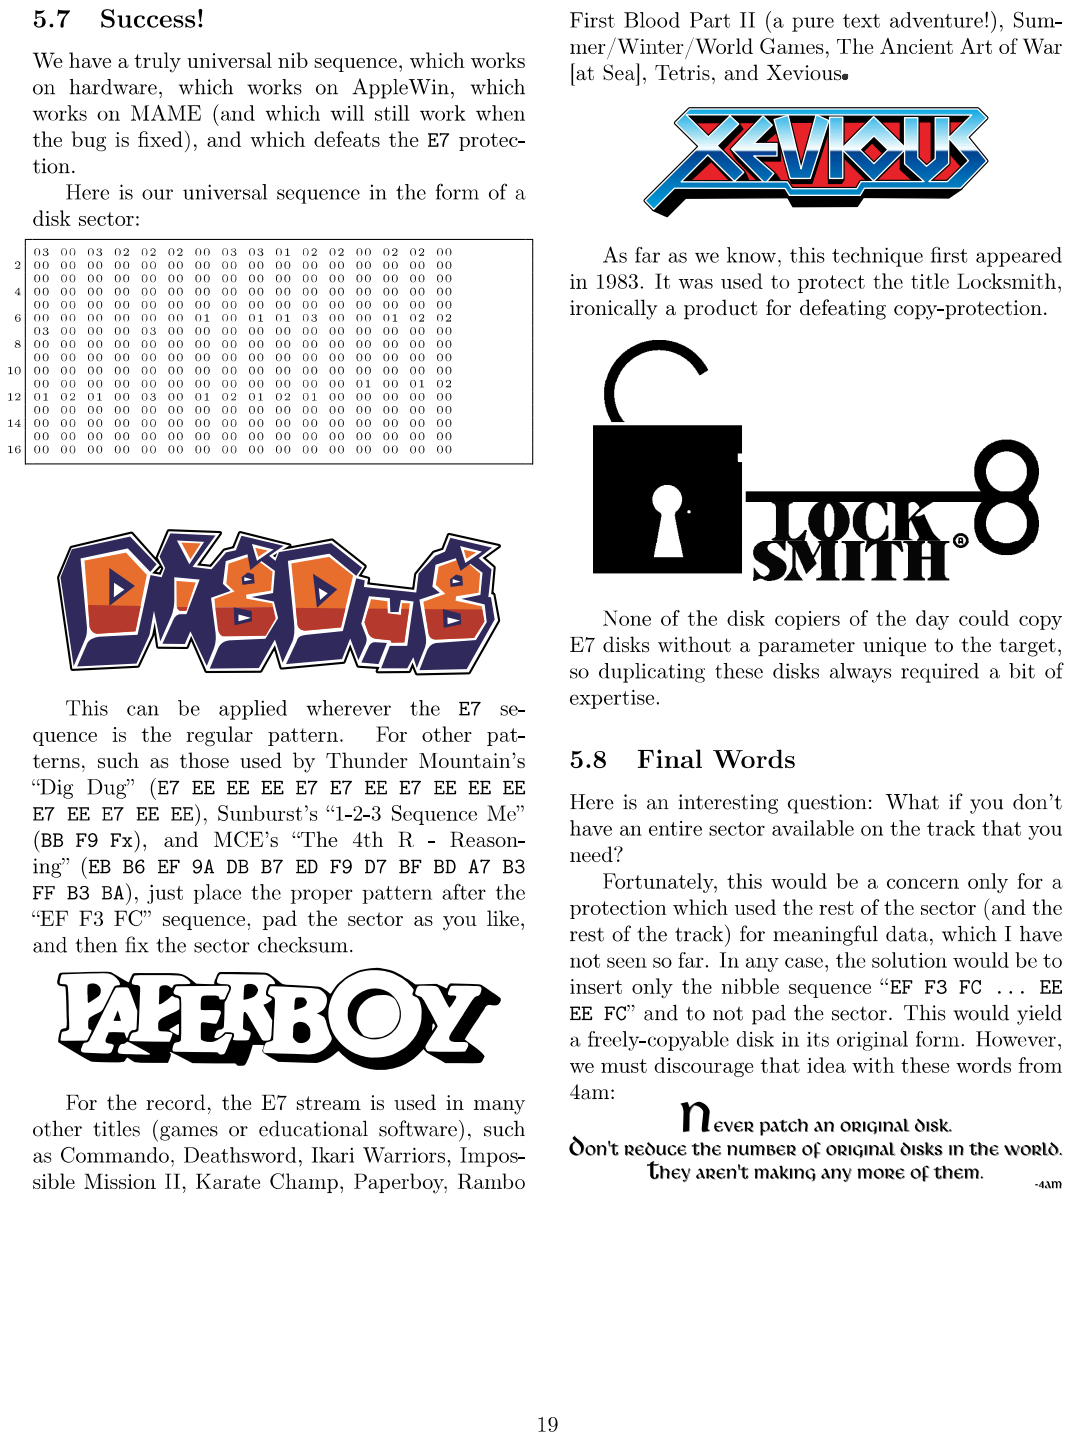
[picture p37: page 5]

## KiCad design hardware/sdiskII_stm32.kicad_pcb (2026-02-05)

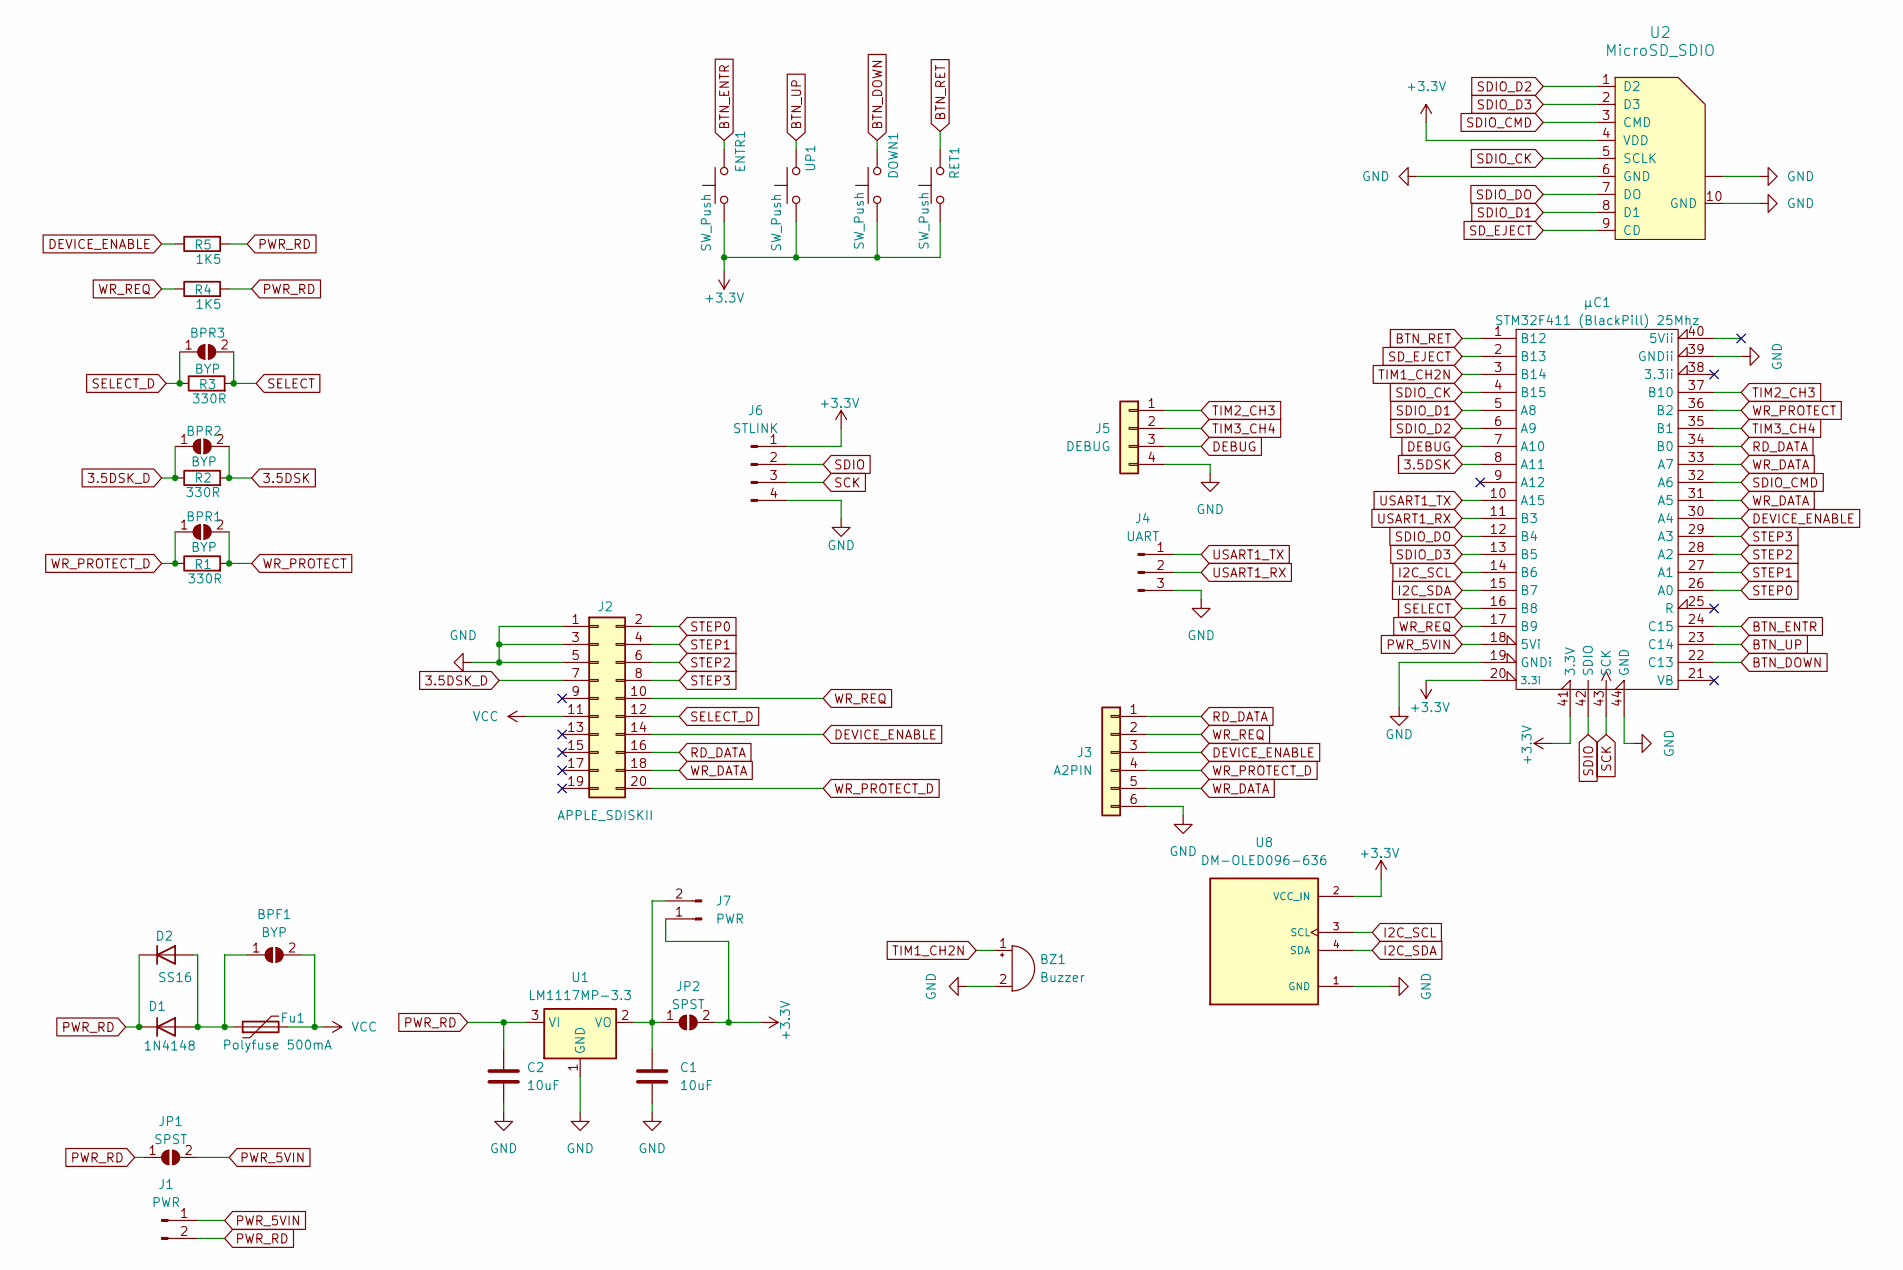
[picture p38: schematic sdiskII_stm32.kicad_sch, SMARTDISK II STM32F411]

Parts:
BPF1: BYP; SolderJumper-2_P1.3mm_Open_RoundedPad1.0x1.5mm
BPR1, BPR2, BPR3: BYP; SolderJumper-2_P1.3mm_Open_RoundedPad1.0x1.5mm
BZ1: Buzzer; AS-1201B-LF
C1, C2: 10uF; C_0805_2012Metric_Pad1.18x1.45mm_HandSolder
D1: 1N4148; D_DO-35_SOD27_P7.62mm_Horizontal
D2: SS16; D_SMA_Handsoldering
DOWN1: SW_Push; SW_PUSH_6mm
ENTR1: SW_Push; SW_PUSH_6mm
Fu1: Polyfuse 500mA; Fuse_0805_2012Metric_Pad1.15x1.40mm_HandSolder
J1, J7: PWR; PinHeader_1x02_P2.54mm_Vertical
J2: APPLE_SDISKII; IDC-Header_2x10_P2.54mm_Vertical
J3: A2PIN; PinHeader_1x06_P2.54mm_Vertical
J4: UART; PinHeader_1x03_P2.54mm_Vertical
J5: DEBUG; PinHeader_1x04_P2.54mm_Vertical
J6: STLINK; PinHeader_1x04_P2.54mm_Vertical
JP1, JP2: SPST; SolderJumper-2_P1.3mm_Open_RoundedPad1.0x1.5mm
R1, R2, R3: 330R; R_0805_2012Metric_Pad1.20x1.40mm_HandSolder
R4, R5: 1K5; R_0805_2012Metric_Pad1.20x1.40mm_HandSolder
RET1: SW_Push; SW_PUSH_6mm
U1: LM1117MP-3.3; SOT-223-3_TabPin2
U2: MicroSD_SDIO; GCT-MEM2055-00-190-01-A_VIB
U8: DM-OLED096-636; MODULE_DM-OLED096-636; PARTREV 2018-09-10
UP1: SW_Push; SW_PUSH_6mm
μC1: STM32F411 (BlackPill) 25Mhz; Mini_F4X1_STM32_VIB

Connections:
3.5DSK: BPR2.2 (B), R2.2, μC1.8 (A11)
3.5DSK_D: BPR2.1 (A), J2.7, R2.1
+3.3V: DOWN1.1, ENTR1.1, J6.1, J7.1, JP2.2 (B), RET1.1, U2.4 (VDD), U8.2 (VCC_IN), UP1.1, μC1.20 (3.3i), μC1.41 (3.3V)
BTN_DOWN: DOWN1.2, μC1.22 (C13)
BTN_ENTR: ENTR1.2, μC1.24 (C15)
BTN_RET: RET1.2, μC1.1 (B12)
BTN_UP: UP1.2, μC1.23 (C14)
DEBUG: J5.3, μC1.7 (A10)
DEVICE_ENABLE: J2.14, J3.3, R5.1, μC1.30 (A4)
GND: BZ1.2 (-), C1.2, C2.2, J2.1, J2.3, J2.5, J3.6, J4.3, J5.4, J6.4, U1.1 (GND), U2.6 (GND), U2.10 (GND), U2.~, U8.1 (GND), μC1.19 (GNDi), μC1.39 (GNDii), μC1.44 (GND)
I2C_SCL: U8.3 (SCL), μC1.14 (B6)
I2C_SDA: U8.4 (SDA), μC1.15 (B7)
unnamed: BPF1.1 (A), D1.2 (A), D2.2 (A), Fu1.1
unnamed: C1.1, J7.2, JP2.1 (A), U1.2 (VO)
PWR_5VIN: J1.1, JP1.2 (B), μC1.18 (5Vi)
PWR_RD: C2.1, D1.1 (K), D2.1 (K), J1.2, JP1.1 (A), R4.2, R5.2, U1.3 (VI)
RD_DATA: J2.16, J3.1, μC1.34 (B0)
SCK: J6.3, μC1.43 (SCK)
SDIO: J6.2, μC1.42 (SDIO)
SDIO_CK: U2.5 (SCLK), μC1.4 (B15)
SDIO_CMD: U2.3 (CMD), μC1.32 (A6)
SDIO_D1: U2.8 (D1), μC1.5 (A8)
SDIO_D2: U2.1 (D2), μC1.6 (A9)
SDIO_D3: U2.2 (D3), μC1.13 (B5)
SDIO_DO: U2.7 (DO), μC1.12 (B4)
SD_EJECT: U2.9 (CD), μC1.2 (B13)
SELECT: BPR3.2 (B), R3.2, μC1.16 (B8)
SELECT_D: BPR3.1 (A), J2.12, R3.1
STEP0: J2.2, μC1.26 (A0)
STEP1: J2.4, μC1.27 (A1)
STEP2: J2.6, μC1.28 (A2)
STEP3: J2.8, μC1.29 (A3)
TIM1_CH2N: BZ1.1 (+), μC1.3 (B14)
TIM2_CH3: J5.1, μC1.37 (B10)
TIM3_CH4: J5.2, μC1.35 (B1)
USART1_RX: J4.2, μC1.11 (B3)
USART1_TX: J4.1, μC1.10 (A15)
VCC: BPF1.2 (B), Fu1.2, J2.11
WR_DATA: J2.18, J3.5, μC1.31 (A5), μC1.33 (A7)
WR_PROTECT: BPR1.2 (B), R1.2, μC1.36 (B2)
WR_PROTECT_D: BPR1.1 (A), J2.20, J3.4, R1.1
WR_REQ: J2.10, J3.2, R4.1, μC1.17 (B9)

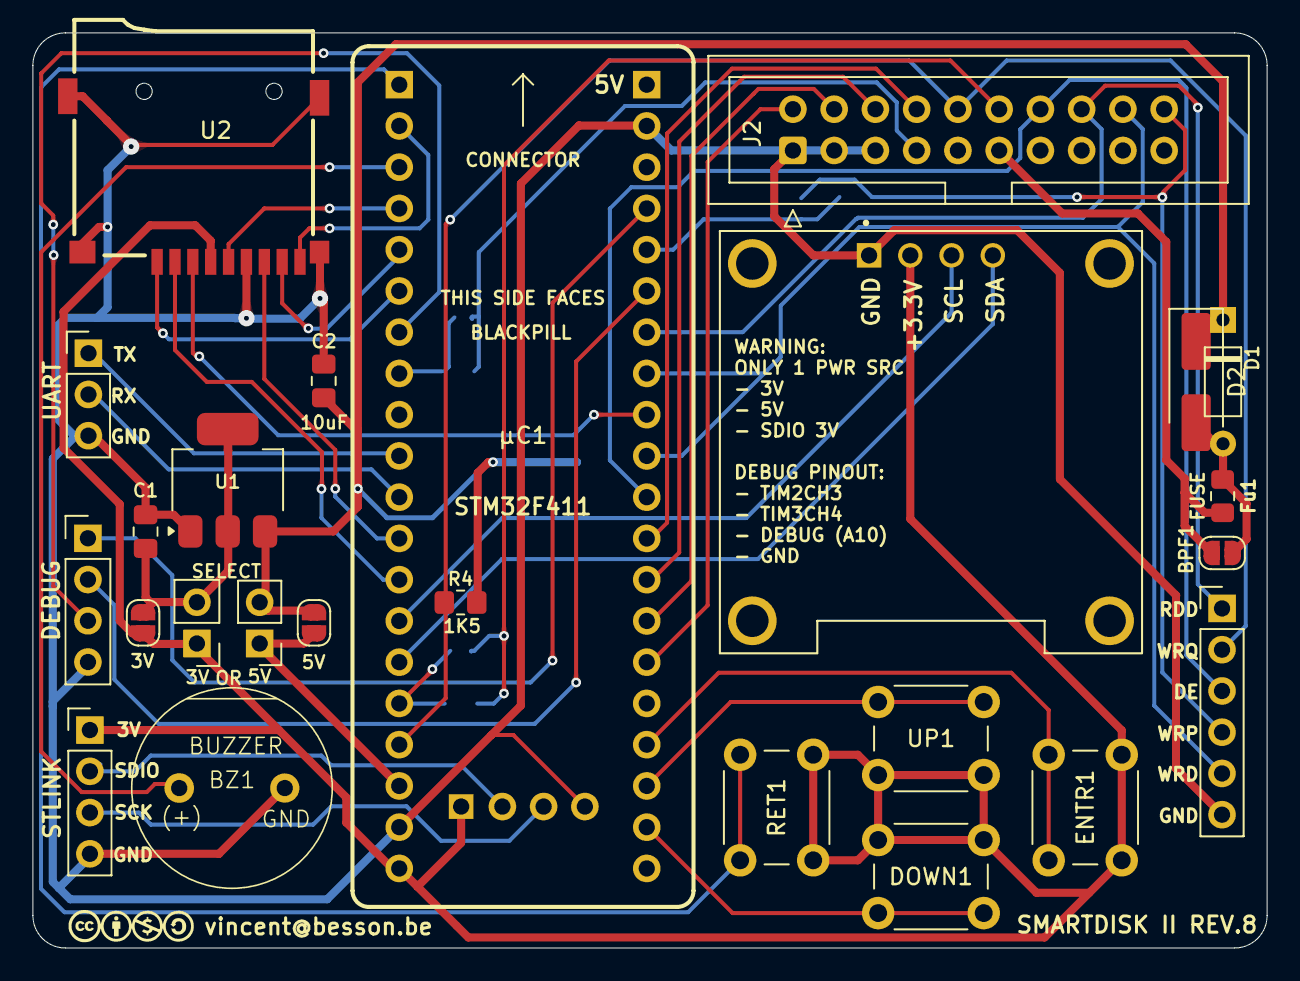
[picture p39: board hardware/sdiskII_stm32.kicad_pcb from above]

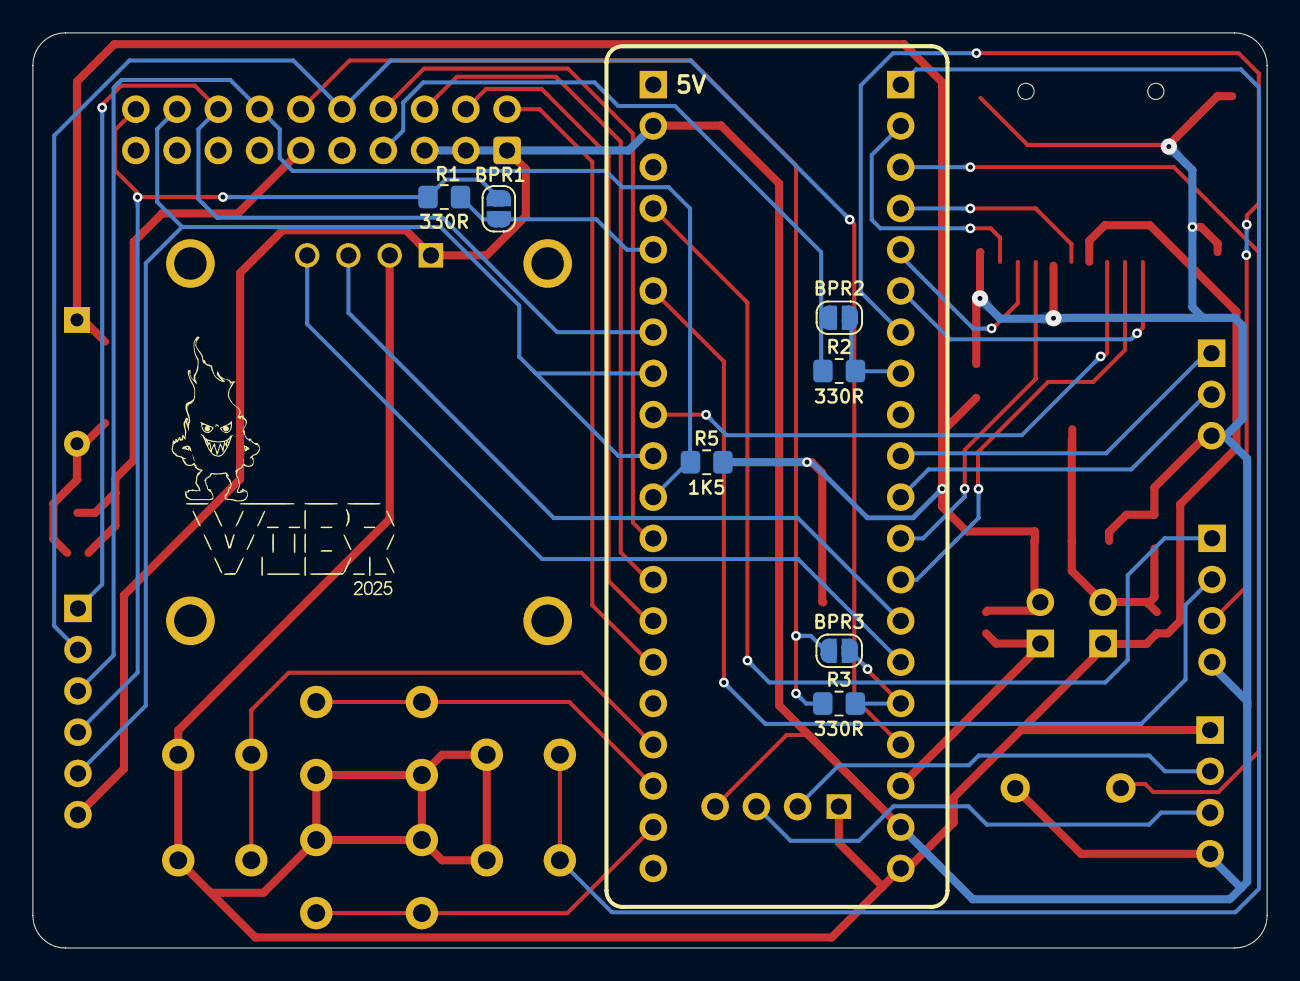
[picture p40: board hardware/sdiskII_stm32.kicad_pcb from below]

Board: 2 copper layers, 76.0 x 56.3 mm, 33 parts (7 on the bottom side), 42 nets.

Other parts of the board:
 : LOGO

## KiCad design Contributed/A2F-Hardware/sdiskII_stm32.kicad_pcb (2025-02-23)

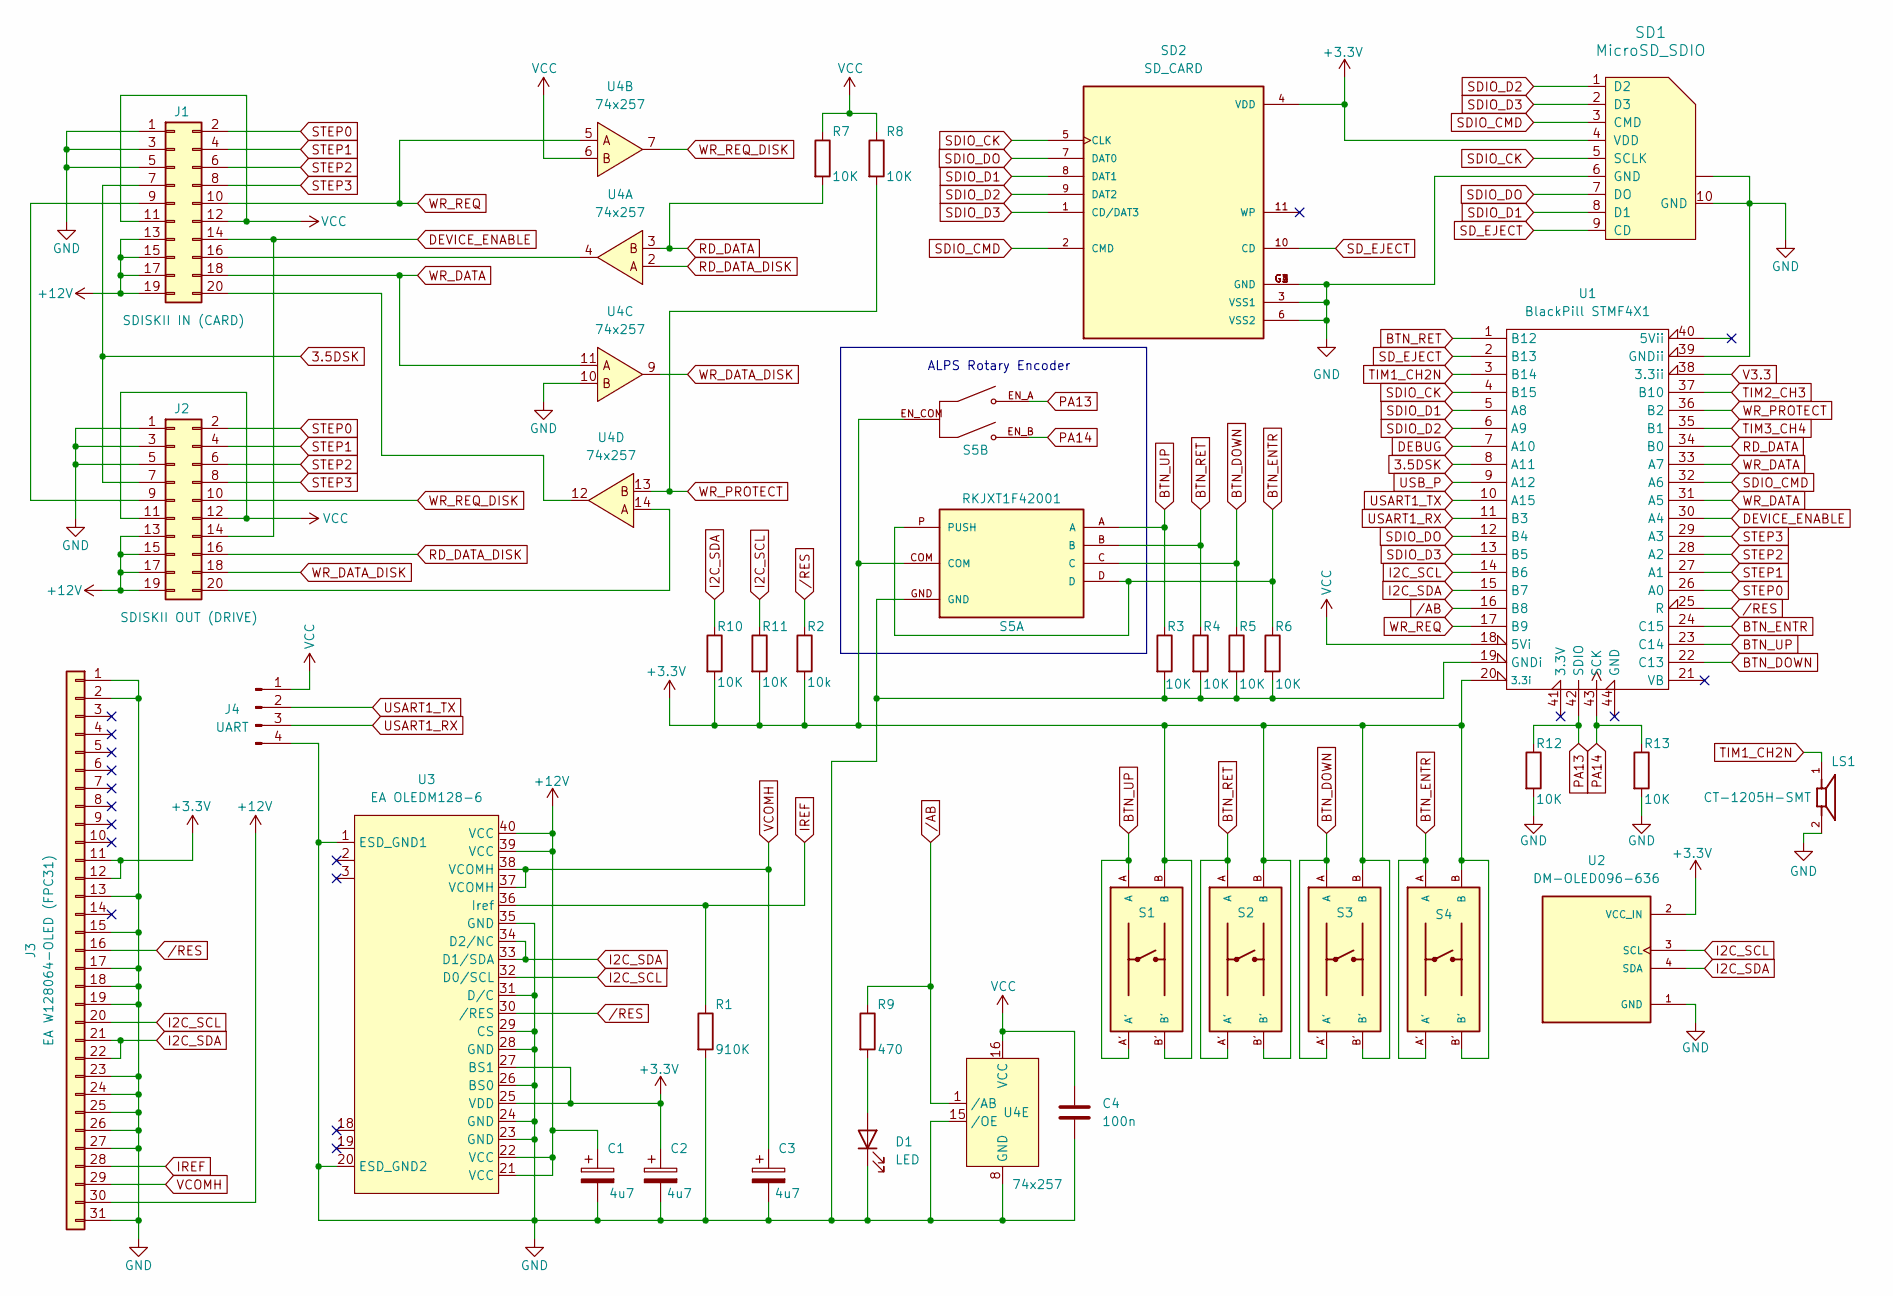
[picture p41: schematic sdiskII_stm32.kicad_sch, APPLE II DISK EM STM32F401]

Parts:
C1, C2, C3: 4u7; CP_EIA-3216-18_Kemet-A_Pad1.58x1.35mm_HandSolder
C4: 100n; C_0805_2012Metric_Pad1.18x1.45mm_HandSolder
D1: LED; LED_D3.0mm
J1: SDISKII IN (CARD); IDC-Header_2x10_P2.54mm_Vertical
J2: SDISKII OUT (DRIVE); IDC-Header_2x10_P2.54mm_Vertical
J3: EA W128064-OLED (FPC31); AMPHENOL_F32R-1A7H1-11031
J4: UART; PinHeader_1x04_P2.54mm_Vertical
LS1: CT-1205H-SMT; BUZZER CUI_CT-1205H-SMT; PART_REV 1.02
R1: 910K; R_0805_2012Metric_Pad1.20x1.40mm_HandSolder
R2: 10k; R_0805_2012Metric_Pad1.20x1.40mm_HandSolder
R3, R4, R5, R6, R7, R8, R10, R11, R12, R13: 10K; R_0805_2012Metric_Pad1.20x1.40mm_HandSolder
R9: 470; R_0805_2012Metric_Pad1.20x1.40mm_HandSolder
S1, S2, S3, S4: EVQ-Q2B02W; SW_EVQ-Q2B02W
S5: RKJXT1F42001; ALPS XDCR_RKJXT1F42001
SD1: MicroSD_SDIO; GCT-MEM2055-00-190-01-A_VIB
SD2: SD_CARD; SD_CARD_AMPHENOL_GMC020080HR; PARTREV AX6
U1: BlackPill STMF4X1; Mini_F4X1_STM32_VIB
U2: DM-OLED096-636; MODULE_DM-OLED096-636-SMAL; PARTREV 2018-09-10
U3: EA OLEDM128-6
U4: 74x257; SOIC-16_3.9x9.9mm_P1.27mm

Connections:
3.5DSK: J1.7, J2.7, U1.8 (A11)
+3.3V: C2.1, J3.11, J3.12, R2.2, R10.2, R11.2, S1.B, S1.B', S2.B, S2.B', S3.B, S3.B', S4.B, S4.B', S5.COM, S5.EN_COM, SD1.4 (VDD), SD2.4 (VDD), U1.20 (3.3i), U2.2 (VCC_IN), U3.25 (VDD), U3.27 (BS1)
+12V: C1.1, J1.13, J1.15, J1.17, J1.19, J2.13, J2.15, J2.17, J2.19, J3.30, U3.21 (VCC), U3.22 (VCC), U3.39 (VCC), U3.40 (VCC)
BTN_DOWN: R5.1, S3.A, S3.A', S5.C, U1.22 (C13)
BTN_ENTR: R6.1, S4.A, S4.A', S5.D, S5.P (PUSH), U1.24 (C15)
BTN_RET: R4.1, S2.A, S2.A', S5.B, U1.1 (B12)
BTN_UP: R3.1, S1.A, S1.A', S5.A, U1.23 (C14)
DEBUG: U1.7 (A10)
DEVICE_ENABLE: J1.14, J2.14, U1.30 (A4)
GND: C1.2, C2.2, C3.2, C4.2, D1.1 (K), J1.1, J1.3, J1.5, J2.1, J2.3, J2.5, J3.1, J3.2, J3.13, J3.15, J3.17, J3.18, J3.19, J3.23, J3.24, J3.25, J3.26, J3.27, J3.31, J4.4, LS1.2, R1.2, R3.2, R4.2, R5.2, R6.2, R12.2, R13.2, S5.GND, SD1.6 (GND), SD1.10 (GND), SD1.~, SD2.3 (VSS1), SD2.6 (VSS2), SD2.G1 (GND), SD2.G2 (GND), SD2.G3 (GND), SD2.G4 (GND), U1.19 (GNDi), U1.39 (GNDii), U2.1 (GND), U3.1 (ESD_GND1), U3.20 (ESD_GND2), U3.23 (GND), U3.24 (GND), U3.26 (BS0), U3.28 (GND), U3.29 (CS), U3.31 (D/C), U3.35 (GND), U4.8 (GND), U4.10, U4.15 (/OE)
I2C_SCL: J3.20, R11.1, U1.14 (B6), U2.3 (SCL), U3.32 (D0/SCL)
I2C_SDA: J3.21, J3.22, R10.1, U1.15 (B7), U2.4 (SDA), U3.33 (D1/SDA), U3.34 (D2/NC)
IREF: J3.28, R1.1, U3.36 (Iref)
unnamed: D1.2 (A), R9.2
unnamed: J1.9, J2.9
unnamed: J1.16, U4.4
unnamed: J1.20, U4.12
unnamed: J2.20, U4.14
PA13: R12.1, S5.EN_A, U1.42 (SDIO)
PA14: R13.1, S5.EN_B, U1.43 (SCK)
RD_DATA: R7.2, U1.34 (B0), U4.3
RD_DATA_DISK: J2.16, U4.2
SDIO_CK: SD1.5 (SCLK), SD2.5 (CLK), U1.4 (B15)
SDIO_CMD: SD1.3 (CMD), SD2.2 (CMD), U1.32 (A6)
SDIO_D1: SD1.8 (D1), SD2.8 (DAT1), U1.5 (A8)
SDIO_D2: SD1.1 (D2), SD2.9 (DAT2), U1.6 (A9)
SDIO_D3: SD1.2 (D3), SD2.1 (CD/DAT3), U1.13 (B5)
SDIO_DO: SD1.7 (DO), SD2.7 (DAT0), U1.12 (B4)
SD_EJECT: SD1.9 (CD), SD2.10 (CD), U1.2 (B13)
STEP0: J1.2, J2.2, U1.26 (A0)
STEP1: J1.4, J2.4, U1.27 (A1)
STEP2: J1.6, J2.6, U1.28 (A2)
STEP3: J1.8, J2.8, U1.29 (A3)
TIM1_CH2N: LS1.1, U1.3 (B14)
TIM2_CH3: U1.37 (B10)
TIM3_CH4: U1.35 (B1)
USART1_RX: J4.3, U1.11 (B3)
USART1_TX: J4.2, U1.10 (A15)
USB_P: U1.9 (A12)
V3.3: U1.38 (3.3ii)
VCC: C4.1, J1.11, J1.12, J2.11, J2.12, J4.1, R7.1, R8.1, U1.18 (5Vi), U4.6, U4.16 (VCC)
VCOMH: C3.1, J3.29, U3.37 (VCOMH), U3.38 (VCOMH)
WR_DATA: J1.18, U1.31 (A5), U1.33 (A7), U4.11
WR_DATA_DISK: J2.18, U4.9
WR_PROTECT: R8.2, U1.36 (B2), U4.13
WR_REQ: J1.10, U1.17 (B9), U4.5
WR_REQ_DISK: J2.10, U4.7
/AB: R9.1, U1.16 (B8), U4.1 (/AB)
/RES: J3.16, R2.1, U1.25 (R), U3.30 (/RES)

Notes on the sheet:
ALPS Rotary Encoder

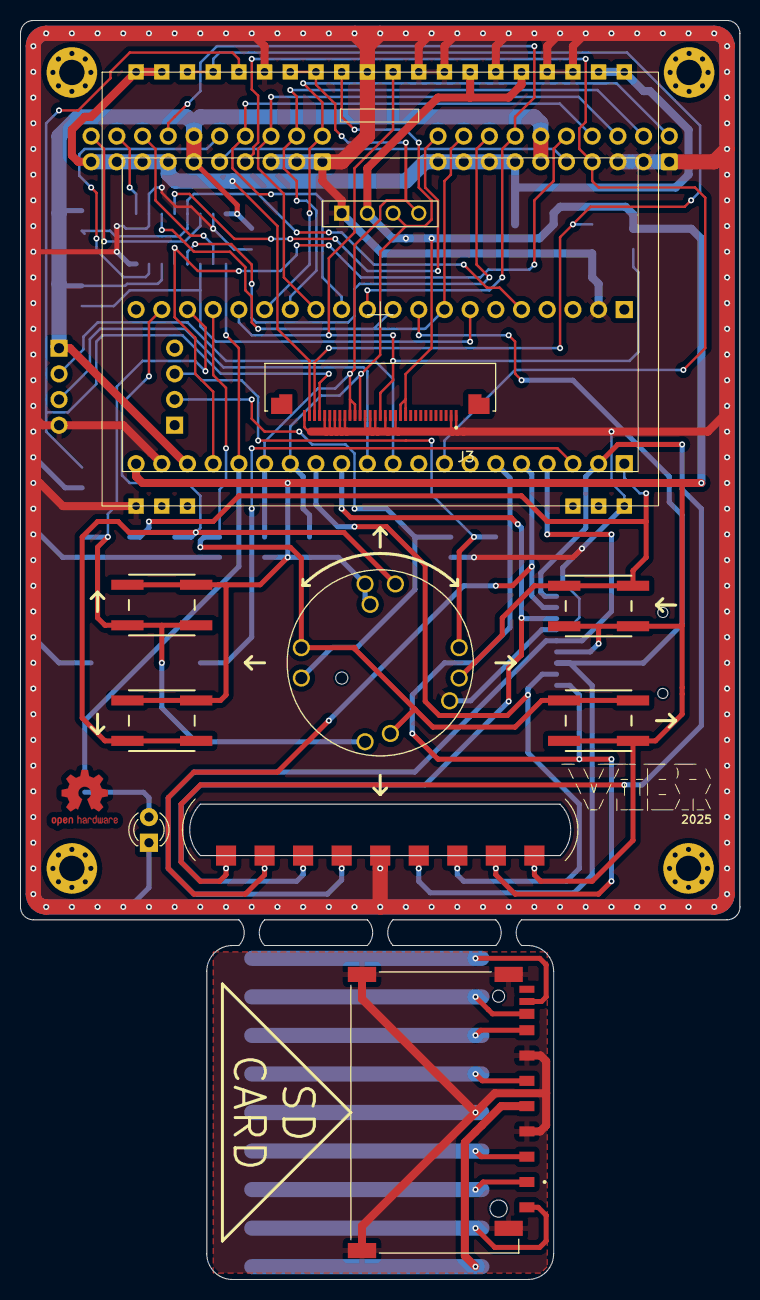
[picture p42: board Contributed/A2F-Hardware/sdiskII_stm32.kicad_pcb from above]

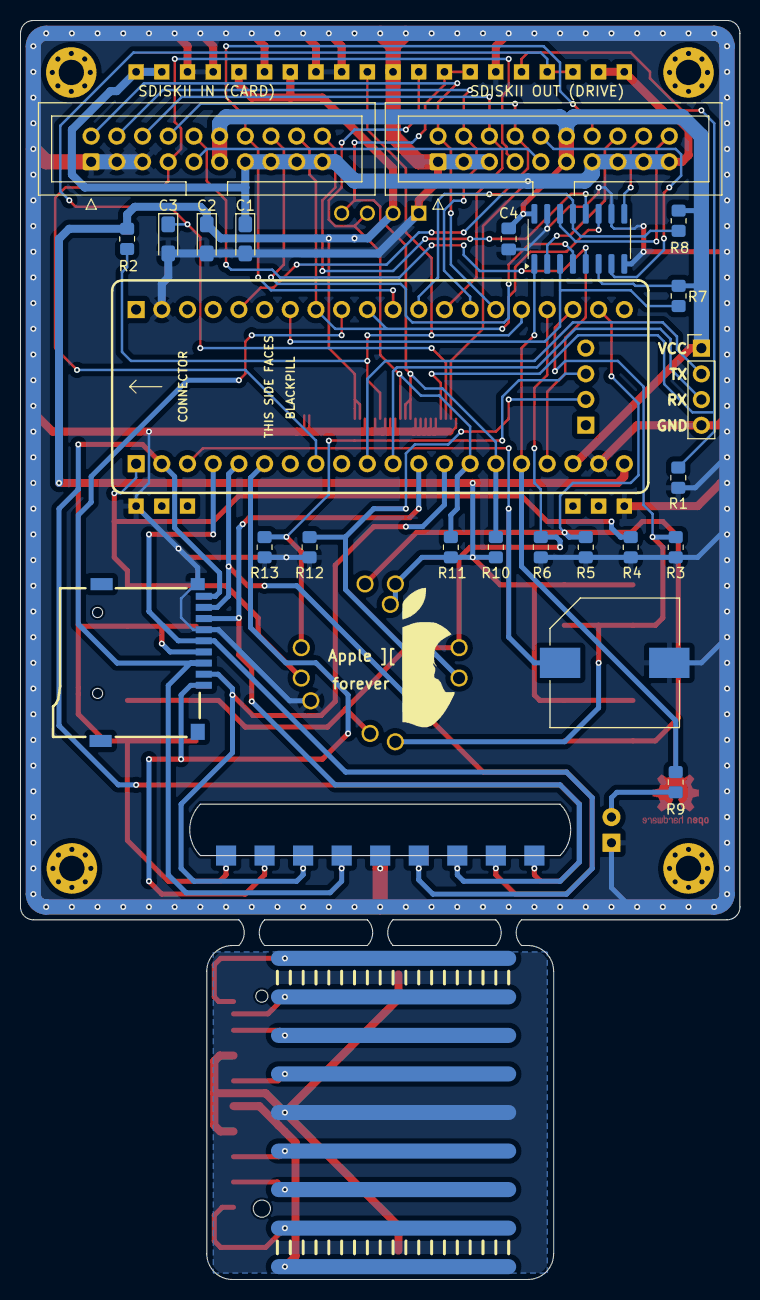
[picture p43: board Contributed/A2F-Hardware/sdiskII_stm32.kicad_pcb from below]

Board: 2 copper layers, 71.1 x 124.5 mm, 39 parts (24 on the bottom side), 44 nets.

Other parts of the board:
H1, H2, H3, H4: MountingHole_2.5mm_Pad_Via
VIBR: LOGO

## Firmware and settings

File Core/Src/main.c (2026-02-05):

/* USER CODE BEGIN Header */
/*
__   _____ ___ ___        Author: Vincent BESSON
 \ \ / /_ _| _ ) _ \      Release: 0.80.29
  \ V / | || _ \   /      Date: 2025.11.10
   \_/ |___|___/_|_\      Description: Apple Disk II Emulator on STM32F4x
                2025      Licence: Creative Commons
______________________


Todo:
- Add the screen PWR on a pin and not directly on the +3.3V
- Add 74LS125 to protect the STM32 against AII over current
- Add .2Mg file support
- Add feature request from Retro-Device A / B Head positioning 
- Adding on PCB jumper solder
- Adding on PCB Power Pin 11


Note 
+ CubeMX is needed to generate the code not included such as drivers folders and ...
+ An update of fatfs is required to manage long filename otherwise it crashes, v0.15 
+ stm32f411 blackpill v3 if SDIO Sdcard Management otherwise, any STM32fx would work with SPI / DMA,
+ Adding a manual procedure to simulate the headsync with noise

Navigation:
- Config items:
  - makefs
  - boot last or boot favorite
  - fs save current dir
  - wipe favorites
  - wipe config
  
Lessons learned:
- IIGS in Fast mode, emulation diskII does not work, suspecting phase signal to be shorted
- Warning screen update with DMA while SDIO is running can perform SDIO error
- When SDIO appears one way is to investigate is to disable all interrupt & renable one by one
- Using a clock divider is also helping, clockDIV by 2 is solving the SDCard issue
- SDCard need to be formated with 64 sectors of 512 Bytes each / cluster mkfs.fat -F 32 -s64 
- SDCard CMD17 is not fast enough due to wait before accessing to the bloc (140 CPU Cycle at 64 MHz), prefer CMD18 with multiple blocs read,

- Bitstream output is made via DMA SPI (best accurate option), do not use baremetal bitbanging with assemnbly (my first attempt) it is not accurate in ARM with internal interrupt,
- Use Interrupt for head move on Rising & Falling Edge => Capturing 1/4 moves
- Warning Bootloader might take too much time to load and thus missing the headsync procedure,
- When there is a filesystem issue at start up it is sometime due to f_stat file to take long and generate an error for an image in config that does not exists on the filesystem


Current status: READ PARTIALLY WORKING / WRITE Experimental
+ Woz file support : in progress first images are working
+ NIC file support : in progress first images are working

"tasks": [
			{
				"label": "FatFs CleanUP",
				"type": "shell",
				"command": "cd ./Middlewares/Third_Party/FatFs; pwd; dir; /bin/bash ./r015.sh",
				"options": {
					"cwd": "${workspaceRoot}"
				},
				"group": {
					"kind": "build",
					"isDefault": true
				},
				"problemMatcher": [
					"$gcc"
				]
			},

Architecture:
- TIM1 Timer 1 : Use to Manage passive buzzer PWM on PIN 14 (Channel 2N), via a PWM 
- TIM2 Timer 2 : Use to Manage the WR_DATA, ETR1 Slave Reset mode to resync with the A2 Write Pulse that is 3.958 uS instead of 4uS. Every Rising Edge resync
- TIM3 Timer 3 : Use to Manage the RD_DATA, 
- TIM4 Timer 4 : Internal no PWM, debouncer for the control button
- TIM5 Timer 5 : Marquee Text Management on the OLED Screen
- TIM9 Timer 9 : Screen Saver timer (if enable)
- TIM10 Timer 10 : Buzzer start / stop management
GPIO
  - PA10 DEBUG 

BTN
  - PC13 BTN_DOWN
  - PC14 BTN_UP
  - PC15 BTN_ENTR
  - PB12 BTN_RET

STEP
  - PA0 STEP0
  - PA1 STEP1
  - PA2 STEP2
  - PA3 STEP3

  - PB09 WR_REQ
  - PB02 WR_PROTECT
  - PA04 DEVICE_ENABLE
  - PB13 SD_EJECT

SDIO
  - PB4 DO
  - PA8 D1
  - PA9 D2
  - PB5 D3
  - PA6 CMD
  - PB15 CK

I2C Screen SSD1306
  - PB06 SCL
  - PB07 SDA

UART1
  - PA15 TX
  - PB3 RX

*/ 

// Changelog

/*
24.11.25 v0.80.33
  + Smartloader update with Fav shortcut, Emulatation type shortcut, and last folder memory
  
16.11.25 v0.80.31
  + add screen update with WR displayed during write process
  + Fixing issue with write process not working after several writes
  + Adding missing variable reset for write process
  + Fixing issue with buzzer not stopping after play_buzzer_ms function
  + Adding flgSoundEffectActive to avoid overlapping sound effect
  + Fixing DOS Init process and rewrite of the write process
  + Timing adjustment on write process to match better the Apple II timing
  + Adjusting IIGS constraints
  + YellowStone card tested OK with write process
  + Fixing state of SDCard during switch from write to read mode (add a small delay to check state of the SD)
  + Adding Marquee text effect, scrolling text on the OLED screen
  + Fixing minor issue on marquee text rendering
  + Changing Buzzer timer to 10

  WOZ test :
    + Blazing Paddles working OK
    + Borderzone KO
    + Bouncing Kamungast working OK
    + Hard Hat Mike working OK
    + Crisis Mountain working OK
    + Dino Eggs working OK
    + First Math Adventures working OK
    + The print Shop Companion working OK (Use Weak Bit feature)
    + Commando working OK (Use Weak Bit feature)
    + Miner 2049er II working OK
    + Planetfall working OK
    + Rescue Raiders working OK
    + Sammy Lightfoot working OK
    + The Bilestoad working OK
    + Stickybear Town Builder working OK
    + Take 1 working OK

Issue:
  [DiskII] after image mounting, boot is not happening, need to reset
  
Question:
  Do we still need the checkstatus on the SD at the end of the loop to avoid deadlock ?



30.10.25 V0.80.29
  + Modify TIM5 to be used with Buzzer
  + Unblocking code for Buzzer Management
  + PacketLen() clean up
  + Fixing minor issue on Smartport write checksum calculation
  + Screensaver timer management fix
  + Fixing deadlock on buzzer
  + blocking Smartport fix
  + Adding Smartloader Emulation type switch in main menu
  + Adding Smartloader navigation to file Manager
  + Adding Smartloader auto boot sequence 5s
  + add specific boot sequence for IIGS 

27.10.25
  + Board v8 final version
  + [Smartport] fixing timing issue on IIc
  + [Smartport] fixing data flow
  + [Smartport] reinit multiple disk
  + [Smartport] correcting C8 at the end of request phase
  + [Smartport] suppression of timer guiderail
  + [Smartport] reactivate checksum validation

19.10.25
  + [Configuration] detecting corrupted json, with default
  + [Smartloader] fixing display glitch
  + [Smartloader] adding page + page - management
  + [Smartloader] fixing M key code
11.10.25 v0.80.23
  + [SmartLoader] fixing updir navigation
  + [SmartLoader] back to main with M (Uppercase)@

12.08.25 v0.80.18
  + [Main] Adding ScreenSaver feature to save the OLED, switch off every 60 min if activated in setting
  + [Settings] Adding ScreenSaver Option
  + [SmartLoader] Change of Address range for the new version of smartloas based on RWTS
03.08.25 v0.80.17
  + [Emulation] Adding a new setting in emulation type with smartloader to launch smartloader at startup
27.07.25 v0.80.16
  + [Smartloader] Add multipage feature, left and right arrow
  + [Smartloader] Add last folder saved for next reboot
  + [Smartloader] fix loading of image (sometime it was crashing)
  + [Smartloader] adding 20ms delay after reading block to avoid dead lock
  + [Smartloader] move arm track by one to enable easy reread in case of error
20.05.25 v0.80.13
  + [SMARTPORT] Fixing deadlock on FS access
  + [SMARTPORT] Manage Eject of Image and Disk present / not present
19.05.25 v0.80.12
  + [FATFS] changing strfunc in conf
  + [Smartport] adding ROM03 reinit devicelist
  + [Smartport] adding break on timeout
  + [Smartport] adding break on checksum failed to avoid corruption of sdcard block
  + [MAIN] adding TIM5 to manage deadlock
  + [PCB] beta release of PCB v6
10.04.25 v0.80.11
  + [Smartport] adding support for hdv file extension
  + [diskII] fix corrupted track on successive basic file writing
  + [diskII] fix empty directory when booting last directory
04.04.25 v0.80.9
  + Fixing instability on SDCard Access (Removing the constraints on DMA & SDIO IRQ)
26.03.25 v0.80.7
  + Fixing Favorites Screen
  + Adding Favorites to Smartport HD
  + Adding option to select boot index directly from Smartport Image
  + Adding toogle favorites SmartportHD
  + Display Fav Icon
26.03.25 v0.80.6
  + [SDEJECT] Disk Creation from Filesystem (PO,DSK,...)
  + [SDEJECT] Fixing SD Eject function for all emulator
  + [MAINMENU] Making the main menu dynamic according to emulation type
  + [UNIDISK / HD EDJECT] Manage Eject request from Smartport on update screen on SmartDisk
  + [SMARTPORT ] checksum and write fix
  + [SMARTPORT ] deadlock on some read query to Ack not asserted, workaround
22.03.25 v0.81
  + [SDEJECT] Fixing SD Eject function for all emulator
  + [MAINMENU] Making the main menu dynamic according to emulation type
  - [UNIDISK / HD EDJECT] Manage Eject request from Smartport on update screen on SmartDisk
  - [SMARTPORT WRITE KO] error on checksum to be fixed 
22.03.25 v0.80.5d
  + [DSK/PO] write process
  + [DSK/PO] sector skewing
  + [READ] optimize function timing duration
  + [WRITE] GCR_6_2 chksum comp
  + [WEAKBIT] option in setting
  + [UNIDISK 2MG] Full emulation of SMartport Unidisk with 2MG image file
  + [DISPLAY] Huge code clean up
06.03.25
  + [ALL] code refactoring
  + [FS] Adding directory option
  + [SDEJECT] Removing HAL, bitbanging to GPIO
  + [SDEJECT] Add function trigger to emul loop
  + [SDEJECT] Add sysreset after sdcard reinserted
03.03.25 v0.80.5
  + Add extension filter to walkdir depending of the type of emulator 
26.02.25 v0.80.4
  + [Smartport] mount regression fix
  + [Smartport] 2mg file ext disp fix
  + [WOZ] Correcting head / sector / region calculation
  + [FS]  Adding "." item on every location to add future access to option
  + [FATFS] Change conf of FATFS to manage STRFUNC
  + [WOZ] Passing the wozardry verify & dump test for both 3.5 & 5.25
  + [WOZ] Manage CRC32
  + [WOZ] Adding Blank woz file creation for 3.5
  + [WOZ] Adding Blank woz file creation for 5.25
  - [Smartport IIGS] TODO: Fix Splashscreen duration with Animation
  - [WOZ] TODO: blank WOZ 3.5 1 Byte slip to fix

23.02.25 v0.80.3
  + [All] Code cleaning, compilation warning cleaning
  + [Smartport] 2MG Extension checking fixed
  + [2MG] Fixing 2MG mount blockCount function
  + [Smartport] Fixing Missing Extended DIB Status
  + [SmartPort] Managing errorCode on CMD
  + [SmartPort] code refactoring
  + [SmartPort] Working on 2MG file support with Smartport
  + [SmartPort] Changed deviceType & subType according to the type of diskFormat (PO & 2MG)
  + [SmartPort] Added Standard Extended Function Call
  + [Merged] Merge code with A2F Contributor JoSch
  + [Display] Fixing some code on display
20.02.25 v0.80.2
  + Add confirmation screen MakeFS
  + Change display of MakeFS
  + MKFS on the Main Thread and not by interrupt
  + Deep work on 2MG & disk35
06.02.25 v0.80.1
  + [SmartPort] Fixing Smartport write process, and it WORKS!!!
  + [SmartPort] Managing incomming checksum command
  + [SmartPort] Optimizing read time 

02.02.25 v0.79.6
  + [Smartport] Fixing boot duration adjust to 500ms IIGS boot issue
02.02.25 v0.79.5
  + [ALL] Changing Timer 2 period -1
  + [SmartPort] Fixing mounting image
  + [SmartPort] Fixing SmartPort boot order
  + [SmartPort] Fixing SmartPort boot index
  + [SmartPort] Fixing display Image
  + [SmartPort] Adding display status
30.01.25 v0.79.4
  + Fix Menu item (Emulation / Sound)
  + Fix Menu <4 item navigation 
26.01.25 v0.79.3
  + Smartport HD list of loaded image on screen
  + Smartport HD remove HAL GPIO overhead on WRITE Process
  + Case v3 
24.01.25 v0.79.2 
  + Add Boot image index for Smartport
  + Woz write process working
  + bug fix on DMA management
  + Smartport fix (still need to work on the write process...)
  + Fix the TIMER perid to receive data
  + Move away ffrom HAL function and use baremetal GPIO 
  + Freeup unused buffer 6K
  + Init DOS3.3 working with delay write
26.12.24 v0.79.1
  +Remove hardcoded emulation type
13.12.24  v0.79
  +Fix: complete code restructuring to enable different emulation type
  +Feat: Add Smartport HD emulation type
  +Feat: Add Config menu to manage emulation type
  +Feat: Manage physical head positioning for Disk A & B

25.11.24: v0.78.4
  +Feat: Locksmith Certify works and Fast copy also
25.11.24: v0.78.3
  +Feat: makefs in the menu config
  +Fix: compilation option for fatfs mkfs
  +Fix : add fatfs label option
  +Feat: add confirmation question on mkfs from menu config
  +Fix: variable casting uint8 instead of int in getConfigParamUInt8
  +Fix: Empty SDCard crash, sortlst check for empty chainedlist
  +Feat: writing part 1 setting the woz driver function
  +Feat: writing part 2 correct write bitstream and fix bit shift
24.11.24: v0.78.2
  +Fix: bootloader delay providing a coldstart issue on several images
23.11.24: v0.78.1
  +Fix: Spiradisc fix, screenupdate was before memcopy was generation an extra delay and thus failing with cross track sync
22.11.24: v0.78
  +fix: WOZ more than 40 trk disk such as lode runner, add Max TRK

22.11.24: v0.77
  +fix: DSK reading, wrong NIBBLE_BLOCK_SIZE from 512 to 416
  +fix: NIC reading, wrong NIBBLE_BLOCK_SIZE from 512 to 416

20.11.24: v0.76
  +fix: weakbit issue, changing the threshold to 4 (instead of 2), Bouncing Kamungast is working
  +fix: weakbit the Print shop is now working, wrong variable used
  +fix: buzzer sound change after button is pressed (prescaler was not reset)
  +fix: woz file info properties not correctly propagated to flg variable
  +fix: harvey ball to be fixed

04.11.24: v0.72
  +fix: directory with name of 1 char not read by the emulator
  +fix: PO/po file extension add to the list of extension
  +feat: add menu image (toggle Favorite, unmount, unlink)
  +fix SDIO IRQ for unlink
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
int main(void)
{

  /* USER CODE BEGIN 1 */

  

  

  FRESULT fres;
  /* USER CODE END 1 */

  /* MCU Configuration--------------------------------------------------------*/

  /* Reset of all peripherals, Initializes the Flash interface and the Systick. */
  HAL_Init();
  //HAL_Delay(1500);
  /* Configure the system clock */
  SystemClock_Config();

  /* USER CODE BEGIN SysInit */
  
  // --------------------------------------------------------------------
  // ptr declaration needs to be before NVIC init
  // --------------------------------------------------------------------


  
  ptrPhaseIRQ=nothingHook;
  ptrReceiveDataIRQ=nothingHook;
  ptrSendDataIRQ=nothingHook;
  ptrWrReqIRQ=nothingHook;
  //ptrSelectIRQ=nothingHook;
  ptrDeviceEnableIRQ=ui16NothingHook;
  ptrMainLoop=nothingHook;
  ptrUnmountImage=statusNothingHook;
  ptrMountImagefile=statusNothingHook;
  ptrInit=nothingHook;
  
  /* USER CODE END SysInit */

  /* Initialize all configured peripherals */
  MX_GPIO_Init();
  MX_DMA_Init();
  MX_I2C1_Init();
  MX_USART1_UART_Init();
  MX_TIM3_Init();
  MX_FATFS_Init();
  MX_TIM4_Init();
  MX_SDIO_SD_Init();
  MX_TIM2_Init();
  MX_TIM1_Init();

  MX_TIM5_Init();
  MX_TIM9_Init();

  /* Initialize interrupts */
  MX_NVIC_Init();
  /* USER CODE BEGIN 2 */

  log_set_level(LOG_INFO);
  
#ifdef A2F_MODE
  // store rotary encoder state
  re_aState = HAL_GPIO_ReadPin(RE_A_GPIO_Port, RE_A_Pin);
  re_bState = HAL_GPIO_ReadPin(RE_B_GPIO_Port, RE_B_Pin);
  re_aChanged = false;
  re_bChanged = false;
#endif

  //GPIOWritePin(WR_PROTECT_GPIO_Port, WR_PROTECT_Pin, GPIO_PIN_SET); 

  currentFullPathImageFilename[0]=0x0;
  currentFullPath[0]=0x0;
  tmpFullPathImageFilename[0]=0x0;

  //log_info("************** BOOTING ****************");                      // Data to send
  log_info("**     This is the sound of sea !    **");
  //log_info("***************************************");
    
  //printf("%02X",smartloader_bin[1]);

  fres = f_mount(&fs, "", 1);                                                 // <!> Warning Mount opt 1 very important or it does not work                                     
  
  if (fres!=FR_OK){
    log_error("not able to mount filesystem");
  }

  csize=fs.csize;
  database=fs.database;
  
  //GPIO_InitTypeDef GPIO_InitStruct = {0};                                             // This Pin should be High on IIGS but connected to Ground Disk II 
  /*GPIO_InitTypeDef GPIO_InitStruct = {0};
  GPIO_InitStruct.Pin = SELECT_Pin;                                                   // 
  GPIO_InitStruct.Mode = GPIO_MODE_INPUT;
  GPIO_InitStruct.Pull = GPIO_PULLDOWN;
  HAL_GPIO_Init(SELECT_GPIO_Port, &GPIO_InitStruct);
    */
  initSplash();
                                  
  HAL_Delay(100);

//#include "ssd1306.h"
//ssd1306_Clear();
//ssd1306_UpdateScreen();


/*
SSD1306_MARQUEE_t marqueeObj;
char demoText[]="SmartDisk II - The sound of sea ! ";
marqueeObj.text=(char *)&demoText;

marqueeObj.x=15;
marqueeObj.y=10;
marqueeObj.visibleWidth=100;
marqueeObj.Color=White;
marqueeObj.inverted=1;

ssd1306_marqueeInit(&marqueeObj,Font_6x8);
memset(marqueeObj.renderBuffer,0x00,128);

ssd1306_marquee_build_text_bitmap(&marqueeObj);
ssd1306_marquee_display(&marqueeObj);
ssd1306_UpdateScreen();
while(1){
  ssd1306_marquee_display(&marqueeObj);
  ssd1306_UpdateScreen();
  HAL_Delay(15);
};
*/

 
  EnableTiming();                                                           // Enable WatchDog to get precise CPU Cycle counting
 
  //TIM1->PSC=1000;

  int T4_DIER=0x0;
  T4_DIER|=TIM_DIER_CC2IE;
  T4_DIER|=TIM_DIER_UIE;
  TIM4->DIER|=T4_DIER;   

  int dier=0x0;
  dier|=TIM_DIER_CC1IE;
  dier|=TIM_DIER_UIE;
  TIM3->DIER=dier;
  
  pSdEject();
 
  ptrDeviceEnableIRQ(DEVICE_ENABLE_Pin);

  dirChainedList = list_new();                                              // ChainedList to manage File list in current path                                                     

  char * imgFile=NULL;

  // --------------------------------------------------------------------
  // Load configuration variable
  // --------------------------------------------------------------------

  if (fres == FR_OK){

    if (loadConfigFile()==RET_ERR){
      log_error("loading configFile error");
      setConfigFileDefaultValues();
      if (saveConfigFile()!=RET_OK){
        log_error("Error in saving default to configFile");
      }else{
        log_info("init default and save configFile");
      }
    }else{
      
      getFavorites();
      buildLstFromFavorites();
      
      if (getConfigParamUInt8("bootMode",&bootMode)==RET_ERR)
        log_warn("error getting bootMode from Config");
      else 
        log_info("bootMode=%d",bootMode);

      if (getConfigParamUInt8("emulationType",&emulationType)==RET_ERR)
        log_warn("error getting emulationType from Config");
      else 
        log_info("emulationType=%d",emulationType);
      
      if (getConfigParamUInt8("bootImageIndex",&bootImageIndex)==RET_ERR)
        log_warn("warning getting bootImageIndex from Config");
      else 
        log_info("bootImageIndex=%d",bootImageIndex);

      
      if (getConfigParamUInt8("soundEffect",&flgSoundEffect)==RET_ERR)
        log_warn("error getting soundEffect from Config");
      else 
        log_info("soundEffect=%d",flgSoundEffect);

      if (getConfigParamUInt8("screenSaver",&flgScreenSaver)==RET_ERR)
        log_warn("error getting screenSaver from Config");
      else 
        log_info("screenSaver=%d",flgScreenSaver);
      
      if (getConfigParamUInt8("weakBit",&flgWeakBit)==RET_ERR)
        log_warn("error getting weakBit from Config");
      else 
        log_info("weakBit=%d",flgWeakBit);

      if (getConfigParamUInt8("smartloaderEmulationType",&smartloaderEmulationType)==RET_ERR)
        log_warn("error getting smartloaderEmulationType from Config");
      else 
        log_info("smartloaderEmulationType=%d",smartloaderEmulationType);

    }

    imgFile=(char*)getConfigParamStr("lastFile");
    char * tmp=(char*)getConfigParamStr("currentPath");
    
    if (tmp)
      sprintf(currentFullPath,"%s",tmp);
    else
      currentFullPath[0]=0x0;
    
    if (imgFile!=NULL){
      log_info("lastFile:%s",imgFile);
      sprintf(tmpFullPathImageFilename,"%s",imgFile);
    }
  
  }else{
    log_error("Error mounting sdcard %d",fres);
  }

  // --------------------------------------------------------------------
  // Manage the case for the OLED Screen Saver
  // --------------------------------------------------------------------

  if (flgScreenSaver==1){
    log_info("Starting ScreenSaver timer");
    HAL_TIM_OC_Start_IT(&htim9,TIM_CHANNEL_1);
  }


  // --------------------------------------------------------------------
  // Prepate emulation mode
  // --------------------------------------------------------------------
  //emulationType=DISKII;
  //emulationType=SMARTPORTHD;
  if (emulationType==SMARTLOADER)
    preBootSmartport=1;

  setEmulationPtr(emulationType);

  // --------------------------------------------------------------------
  // Init emulation
  // --------------------------------------------------------------------

  //switchPage(FSSELECTIMAGE,0);
  //while(1);
  ptrInit();
  
  //SmartPortInitWithImage("/smartport/Total.Replay 240909.po");
  // --------------------------------------------------------------------
  // Execute emulation
  // --------------------------------------------------------------------

  ptrMainLoop();

while(1){
  if (flgSwitchEmulationType==1){
    flgSwitchEmulationType=0;
    /*if (emulationSubType==SMARTPORTHD){
      ptrMainLoop=SmartPortMainLoop;
      emulationSubType=DISKII;
      setEmulationPtr(DISKII);
      ptrInit();
      log_info("Switching from DiskII to Smartport HD emulation");
    }else if(emulationSubType==DISKII){*/
      ptrMainLoop=SmartPortMainLoop;
      emulationSubType=SMARTPORTHD;
     
      setEmulationPtr(SMARTPORTHD);
   // }
    
      
    log_info("Starting mainLoop");
    ptrMainLoop();
  }
}
  



  /* USER CODE END 2 */

  /* Infinite loop */
}
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

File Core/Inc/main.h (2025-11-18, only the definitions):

#define PUTCHAR_PROTOTYPE int __io_putchar(int ch)
#define PUTCHAR_PROTOTYPE int fputc(int ch, FILE *f)
#define BTN_DOWN_Pin GPIO_PIN_13
#define BTN_DOWN_GPIO_Port GPIOC
#define BTN_DOWN_EXTI_IRQn EXTI15_10_IRQn
#define BTN_UP_Pin GPIO_PIN_14
#define BTN_UP_GPIO_Port GPIOC
#define BTN_UP_EXTI_IRQn EXTI15_10_IRQn
#define BTN_ENTR_Pin GPIO_PIN_15
#define BTN_ENTR_GPIO_Port GPIOC
#define BTN_ENTR_EXTI_IRQn EXTI15_10_IRQn
#define STEP0_Pin GPIO_PIN_0
#define STEP0_GPIO_Port GPIOA
#define STEP0_EXTI_IRQn EXTI0_IRQn
#define STEP1_Pin GPIO_PIN_1
#define STEP1_GPIO_Port GPIOA
#define STEP1_EXTI_IRQn EXTI1_IRQn
#define STEP2_Pin GPIO_PIN_2
#define STEP2_GPIO_Port GPIOA
#define STEP2_EXTI_IRQn EXTI2_IRQn
#define STEP3_Pin GPIO_PIN_3
#define STEP3_GPIO_Port GPIOA
#define STEP3_EXTI_IRQn EXTI3_IRQn
#define DEVICE_ENABLE_Pin GPIO_PIN_4
#define DEVICE_ENABLE_GPIO_Port GPIOA
#define DEVICE_ENABLE_EXTI_IRQn EXTI4_IRQn
#define WR_DATA_Pin GPIO_PIN_7
#define WR_DATA_GPIO_Port GPIOA
#define RD_DATA_Pin GPIO_PIN_0
#define RD_DATA_GPIO_Port GPIOB
#define WR_PROTECT_Pin GPIO_PIN_2
#define WR_PROTECT_GPIO_Port GPIOB
#define BTN_RET_Pin GPIO_PIN_12
#define BTN_RET_GPIO_Port GPIOB
#define BTN_RET_EXTI_IRQn EXTI15_10_IRQn
#define SD_EJECT_Pin GPIO_PIN_13
#define SD_EJECT_GPIO_Port GPIOB
#define DEBUG_Pin GPIO_PIN_10
#define DEBUG_GPIO_Port GPIOA
#define DEBUG2_Pin GPIO_PIN_10
#define DEBUG2_GPIO_Port GPIOB
#define _35DSK_Pin GPIO_PIN_11
#define _35DSK_GPIO_Port GPIOA
#define SELECT_Pin GPIO_PIN_8
#define SELECT_GPIO_Port GPIOB
#define SELECT_EXTI_IRQn EXTI9_5_IRQn
#define WR_REQ_Pin GPIO_PIN_9
#define WR_REQ_GPIO_Port GPIOB
#define WR_REQ_EXTI_IRQn EXTI9_5_IRQn
#define A2PWR_Pin GPIO_PIN_12
#define A2PWR_Port GPIOA
#define AB_GPIO_Port GPIOB
#define AB_Pin GPIO_PIN_8
#define RE_A_Pin GPIO_PIN_13
#define RE_A_GPIO_Port GPIOA
#define RE_A_EXTI_IRQn EXTI15_10_IRQn
#define RE_B_Pin GPIO_PIN_14
#define RE_B_GPIO_Port GPIOA
#define RE_B_EXTI_IRQn EXTI15_10_IRQn

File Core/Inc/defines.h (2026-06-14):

#define _VERSION "v0.80.37"
#define UART_BAUDRATE               460800
#define SPLASHSCREEN_DURATION       500                         // Not more than 500 otherwise IIGS will not boot"

#define MAX_FAVORITES               10

#define MAX_FILENAME_LENGTH         64
#define MAX_FULLPATH_LENGTH         256
#define MAX_PATH_LENGTH             64
#define MAX_FULLPATHIMAGE_LENGTH    320 
#define JSON_BUFFER_SIZE            2048
#define MAX_EXTFILTER_ITEM          20

#define CONFIGFILE_NAME             "/sdiskConfig.json"

#define SCREEN_MAX_LINE_ITEM        4
#define SCREEN_LINE_HEIGHT          9

#define SCREENSHOT                  0

#define RAW_SD_TRACK_SIZE           8192                            // Maximuum track size on NIC & WOZ to load from SD
#define WEAKBIT                     0

#define MAX_TRACK                   59                              // Max Number of track for a given Apple II Floppy,

#define MAX_PARTITIONS              4                               // Number of 32MB Prodos partions supported
#define SP_PKT_SIZE                 604

#define DISK_35_NUM_REGIONS         5

// SMARTPORT MESSAGE OFFSET
/*

The following packet 
shows the timing and content of a SmartPort READBLOCK call.  For further 
explanation of the structure, please see the Apple IIGS Hardware Reference and 
the Apple IIGS Firmware Reference.

-------- Sending status! --------
Source: 81 Partition ID: 81 Status code: 0
0000: FF 3F CF F3 FC FF C3 80 81 81 80 80 84 80 F0 F8 -.?.....⸮..⸮⸮.⸮..
0010: FF FF 80 FE BE C8                               -..⸮.............

Status code: 0
0000: FF FF FF FF FF C3 81 80 80 80 80 82 81 80 80 83 -.......⸮⸮⸮⸮..⸮⸮.
0010: A0 80 AA 80 C0 83 80 80 EA BE C8 C0             -.⸮.⸮..⸮⸮........


DATA            MNEMONIC  DESCRIPTION                           TIME
(SmartPort Bus)           (Relative)
_____________________________________________________________________________       Offset 
FF              SYNC      SELF SYNCHRONIZING BYTES              0                   0
3F              :         :                                     32 micro Sec.       1
CF              :         :                                     32 micro Sec.       2
F3              :         :                                     32 micro Sec.       3
FC              :         :                                     32 micro Sec.       4
FF              :         :                                     32 micro Sec.       5
C3              PBEGIN    MARKS BEGINNING OF PACKET             32 micro Sec.       6   00
81              DEST      DESTINATION UNIT NUMBER               32 micro Sec.       7   01
80              SRC       SOURCE UNIT NUMBER                    32 micro Sec.       8   02
80              TYPE      PACKET TYPE FIELD                     32 micro Sec.       9   03
80              AUX       PACKET AUXILLIARY TYPE FIELD          32 micro Sec.      10   04
80              STAT      DATA STATUS FIELD                     32 micro Sec.      11   05
82              ODDCNT    ODD BYTES COUNT                       32 micro Sec.      12   06
81              GRP7CNT   GROUP OF 7 BYTES COUNT                32 micro Sec.      13   07
80              ODDMSB    ODD BYTES MSB's                       32 micro Sec.      14   08
81              COMMAND   1ST ODD BYTE = Command Byte           32 micro Sec.      15   09
83              PARMCNT   2ND ODD BYTE = Parameter Count        32 micro Sec.      16   10
80              GRP7MSB   MSB's FOR 1ST GROUP OF 7              32 micro Sec.      17   11
80              G7BYTE1   BYTE 1 FOR 1ST GROUP OF 7             32 micro Sec.      18   12
98              G7BYTE2   BYTE 2 FOR 1ST GROUP OF 7             32 micro Sec.      19   13
82              G7BYTE3   BYTE 3 FOR 1ST GROUP OF 7             32 micro Sec.      20   14
80              G7BYTE4   BYTE 4 FOR 1ST GROUP OF 7             32 micro Sec.      21   15
80              G7BYTE5   BYTE 5 FOR 1ST GROUP OF 7             32 micro Sec.      22   16
80              G7BYTE6   BYTE 6 FOR 1ST GROUP OF 7             32 micro Sec.      23   17
80              G7BYTE7   BYTE 7 FOR 1ST GROUP OF 7             32 micro Sec.      24   18
BB              CHKSUM1   1ST BYTE OF CHECKSUM                  32 micro Sec.      25   19
EE              CHKSUM2   2ND BYTE OF CHECKSUM                  32 micro Sec.      26   20
C8              PEND      PACKET END BYTE                       32 micro Sec.      27   21
00              FALSE     FALSE IWM WRITE TO CLEAR REGISTER     32 micro Sec.      28   22
_____________________________________________________________________________

Ex of Data packet :ADC_CLOCKPRESCALER_PCLK_DIV1
0000: C3 81 80 82 80 80 86 80 86 80 80 80 A4 D9 E7 BF - ..�.��.�.���....
0010: EF C8
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

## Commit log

2024-08-27 Initial comit
    Initial commit
    [sdiskII_stm32.kicad_pcb, sdiskII_stm32.kicad_sch, sdisk_stm32_wols123.kicad_pcb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]
2024-08-29 all images working
    [sdiskII_stm32.kicad_pcb, sdiskII_stm32.kicad_sch]
2024-09-01 Code cleaning, warning suppress, casting
    [sdiskII_stm32.kicad_pcb]
2024-10-09 new realease with gerber
    [sdiskII_stm32-B_Cu.gbr, sdiskII_stm32-B_Mask.gbr, sdiskII_stm32-B_Paste.gbr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]
2024-10-16 first PCB version
2024-10-16 BTN Pin definition update
2024-10-16 stcubemx pin def update (btn)
2024-10-22 change makefile to use bootloader, CPU Freq, align TIMER config
2024-10-22 pin config & uart
2024-10-28 v0.66 NIC Driver Fix
    [main.c]
2024-10-28 v0.67 Fix Startup / Display Reset ...
    [main.c]
2024-10-29 button & function inversion
2024-10-29 button definition
2024-10-29 driver work
2024-10-30 v0.68 Fix WOZ1.0 Read
    [main.c]
2024-10-31 working on dsk driver
2024-10-31 fixing some type issues
    [display.c, main.c]
2024-11-02 fix: default configFile initialization if not exist, display adjust
    [configFile.c, display.c]
2024-11-04 fix: directory with name of 1 char not read by the emulator
    [defines.h, main.c]
2024-11-05 v0.72: ImageMenu + Fix
    [display.c, main.c, main.h]
2024-11-07 feat: buzzer timer
2024-11-07 board rev20
    [sdiskII_stm32.kicad_pcb, sdiskII_stm32.kicad_sch]
2024-11-07 board rev2
    [sdiskII_stm32.kicad_pcb, sdiskII_stm32.kicad_sch]
2024-11-09 v0.73: code refactoring + buzzer sound
    [configFile.c, defines.h, display.c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]
2024-11-09 v0.73: fixing config size
    [display.c, main.c]
2024-11-15 v0.74 - Not running
    [sdiskII_stm32.kicad_pcb]
2024-11-21 fix: v0.76 woz protection (all images working)
    [defines.h, display.c, main.c]
2024-11-21 hardware rev2 (including buzzer)
    [sdiskII_stm32-B_Cu.gbr, sdiskII_stm32-B_Mask.gbr, sdiskII_stm32-B_Paste.gbr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]
2024-11-21 kicad v2
    [sdiskII_stm32.kicad_pcb]
2024-12-22 v0.79 Smartport HD working
    [sdiskII_stm32-B_Cu.gbr, sdiskII_stm32-B_Mask.gbr, sdiskII_stm32-B_Paste.gbr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]
2024-12-24 3D print case
    [SmartDiskII Bambulab prj.3mf, SmartDiskII Case v18.f3d, SmartDiskII bottom v18.3mf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]
2024-12-24 bambulab prj
    [SmartDiskII Bambulab prj.3mf]
2024-12-26 smartport fix
    [SmartDiskII Bambulab prj.3mf, sdiskII_stm32.kicad_pcb]
2024-12-26 fix ARM Toolchain 14.2
    [defines.h, display.c, emul_smartport.c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]
2024-12-26 rev4 (aesthetic change)
    [sdiskII_stm32-B_Cu.gbr, sdiskII_stm32-B_Mask.gbr, sdiskII_stm32-B_Paste.gbr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]
2025-01-27 v0.79.3 Smartport HD, DIsk II, Case v3 display refactoring
    [SmartDiskII body v3.3mf, SmartDiskII button reset v3.3mf, SmartDiskII button v3.3mf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]
2025-02-02 v0.79.6 Fixing Smartport IIGS
    [defines.h, display.c, emul_smartport.c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]
2025-02-09 Contributed hardware
    [EVQ-Q2B02W.step, F32R-1A7H1-11031.step, RKJXT1F42001.step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]
2025-02-20 Initial upload
    Rotary encoder support buggy
    [SDISK-STM.stl, sdiskII_stm32.kicad_pcb, sdiskII_stm32.kicad_sch]
2025-02-21 RE update
    [sdiskII_stm32.kicad_pcb, sdiskII_stm32.kicad_sch]
2025-02-21 Make Filsystem fixed
    [sdiskII_stm32.kicad_pcb, sdiskII_stm32.kicad_sch]
2025-02-21 Reset on push all
    clearScreen fix
    [display.c, main.c]
2025-02-22 final v0.80.1
    [SDISK-STM.stl, sdiskII_stm32.kicad_pcb, sdiskII_stm32.kicad_sch]
2025-02-26 v0.80.3 23.02.25 v0.80.3 + [All] Code cleaning, compilation warning cleaning + [Smartport] 2MG Extension checking fixed + [2MG] Fixing 2MG mount blockCount function + [Smartport] Fixing Missing Exten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
    [defines.h, emul_disk35.c, emul_diskii.c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]
2025-02-27 + [WOZ] Correcting head / sector / region calculation + [FS] Adding "." item on every location to add future access to option
    [display.c, emul_diskii.c, main.c]
2025-03-14 fs deadlock fix
    fixing some deadlock on fs
    [emul_diskii.c]
2025-03-21 fixing Cross track sync with new reading proc
    [emul_diskii.c]
2025-03-22 v0.80.5d Smartport Nav Fix
    [defines.h, emul_diskii.c, emul_smartport.c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]
2025-03-22 fixing boot up and write protect on start up IIc & IIGS
    [main.c]
2025-03-22 IIGS & IIC Fix
    [display.c, emul_diskii.c, emul_smartport.c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]
2025-03-22 fixing checksum calculation on write
    [emul_smartport.c]
2025-03-26 A2F 0.86 fix
    [EncoderKnob.3mf]
2025-03-29 new A2F build und further adjustments
2025-04-06 display fix and 0.80.9 A2F build
    The top line of the T of the Track: was missing
2025-05-07 pcb small change v5
    [SmartDiskII body highBuzr v3.3mf, SmartDiskII body lowBuzr.3mf, SmartDiskII button 4.7.3mf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]
2025-05-19 v0.80.12 beta
    [sdiskII_stm32.kicad_pcb, sdiskII_stm32.kicad_sch]
2025-05-19 PCB Rev6
    [sdiskII_stm32-B_Cu.gbr, sdiskII_stm32-B_Mask.gbr, sdiskII_stm32-B_Paste.gbr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]
2025-05-20 v0.80.13 beta #1
    [sdiskII_stm32.kicad_pcb]
2025-07-14 fixing Smartport on IIe II+ Rev6 Hardware
    [sdiskII_stm32-B_Cu.gbr, sdiskII_stm32-B_Mask.gbr, sdiskII_stm32-B_Paste.gbr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]
2025-07-28 smartloader case comp
2025-08-11 Board rev7 beta
    [sdiskII_stm32.kicad_pcb, sdiskII_stm32.kicad_sch]
2025-08-12 v0.80.17 Alpha
    [sdiskII_stm32-B_Cu.gbr, sdiskII_stm32-B_Mask.gbr, sdiskII_stm32-B_Paste.gbr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]
2025-08-12 Board Rev7 beta 2 # Add bypass pads
    [sdiskII_stm32.kicad_pcb, sdiskII_stm32.kicad_sch]
2025-08-18 0.80.17 beta 4
    [SmartDiskII button .3mf, batch.3mf, sdiskII_stm32.kicad_pcb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]
2025-08-19 0.80.18 beta 1, fatfs0.16, screensaver, stm32 firmware 1.28.2
2025-08-19 PCB Board v7 Adjust + 3D Print Case
    [Pantalla OLED 0.96'' 128x64.stp, SmartDiskII 3D Case board v7.f3d, SmartDiskII body highBuzr v4.3mf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]
2025-08-20 Board Rev7 to test production
    [sdiskII_stm32-B_Cu.gbr, sdiskII_stm32-B_Mask.gbr, sdiskII_stm32-B_Paste.gbr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]
2025-08-22 v0.80 beta 4
    [sdiskII_stm32.kicad_pcb]
2025-10-04 v0.80.21 Fixing IIe IIc Smartport
    [defines.h, emul_smartport.c]
2025-10-21 IIc boot issue on Smartport (Bootloader issue?)
    [defines.h, main.c]
2025-10-21 Fixing Checksum on IIc & IIe Message without trailing C8 !!!!
    [defines.h, emul_smartport.c]
2025-10-27 v0.80.27 #1
    [sdiskII_stm32-B_Cu.gbr, sdiskII_stm32-B_Mask.gbr, sdiskII_stm32-B_Paste.gbr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]
2025-11-02 v0.80.29 WIP (WR not working)
    [emul_diskii.c, emul_smartport.c, main.c]
2025-11-10 v0.80.29 WIP #3 Disk Write Error speed
    [emul_diskii.c, main.c]
2025-11-16 fix buzzer when writing
    [emul_diskii.c, main.c]
2025-11-20 Smartport IIGS bootup timing fix
    [emul_smartport.c, main.c]
2026-02-05 fixing deadlock on sdcard
    [defines.h, emul_diskii.c, emul_smartport.c]

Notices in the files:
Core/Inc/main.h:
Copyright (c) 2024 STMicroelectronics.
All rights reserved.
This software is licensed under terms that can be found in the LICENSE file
